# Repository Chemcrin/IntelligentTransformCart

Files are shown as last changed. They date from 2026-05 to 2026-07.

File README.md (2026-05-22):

# 智能物流小车

基于 STM32 + 树莓派的智能物流小车项目，集成多种传感器与机械结构，实现自主导航与物料搬运功能。

## 目录结构

```
├── 代码/                 # STM32固件代码、传感器驱动、技术手册
│   ├── 陀螺仪uart/       # JY61P陀螺仪UART驱动代码
│   ├── vibe_coding/      # 姿态模块、树莓派视觉、麦轮框架设计资料
│   └── *.md              # 技术手册与设计文档
├── pi/                   # 树莓派3D模型 (SLDPRT/SLDASM/STEP)
├── PCB/                  # PCB设计文件
├── 三合一/               # 三合一模块相关文件
├── 历史建模存档/         # 旧版3D模型备份
├── 项目资料包/           # 项目参考资料
├── *.SLDPRT / *.SLDASM   # SolidWorks 机械结构模型
├── LICENSE               # MIT 许可证
└── README.md             # 本文件
```

## 硬件平台

- **主控**：STM32 系列微控制器
- **协处理器**：树莓派 4B
- **传感器**：JY61P 陀螺仪、ATK-MS53L1M 激光测距
- **执行机构**：ZDT X57 V2 步进闭环电机（Modbus-RTU）
- **机械结构**：底盘、料盘、机械臂、方形料框

## 软件架构

- **STM32 固件**：传感器数据采集、电机控制、I2C/UART 通信
- **树莓派端**：视觉识别、上位机调度
- **通信协议**：I2C (TCA9548A)、UART、Modbus-RTU

## 许可证

本项目采用 MIT 许可证。详见 [LICENSE](./LICENSE) 文件。

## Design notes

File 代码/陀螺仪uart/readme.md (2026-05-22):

# JY61P 六轴姿态传感器 UART 驱动

STM32F103C8T6 + HAL 库, 通过串口读取 JY61P 陀螺仪数据。

## 硬件连接

| JY61P 引脚 | STM32 引脚  | 功能 |
|---|---|---|
| VCC | 3.3V | 供电 |
| GND | GND | 地 |
| RX | PB10 | USART3_TX |
| TX | PB11 | USART3_RX |
| SCL | PB6 | 本驱动未使用 |
| SDA | PB7 | 本驱动未使用 |

## 快速开始

### 1. CubeMX 配置

- **USART3**: PB10=TX, PB11=RX, **115200-8-N-1**, NVIC 开启 USART3 全局中断
- 可选 USART1 (PA9=TX, 115200) 用于 printf 调试
- SysTick 必须开启

### 2. 添加文件

- `jy61p.h` → `Inc/`
- `jy61p.c` → `Src/`

### 3. 修改 main.c

```c
#include "jy61p.h"

extern UART_HandleTypeDef huart3;

/* 必须加入此回调 */
void HAL_UART_RxCpltCallback(UART_HandleTypeDef *huart)
{
    if (huart->Instance == USART3) {
        static uint8_t ch;
        HAL_UART_Receive_IT(huart, &ch, 1);
        JY61P_FeedByte(ch);
    }
}

int main(void)
{
    HAL_Init();
    SystemClock_Config();
    MX_GPIO_Init();
    MX_USART3_UART_Init();

    JY61P_StartRecv(&huart3);   /* 启动接收 */

    while (1) {
        float roll, pitch, yaw;
        if (JY61P_GetAngle(&roll, &pitch, &yaw)) {
            /* roll, pitch, yaw 为角度值(°) */
        }
        HAL_Delay(10);
    }
}
```

## UART 协议说明

模块上电后以 **100Hz** 速率主动输出数据包, 每包 **11 字节**:

| 偏移 | 内容 |
|---|---|
| 0 | 0x55 帧头 |
| 1 | 类型: 0x51=加速度, 0x52=角速度, 0x53=姿态角 |
| 2~9  | 4 个 int16 (小端): 3 轴数据 + 温度 |
| 10 | 校验和 (前 10 字节之和的低 8 位) |

转换公式: `实际值 = 原始值 / 32768 × 量程`

| 类型 | 量程 | 单位 |
|---|---|---|
| 加速度 | ±16 | g |
| 角速度 | ±2000 | °/s |
| 姿态角 | ±180 | ° |

## API 参考

### 初始化

| 函数 | 说明 |
|---|---|
| `JY61P_UART_Init(&huart)` | 手动初始化 USART3 (CubeMX 已生成则跳过) |
| `JY61P_StartRecv(&huart)` | 启动中断接收, 调用一次 |

### 数据读取

| 函数 | 说明 |
|---|---|
| `JY61P_Ready()` | 返回就绪标志位 |
| `JY61P_GetData(&data)` | 取出全部数据 |
| `JY61P_GetAngle(&r, &p, &y)` | 仅取姿态角, 返回 1=有新数据 |

### 配置

| 函数 | 说明 |
|---|---|
| `JY61P_ZeroYaw(&huart)` | Z 轴归零 |
| `JY61P_Calibrate(&huart)` | 加速度计校准 |

### 数据结构

```c
typedef struct {
    float ax, ay, az;       /* 加速度 (g)   */
    float gx, gy, gz;       /* 角速度 (°/s) */
    float roll, pitch, yaw; /* 姿态角 (°)   */
    float temp;             /* 温度 (°C)    */
} JY61P_Data;
```

## 注意事项

- **USART3 中断必须开启**, 否则 `HAL_UART_RxCpltCallback` 不会触发
- **Z 轴漂移**: 6 轴传感器无磁力计, Yaw 由角速度积分得出, 长时间运动后漂移; Roll/Pitch 有重力约束不会漂移
- **配置寄存器**如需精确控制回传速率等参数, 建议用 PC 端 WitMotion 上位机软件配置后保存到模块 Flash
- 若模块无输出, 检查波特率是否为 115200 (部分旧版固件默认 9600)

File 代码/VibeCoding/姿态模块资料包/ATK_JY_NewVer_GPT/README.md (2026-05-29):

# ATK_JY_NewVer_GPT

STM32F103C8T6 / STM32C8T6 传感器姿态与距离感知代码包。

- JY61P：I2C1 读取姿态、角速度、加速度，含上电静止校准、yaw 互补滤波、车体系映射。
- ATK-MS53L1M / VL53L1X：I2C1 读取距离，含中值滤波、滑动平均、跳变剔除、近距离优先。
- Board App：提供 `Board_App_Init()`、`Board_App_Loop()`、`SENSOR_Snapshot_t` 快照。

导入和 IOC 配置见：`Docs/项目说明_导入与IOC配置.md`。

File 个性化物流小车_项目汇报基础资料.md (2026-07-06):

# 个性化物流小车——项目汇报基础资料

> 本文档基于项目推进过程资料、技术文档、工程审查报告及多个版本的代码迭代整理而成，用于指导后续 PPT 制作。
> 整理时间：2026-07-05 | 整理人：星尘光 StaRacy

---

## 一、项目概述

### 1.1 项目名称
智能物流搬运小车（个性化物流小车 / Intelligent Transform Cart）

### 1.2 项目定位
基于 STM32 + 树莓派的智能物流小车，实现自主导航与物料搬运功能，面向物流仓储场景的智能化解决方案。

### 1.3 硬件平台总览

| 模块 | 型号/规格 | 接口方式 | 功能定位 |
|---|---|---|---|
| **主控 MCU** | STM32F103C8T6 | — | 底层运动控制、传感器数据采集、电机驱动 |
| **协处理器** | Raspberry Pi 4B | USART2（通过 CH340N） | 视觉识别、上位机调度、路径规划 |
| **底盘电机 ×4** | ZDT-X42-V2 闭环步进电机 | RS485 / Modbus-RTU（USART1） | 四轮独立驱动 |
| **轮组** | 75mm 麦克纳姆轮（X 形布局） | — | 全向移动 |
| **姿态传感器** | JY61P 陀螺仪 / IMU | I2C1 | 航向角测量、直线纠偏 |
| **激光测距** | ATK-MS53L1M / VL53L1X | I2C1 | 避障与距离检测（项目后期移除） |
| **通信** | RS485 半双工总线 + USART1 | — | 电机 Modbus 通信 |
| **调试/控制** | USART2（CH340N → TypeC） | — | 树莓派上下位机通信 |

### 1.4 软件架构概览

```
┌─────────────────────────────────────────────────┐
│                  主循环 (10ms)                    │
├─────────────────────────────────────────────────┤
│  传感器读取 → IMU 更新 → 路线执行 → 电机下发      │
│  (sensors.c)  (imu_app.c)  (competition_route.c) │
│                        → (chassis_control.c)     │
│                        → (mecanum_kinematics.c)   │
│                        → (motor_manager.c)       │
│                        → (zdt_x42_modbus.c)      │
│                        → (modbus_rtu.c)          │
└─────────────────────────────────────────────────┘
```

项目采用**模块化分层设计**，从高层次到底层依次为：

1. **路线执行层**（`competition_route`）：按预设步骤执行路径
2. **底盘控制层**（`chassis_control`）：航向修正、速度规划
3. **运动学层**（`mecanum_kinematics`）：麦轮正/逆运动学解算
4. **电机管理层**（`motor_manager`）：四电机命令缓存与调度
5. **协议层**（`zdt_x42_modbus` + `modbus_rtu`）：Modbus 帧封装与 RS485 收发

---

## 二、项目推进过程

### 第一阶段：项目启动与硬件选型（2026-05-22 前）

- 确定项目方向：物流搬运场景的智能小车
- 硬件选型：STM32F103C8T6 主控、树莓派 4B、ZDT-X42-V2 步进电机、麦克纳姆轮
- 建立项目目录结构，初始化 Git 仓库
- 完成核心传感器（JY61P 陀螺仪、ATK-MS53L1M 激光）的技术调研

### 第二阶段：基础驱动开发与传感器驱动（2026-05-22 ~ 2026-05-29）

- 完成 JY61P 陀螺仪 UART 驱动开发与验证
- 完成 ATK-MS53L1M / VL53L1X 激光测距驱动移植
- 建立传感器数值读取框架
- 完成硬件平台技术手册 V1~V3 迭代

**关键节点：**
- v0.1.0（2026-05-22）：项目初始化，陀螺仪 UART 驱动、PCB 目录搭建
- v0.1.1（2026-05-29）：代码重构，新增 STM32 传感器驱动库，麦轮运动学框架

### 第三阶段：麦轮底盘控制开发（2026-05-29 ~ 2026-06-09）

- 完成麦轮逆运动学解算模块（`mecanum_kinematics.c`）
- 完成 ZDT 电机 Modbus-RTU 协议封装（`zdt_x42_modbus.c`）
- 完成四电机管理与同步控制（`motor_manager.c`）
- 完成底盘控制调度层（`chassis_control.c`）
- 完成直线闭环 PID 控制器

**此阶段遇到的主要困难：**

| 问题 | 表现 | 解决方案 |
|---|---|---|
| USART 分配错误 | 电机驱动被误分配到 USART3，与 PCB 硬件设计（USART1）不符 | 审查后全部迁移到 USART1 |
| 系统时钟配置错误 | 未启用 PLL，系统时钟仅运行在 8MHz（理论最高 72MHz） | 后续需改为 HSE+PLL=72MHz |
| RS485 方向控制 | 开发板未引出方向控制 GPIO 引脚 | 保持硬件自动收发模式，不添加 GPIO 控制 |
| 电机反馈读取为空 | `MotorManager_UpdateFeedback()` 函数为空实现 | 后续依据"只发不收"策略移除空函数 |

### 第四阶段：工程审查与修复（2026-06-09 ~ 2026-06-17）

- 第一轮项目审查（2026-06-09）：发现 USART 分配错误、时钟配置问题、栈空间不足等
- 第二轮项目审查（2026-06-09）：修复 USART1 迁移，调整参数
- 第三轮工程纠错（2026-06-16~17）：工程变量规范化，移除测试残留

**主要变更：**
- 电机串口从 USART3 迁移至 USART1（与 PCB 硬件一致）
- 移除临时测试模块（`uart3_sensor_stream_temp`、`bringup_mode`）
- 新增 CSV 数据调试输出功能
- 新增树莓派远程命令协议框架
- 文档统一与工程简化

### 第五阶段：固定路线与功能集成（2026-06-17 ~ 当前）

- 完成固定路线执行模块（`competition_route`）
- 实现 12 步比赛路线（前进、横移、旋转、停止）
- 新增 IMU 辅助直线纠偏功能
- 移除激光模块（由于编译依赖问题及硬件限制）
- 实现串口信号共享调试

**当前最新工程状态：**
- 最新工程版本：`smart_logistics_car_integrated_route_2026-06-17`
- 运行模式：`FIXED_ROUTE_STANDALONE_ENABLE = 1U`（独立固定路线模式）
- 路线控制：开环时间控制（后续可升级为 IMU 闭环旋转）

---

## 三、现有可实现功能

### 3.1 基础运动功能 ✅

| 功能 | 状态 | 说明 |
|---|---|---|
| 上电自动运行固定路线 | **可用** | 200ms 启动等待后自动开始 |
| 前进 | **可用** | 默认 0.18 m/s |
| 后退 | **可用** | 默认 0.18 m/s |
| 左/右横移 | **可用** | 默认 0.14 m/s |
| 原地旋转 | **可用** | 开环时间控制，默认 0.45 rad/s |
| 停止 | **可用** | 路线结束或手动停止 |
| 四轮速度解算 | **可用** | 麦轮逆运动学，等比限幅 |
| 四电机同步使能与速度下发 | **可用** | Modbus 单播 + 广播同步触发 |

### 3.2 传感器与闭环功能 ⚡

| 功能 | 状态 | 说明 |
|---|---|---|
| JY61P 陀螺仪读取 | **代码就绪，当前独立模式下未启用** | 支持 yaw/pitch/roll、三轴加速度、三轴角速度 |
| IMU 软件零偏校准 | **代码就绪** | 静止 200 样本自动校准 |
| IMU 航向融合 | **代码就绪** | 陀螺积分 + 模块 yaw 互补修正 |
| 直线航向纠偏 | **部分启用** | 新增直线段 yaw 闭环纠偏 |
| 激光测距 | **已移除** | 因编译依赖和硬件限制移除 |
| 电机速度反馈 | **已放弃** | 硬件 RS485 不支持接收，改为"只发不收"策略 |

### 3.3 通信与控制功能 📡

| 功能 | 状态 | 说明 |
|---|---|---|
| Modbus-RTU 电机控制 | **可用** | 发送使能、速度、停止指令 |
| CSV 串口调试输出 | **可用** | 10Hz 全量传感器数据流 |
| 树莓派遥控协议 | **代码就绪** | USART2 命令协议：VEL、STOP、STAT?、IMU? 等 |
| 传感器快照系统 | **可用** | 统一传感器数据接口 `Sensor_GetSnapshot()` |

---

## 四、独具特色功能

### 4.1 麦克纳姆轮全向移动

采用 X 形布局麦克纳姆轮，配合精确的逆运动学解算（`Mecanum_InverseKinematics`），实现：

- **前进/后退**：四轮同向同速
- **左右横移**：前后轮差速
- **原地旋转**：对角同向、同侧反向
- **任意矢量运动**：任意方向平移 + 旋转的复合运动

**关键技术参数：**
- 轮径：75mm
- 轮距：320mm
- 轴距：220mm
- 最大平移速度：0.60 m/s
- 最大旋转角速度：1.50 rad/s
- 加速度限制：2000 RPM/s

### 4.2 Y 轴速度规划与路线

代码中包含完整的固定路线规划，支持：
- **直线前进/后退距离控制**：速度 × 时间换算
- **横移/斜向运动**：vx/vy 任意比例组合
- **原地旋转角度控制**：开环时间控制
- **复合运动**：平移 + 旋转可同时叠加

### 4.3 模块化传感器架构

项目的传感器驱动采用分层设计，具有良好可扩展性：

```
传感器硬件驱动层（jy61p.c / atk_ms53l1m.c）
        ↓
传感器应用层（imu_app.c / laser_app.c）
        ↓
传感器集成层（sensors.c） → Sensor_GetSnapshot()
        ↓
传感器桥接层（sensor_bridge.c）→ 统一数据类型
```

这种架构使更换传感器或增减模块非常方便，仅需修改对应驱动文件即可。

### 4.4 实时 CSV 调试数据流

项目提供了独立的 CSV 调试数据输出功能，可通过 USART1 实时回传以下数据：

```
时间戳(ms), 加速度X(g), 加速度Y(g), 加速度Z(g),
角速度X(dps), 角速度Y(dps), 角速度Z(dps),
Roll(°), Pitch(°), Yaw(°)
```

- 输出频率：10Hz（不干扰主控制周期）
- 条件编译控制：`CSV_DEBUG_ENABLE` 一键开关
- 可用于示波器、Excel 导入或上位机实时可视化

### 4.5 软件定义的控制模式切换

通过宏定义实现灵活的控制模式切换：

| 宏开关 | 作用 |
|---|---|
| `FIXED_ROUTE_STANDALONE_ENABLE` | 独立固定路线模式 / 完整传感器+树莓派模式 |
| `COMPETITION_ROUTE_AUTO_START` | 上电自动启动 / 等待外部信号启动 |
| `COMPETITION_ROUTE_USE_IMU_ROTATION` | 旋转开环时间控制 / IMU 闭环角度控制 |
| `CSV_DEBUG_ENABLE` | 调试数据流开启/关闭 |

---

## 五、项目推进过程中遇到的困难与解决方案

### 5.1 硬件层面

| 困难 | 表现 | 解决方案 |
|---|---|---|
| **RS485 半双工只有发送能力** | 硬件未引出 RS485 方向控制 GPIO，无法接收电机状态回传 | 采用"只发不收"开环控制策略，放弃电机反馈读取 |
| **激光模块编译依赖缺失** | VL53L1X API 库未纳入工程，导致编译错误 | 移除激光模块，取消激光避障/急停保护 |
| **开发板 C 口连接 UART2** | TypeC 接口通过 CH340N 连接到 USART2，非直连 | 配置 USART2 与树莓派通信，波特率 115200 |

### 5.2 软件层面

| 困难 | 表现 | 解决方案 |
|---|---|---|
| **USART 分配错误** | 电机驱动代码被错误分配至 USART3，与 PCB（USART1）不符 | 审查后迁移至 USART1，确保与硬件一致 |
| **系统时钟 8MHz** | 未配置 PLL，CPU 仅运行在 1/9 理论性能 | 后续需改为 HSE+PLL=72MHz |
| **上电自动行驶安全隐患** | Standalone 模式下 200ms 后自动启动路线 | 开发调试时关闭 AUTO_START，比赛时开启 |
| **栈空间不足** | 链接脚本仅分配 1024 字节栈空间 | 增大至 2048 字节 |
| **多套传感器快照结构冗余** | `SENSOR_Snapshot_t` 与 `SensorSnapshot_t` 重复 | 可统一为一套结构体 |
| **Vibe Coding 代码质量问题** | 部分提示词生成的代码存在逻辑瑕疵 | 通过多轮工程审查+修复的方式持续改进 |

### 5.3 工程管理层面

| 困难 | 表现 | 解决方案 |
|---|---|---|
| **文档版本不统一** | 多个版本的硬件手册、设计文档并行 | 统一使用 V3 版硬件手册作为最高标准 |
| **临时测试模块残留** | `uart3_sensor_stream_temp`、`bringup_mode` 等模块未清理 | 审查后逐一清理，干净工程归档 |
| **变量命名不规范** | 不同模块中变量命名风格不一 | 生成工程变量总览文档，后续统一规范 |

---

## 六、项目成果总结

### 6.1 完成度评估

| 维度 | 完成度 | 说明 |
|---|---|---|
| 底盘运动控制 | **90%** | 麦轮运动学、四电机同步、速度规划已完成 |
| 传感器系统 | **70%** | IMU 驱动就绪、闭环纠偏部分启用；激光已移除 |
| 通信链路 | **60%** | Modbus 电机控制已完成；树莓派协议代码就绪但未完全联调 |
| 路线执行 | **85%** | 固定路线按时间控制可用，暂未启用 IMU 闭环旋转 |
| 功能调试 | **75%** | CSV 调试、工程审查、参数调优基本完成 |

### 6.2 可展示亮点

1. **四轮独立控制**：四个 ZDT-X42-V2 步进电机通过 RS485 总线独立寻址、同步控制
2. **全向移动能力**：麦克纳姆轮配合精确运动学解算，实现任意方向平移和原地旋转
3. **模块化软件架构**：传感器→控制→通信严格分层，代码可维护性强
4. **丰富的调试手段**：CSV 数据流、状态回传、串口命令调试
5. **完整的版本控制**：Git 全程追踪，CHANGELOG 定期维护

### 6.3 待完善方向

1. **系统时钟修复**：启用 HSE + PLL 至 72MHz
2. **IMU 闭环旋转**：启用 `COMPETITION_ROUTE_USE_IMU_ROTATION`，提高旋转精度
3. **树莓派联调**：完成 USART2 命令协议的全链路验证
4. **场地实测**：在实际比赛场地上标定路线参数
5. **视觉识别集成**：通过树莓派摄像头实现物料识别与定位

---

## 七、附录：目录结构与关键文件索引

### 项目源码目录（主要部分）

```
smart_logistics_car_integrated/
├── Core/
│   ├── Inc/                    # 头文件
│   │   ├── config.h            # 全局配置宏
│   │   ├── mecanum.h           # 麦轮 API
│   │   ├── mecanum_kinematics.h # 运动学解算
│   │   ├── mecanum_config.h    # 运动参数配置
│   │   ├── mecanum_types.h     # 数据类型定义
│   │   ├── chassis_control.h   # 底盘控制
│   │   ├── motor_manager.h     # 电机管理
│   │   ├── modbus_rtu.h        # Modbus 协议
│   │   ├── zdt_x42_modbus.h    # ZDT 电机协议
│   │   ├── jy61p.h             # JY61P 驱动
│   │   ├── imu_app.h           # IMU 应用层
│   │   ├── sensors.h           # 传感器集成
│   │   ├── sensor_bridge.h     # 传感器桥接
│   │   └── straight_control.h  # 直线闭环控制
│   └── Src/                    # 源文件
│       ├── main.c              # 主程序入口
│       ├── mecanum_kinematics.c
│       ├── mecanum.c
│       ├── chassis_control.c
│       ├── motor_manager.c
│       ├── modbus_rtu.c
│       ├── zdt_x42_modbus.c
│       ├── jy61p.c
│       ├── imu_app.c
│       ├── sensors.c
│       ├── sensor_bridge.c
│       └── straight_control.c
├── UserModules/
│   ├── competition_route/      # 固定路线执行器
│   └── remote_cmd/             # 树莓派远程命令协议
├── Drivers/
│   └── VL53L1X/                # VL53L1X API（已被移除）
├── Docs/                       # 项目文档
├── Templates/                  # 代码模板
└── Debug/                      # 编译输出
```

### 关键文档索引

| 文档 | 位置 | 用途 |
|---|---|---|
| README.md | 项目根目录 | 项目简介与目录结构 |
| CHANGELOG.md | 项目根目录 | 版本更新记录 |
| 硬件平台技术手册 V3 | `代码/` | 硬件设计最高标准 |
| 麦轮运动控制系统设计文档 5Pro | `代码/` | 运动控制系统详细设计 |
| 工程审查报告 2026-06-09 | `VibeCoding/工程纠错/` | 第一轮代码审查 |
| 智能物流小车工程审查报告 | `VibeCoding/Docs/` | 第二轮详细审查 |
| 628 问题审查 | `VibeCoding/工程纠错/` | 工程现状与问题梳理 |
| 629 工程整改指南 | `VibeCoding/工程纠错/` | 问题修复指导 |
| 工程变量总览 2026-06-16 | `VibeCoding/工程纠错/` | 变量命名规范 |

---

*本文档由星尘光 StaRacy 于 2026-07-05 整理，基于项目推进过程资料、多个版本的技术文档与工程审查报告综合编写。*

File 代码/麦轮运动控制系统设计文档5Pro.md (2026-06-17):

# 麦轮运动控制系统技术设计文档

项目：智能物流搬运小车移动系统  
平台：STM32C8T6，STM32CubeIDE，HAL 库  
执行器：4 × ZDT-X42-V2 闭环步进电机，RS485 总线，Modbus-RTU 速度控制  
传感器：JY61P 陀螺仪，ATK-MS53L1M 激光测距传感器  
版本：V1.0

---

## 0. 文档目标与设计边界

本文档回答移动系统开发中最关键的工程问题：

1. **4 个电机共用一条 RS485 总线时如何区分和同步控制？**
2. **不使用 PWM、只用 Modbus 速度寄存器时，主控侧闭环应如何设计？**
3. **X 形麦克纳姆轮如何从小车期望速度分解到 4 个电机 RPM？**
4. **如何利用 JY61P 和 ATK-MS53L1M 提升直线、转向和到达目标的稳定性？**
5. **STM32 HAL 工程如何划分外设、任务周期、通信优先级和安全停机逻辑？**

本文档不输出完整可编译 C 源码，但给出后续实现需要的寄存器、帧结构、函数原型、伪代码、状态机和关键参数。

### 0.1 资料依据与一致性说明

压缩包中电机资料包括：

- `电机相关资料/说明书/ZDT_X57_V2 Modbus-RTU指令说明.pdf`
- `电机相关资料/说明书/ZDT_X57_V2步进闭环驱动说明书Rev1.0.pdf`
- `电机相关资料/STM32F1例程/串口_RS232_RS485通讯控制`

虽然 PDF 文件名为 `ZDT_X57_V2`，说明书封面明确标注 **X28 / X35 / X42 / X57 通用**，因此可作为 ZDT-X42-V2 通信与控制设计依据。

资料中与本项目直接相关的配置点：

| 项目 | 结论 |
| --- | --- |
| 通信方式 | RS485，总线式半双工 |
| 协议 | Modbus-RTU，需在驱动器 `Checksum` 菜单选择 `Modbus` |
| 波特率 | 默认 115200，8N1；可在 `UartBaud` 菜单修改 |
| 通信端口复用 | `P_Serial` 菜单需设为 `UART_FUN` |
| 地址 | 默认地址 1，可设 1-255，0 为广播地址 |
| 接线 | PA9(TX)、PA10(RX) 通过 RS485 模块连接；驱动器端 `R/A/H` 接 RS485 A，`T/B/L` 接 RS485 B；按驱动器实物丝印/手册最终核对 |
| 控制方式 | 不使用 PWM；速度、使能、停止、同步触发均通过 Modbus 寄存器完成 |

> 注意：官方例程中有提醒“两条命令之间发送需要延迟 1-10 ms”。对 Modbus-RTU 来说标准帧间隔只要求大于 3.5 个字符时间，但工程实现建议保守加入 1-2 ms 总线保护间隔，调试稳定后再缩短。

### 0.2 机械参数

| 参数 | 符号 | 数值 |
|---|---:|---:|
| 麦克纳姆轮直径 | `D` | 75 mm = 0.075 m |
| 麦克纳姆轮半径 | `r = D / 2` | 37.5 mm = 0.0375 m |
| 单轮厚度 | - | 33 mm |
| 左右轮中心间距 / 轮距 | `W` | 320 mm = 0.320 m |
| 前后轮中心间距 / 轴距 | `L` | 220 mm = 0.220 m |
| 麦轮旋转耦合臂长 | `K = (L + W) / 2` | 0.270 m |
| 轮周长 | `C = πD` | 0.23562 m |

这里将用户给出的轮距、轴距视为左右轮接触中心、前后轮接触中心之间的距离。若后续机械测量发现轮距定义不是轮接触中心距，应重新修正 `W`，否则旋转角速度分解会有比例误差。

---

## 1. 问题一：4 个电机共用一条 RS485 总线，如何寻址和同步？

### 1.1 总线上的 4 个电机如何区分？

RS485 只是物理层，不能自动区分设备。4 个电机在同一条 RS485 总线上共存时，必须依靠 **Modbus-RTU 从机地址**区分目标电机。该机制与 I²C 设备地址类似：主控发送的每一帧都带有 `Slave Address`，只有地址匹配的驱动器响应和执行。

驱动器地址规则：

- 默认地址：`1`
- 可设置范围：`1-255`
- `0`：广播地址，不可设置为电机自身地址
- 广播地址用于让所有驱动器同时接收命令；Modbus 广播不应等待从机回复

建议本项目地址分配如下：

| 轮号 | 位置 | 建议从机地址 | 变量名 |
|---:|---|---:|---|
| 1 | 前左轮 FL | `0x01` | `MOTOR_ADDR_FL` |
| 2 | 前右轮 FR | `0x02` | `MOTOR_ADDR_FR` |
| 3 | 后左轮 RL | `0x03` | `MOTOR_ADDR_RL` |
| 4 | 后右轮 RR | `0x04` | `MOTOR_ADDR_RR` |

#### 地址设置方法

优先使用驱动器 OLED 菜单逐台设置：

1. 只给第 1 个电机上电，进入 `ID_Addr`，设为 `1`。
2. 只给第 2 个电机上电，设为 `2`。
3. 只给第 3 个电机上电，设为 `3`。
4. 只给第 4 个电机上电，设为 `4`。
5. 全部接入总线后，主控分别读取 1-4 地址验证通信。

如果使用 Modbus 修改地址，必须保证总线上同一时刻只有一个默认地址相同的电机在线，否则多个默认地址 `1` 的电机会同时响应，导致总线冲突。修改地址寄存器如下：

| 功能 | 功能码 | 起始寄存器 | 寄存器数量 | 数据格式 |
|---|---:|---:|---:|---|
| 修改 ID 地址 | `0x10` | `0x00A2` | `0x0002` | Reg1=`0x4B + 是否存储`，Reg2=`地址 + 0x00` |

示例：将地址 `1` 修改为 `2` 并存储，帧体为：

```text
01 10 00 A2 00 02 04 4B 01 02 00 CRC_L CRC_H
```

其中 `01` 为“是否存储”。CRC 不建议手工硬编码，应由统一的 Modbus CRC16 函数计算。

---

### 1.2 Modbus-RTU 帧基本结构是什么？

所有 Modbus-RTU 帧采用以下结构：

```text
+-------------+---------------+-------------------+--------------+
| 从机地址     | 功能码          | 数据区              | CRC16        |
| 1 byte      | 1 byte        | N bytes           | CRC_L CRC_H  |
+-------------+---------------+-------------------+--------------+
```

关键规则：

1. CRC 为 Modbus CRC16，多项式 `0xA001`，初值 `0xFFFF`。
2. 帧尾发送顺序是 `CRC_L` 再 `CRC_H`。例如读取 1 号电机实时转速：

```text
01 04 00 44 00 02 31 DE
```

上述帧的 CRC 数值为 `0xDE31`，发送顺序为 `31 DE`。

3. 16 bit 寄存器内部按 Modbus 常规高字节在前，即 `Hi` 后 `Lo`。
4. 资料说明所有 32 bit 数据先传低字、再传高字，主要影响位置角度等 32 bit 字段；速度模式本身只使用 16 bit 速度字段。
5. 本项目主要用到的功能码：

| 功能码 | 含义 | 用途 |
|---:|---|---|
| `0x04` | 读输入寄存器 | 读取实时转速、实时位置、系统状态 |
| `0x06` | 写单个寄存器 | 清零、校准等简单命令，可选 |
| `0x10` | 写多个寄存器 | 速度模式、使能、同步触发、修改参数 |

---

### 1.3 单个电机速度指令如何组织？

速度模式控制使用 `0x10` 写多个寄存器：

| 字段 | 值 |
|---|---:|
| 功能码 | `0x10` |
| 起始寄存器 | `0x00E6` |
| 寄存器数量 | `0x0004` |
| 字节数 | `0x08` |

4 个寄存器含义如下：

| 寄存器 | 含义 | 数据建议 |
|---|---|---|
| Reg1 | 方向 | `0x0000` = CW，`0x0001` = CCW |
| Reg2 | 加速度 | 单位 `RPM/s`，`uint16_t` |
| Reg3 | 速度 | 单位按 Modbus 速度模式表为 `RPM`，`uint16_t` |
| Reg4 | 多机同步标志 + 保留字节 | `0x0000` = 立即执行；`0x0100` = 缓存等待同步触发 |

> 实施校验点：同一份 Modbus 文档在位置模式中明确写明“速度和位置角度要放大 10 倍输入”，而速度模式表只标注 `速度(RPM)`，没有写放大 10 倍。因此本设计对 `0x00E6` 速度模式先按整数 RPM 实现。驱动联调时应做 60 RPM、120 RPM、300 RPM 三点实测；若发现该驱动固件在速度模式也按 0.1 RPM 解析，只需将 `ZDT_SPEED_MODE_SCALE` 从 `1` 改为 `10`，通信与控制架构不变。

单电机速度帧模板：

```text
[Addr] 10 00 E6 00 04 08 [Dir_H] [Dir_L] [Acc_H] [Acc_L] [Spd_H] [Spd_L] [Sync_H] 00 [CRC_L] [CRC_H]
```

示例：1 号电机，CW，目标 `150 RPM`，加速度 `1000 RPM/s`，设置同步缓存标志：

```text
01 10 00 E6 00 04 08 00 00 03 E8 00 96 01 00 BD 14
```

如果不使用同步缓存，最后一个寄存器改为 `00 00`，即收到后立即执行。

---

### 1.4 如何实现四电机同步速度更新？

有两种策略。

#### 策略 A：连续单播，立即生效

主控依次向 1、2、3、4 号电机发送速度命令，Reg4=`0x0000`。每个电机收到后立即更新速度。

优点：实现简单；不需要额外同步触发帧。  
缺点：4 个电机更新存在数毫秒级时间差；在低速直线行驶时通常可接受，在起步、急停、旋转切换时可能造成姿态抖动。

适用场景：

- 低速巡航
- 对严格同步要求不高的速度微调
- 总线负载较高、周期较紧时

#### 策略 B：单播缓存 + 广播同步触发

主控先分别向 1、2、3、4 号电机发送速度命令，Reg4=`0x0100`，让驱动器缓存命令但暂不动作；随后使用广播地址 `0x00` 发送“触发多机同步运动”。

同步触发寄存器：

| 功能 | 功能码 | 起始寄存器 | 数量 | 数据 |
|---|---:|---:|---:|---|
| 触发多机同步运动 | `0x10` | `0x00FF` | `0x0001` | `0x6600` |

广播触发帧：

```text
00 10 00 FF 00 01 02 66 00 94 6F
```

同步控制流程：

```text
1. 写 1 号速度命令，Sync_H = 0x01，等待 1 号响应
2. 写 2 号速度命令，Sync_H = 0x01，等待 2 号响应
3. 写 3 号速度命令，Sync_H = 0x01，等待 3 号响应
4. 写 4 号速度命令，Sync_H = 0x01，等待 4 号响应
5. 用广播地址 0x00 发送 0x00FF 同步触发帧，不等待响应
6. 4 个电机同时执行缓存的速度命令
```

建议：项目默认采用 **策略 B**，在起步、停止、直线-横移-旋转模式切换时保持四轮同步；若实测总线周期不足，再对巡航阶段降级为策略 A。

---

### 1.5 RS485 半双工发送流程如何设计？

RS485 总线半双工意味着同一时刻只能发送或接收。STM32 侧必须用一个 GPIO 控制 RS485 收发器方向，通常为：

- `RS485_DIR = 1`：发送使能，DE=1，/RE=1 或接收关闭
- `RS485_DIR = 0`：接收使能，DE=0，/RE=0

具体电平以实际 RS485 模块为准。文档中不指定该 GPIO 的物理引脚，工程中统一命名为 `RS485_DIR_GPIO`。

发送单帧的软件流程：

```text
Modbus_BuildFrame()
    ↓
等待总线空闲 / 获得 Modbus 总线互斥锁
    ↓
清空 UART1 RX 缓冲区，避免旧数据污染
    ↓
RS485_DIR = TX
    ↓
短延时 t_DE_ON，等待收发器进入发送态
    ↓
HAL_UART_Transmit 或 DMA/IT 发送
    ↓
等待 UART 发送完成，必须等 TC，而不是只等 TXE
    ↓
短延时 1 个字符时间，确保最后一位完全离开总线
    ↓
RS485_DIR = RX
    ↓
若为单播帧：等待响应、校验 CRC、解析返回
若为广播帧：不等待响应
    ↓
帧间保护间隔 t_gap，建议初始 1-2 ms
    ↓
释放总线互斥锁
```

必须避免的错误：

1. **未等待 TC 就切换到接收**：最后 1-2 个字节可能被截断。
2. **发送后仍保持 TX 方向**：从机响应无法进入主控 UART，表现为超时。
3. **多个上层任务同时调用 UART1 发送**：必须通过统一的 Modbus 事务状态机串行化。
4. **广播命令后等待响应**：Modbus 广播没有从机响应，等待会浪费周期甚至误判超时。

---

## 2. 问题二：如何读取电机实时转速，并设计主控侧闭环？

### 2.1 如何读取单个电机实时转速？

读取实时转速使用 `0x04` 功能码：

| 字段 | 值 |
|---|---:|
| 功能码 | `0x04` |
| 起始寄存器 | `0x0044` |
| 寄存器数量 | `0x0002` |
| 返回字节数 | `0x04` |

请求帧模板：

```text
[Addr] 04 00 44 00 02 [CRC_L] [CRC_H]
```

1 号电机示例：

```text
01 04 00 44 00 02 31 DE
```

响应帧结构：

```text
[Addr] 04 04 [Sign_H] [Sign_L] [RPM_H] [RPM_L] [CRC_L] [CRC_H]
```

解析规则：

```text
sign = Reg1        // 0 = 正，1 = 负
rpm_raw = Reg2     // 电机实时转速，单位按资料标注为 RPM
rpm = (sign == 0) ? rpm_raw : -rpm_raw
```

如果联调后确认驱动返回值存在 0.1 RPM 缩放，则统一使用：

```text
rpm = sign * rpm_raw / ZDT_SPEED_FEEDBACK_SCALE
```

其中 `ZDT_SPEED_FEEDBACK_SCALE` 初始为 `1`。

---

### 2.2 如何同时获得 4 个电机当前转速？

单条 RS485 半双工总线上不能真正并行读取 4 个电机；正确方式是 **主控单主机轮询**。只要每次只向一个地址发起读取请求，就不会产生从机响应冲突。

推荐两种读取策略。

#### 策略 A：整组轮询

每个反馈周期按地址 1、2、3、4 依次读取：

```text
ReadSpeed(1) → ReadSpeed(2) → ReadSpeed(3) → ReadSpeed(4)
```

读取完成后得到近似同一时刻的 4 个转速快照。该策略适合启用四轮速度 PI 的场景。

建议周期：

- 四轮速度反馈周期：`40-50 ms`
- 主控制周期：`20 ms`
- 即每 2 个主控制周期完成一次四轮反馈快照

#### 策略 B：分散轮询

每个 `20 ms` 主控制周期只读 1-2 个电机，按轮号循环：

```text
周期 1：读 1、2
周期 2：读 3、4
周期 3：读 1、2
...
```

优点是通信负载更均匀，适合主控侧不强依赖高速轮速 PID、主要依靠驱动器内部闭环和 IMU 航向闭环的场景。

#### 可选：读取系统状态参数

若需要同时获得电压、电流、转速、位置、温度、状态位，可读系统状态参数：

| 功能 | 功能码 | 起始寄存器 | 数量 |
|---|---:|---:|---:|
| 读取系统状态参数 | `0x04` | `0x0078` | `0x0011` |

该帧返回内容更多，适合低频诊断，例如 `5-10 Hz`。控制环中只需要速度时，优先使用 `0x0044`，降低总线占用。

---

### 2.3 主控侧是否需要再做速度 PID？

结论：**默认不做完整的高速电机速度内环 PID；保留低频轮速修正 PI 作为可选功能。**

原因如下：

1. ZDT-X42-V2 是闭环步进驱动器，本身具有电流、速度、位置等闭环能力。主控通过 Modbus 给的是速度目标，不是 PWM 占空比。
2. 如果主控再以很高频率对电机 RPM 做 PID，本质是“外部速度环套内部速度环”，周期又受 RS485 总线限制，容易产生滞后、积分饱和和振荡。
3. 仅使用电机编码器速度反馈，并不能直接检测轮地打滑。车轮打滑时，电机 RPM 可能完全正常，但车体实际位移不正确。打滑更应该由 IMU 航向、激光距离、里程计残差来修正。
4. 主控侧可以做 **低频监督型 PI**：用于校正四轮跟随误差、负载差异、方向标定误差、小幅补偿驱动器响应差异，而不是替代驱动器内部速度环。

推荐闭环层级：

```text
高层任务：前进距离 / 横移距离 / 旋转角度 / 到目标点
        ↓
路径与速度规划：vx_ref, vy_ref, omega_ref
        ↓
航向/位置外环：JY61P + 激光 + 里程计修正 vx, vy, omega
        ↓
麦轮逆运动学：计算四轮 rpm_ref
        ↓
可选低频轮速 PI：rpm_cmd = rpm_ref + delta_rpm
        ↓
Modbus 速度命令写入 ZDT 驱动器
        ↓
驱动器内部闭环：电流/速度/位置控制
        ↓
读取电机 rpm_fb，供监督 PI、里程计和故障诊断使用
```

### 2.4 可选轮速 PI 控制框图

```mermaid
flowchart LR
    A[期望车体速度 vx, vy, omega] --> B[麦轮逆运动学]
    B --> C[四轮期望 rpm_ref]
    C --> D[低频轮速 PI，可选]
    E[读取四轮 rpm_fb] --> D
    D --> F[限幅与斜率限制]
    F --> G[Modbus 写速度寄存器 0x00E6]
    G --> H[ZDT-X42-V2 内部速度闭环]
    H --> I[电机与麦轮]
    I --> E
```

可选 PI 公式：

```text
e_i(k) = rpm_ref_i(k) - rpm_fb_i(k)   // RPM
I_i(k) = clamp(I_i(k-1) + e_i(k) * T_pid, I_min, I_max)
delta_i = Kp * e_i(k) + Ki * I_i(k)
rpm_cmd_i = clamp(rpm_ref_i + delta_i, -RPM_LIMIT, RPM_LIMIT)
```

工程建议：

- 初期只使用 `Kp`，`Ki = 0`。
- `delta_i` 限制在 `±10%` 到 `±20%` 的 `rpm_ref_i` 范围内，避免主控 PI 与驱动器内部速度环对抗。
- 当 `|rpm_ref_i|` 很小，例如接近 0 时，禁用积分，直接下发 0 RPM，避免低速抖动。
- 若通信周期大于 50 ms，不建议使用激进 PI 参数。

### 2.5 PID 控制周期如何选择？

推荐初始周期如下：

| 控制/采样项 | 建议周期 | 说明 |
|---|---:|---|
| 主运动控制周期 | `20 ms` | 50 Hz；计算速度规划、航向修正、麦轮分解 |
| 四轮速度反馈快照 | `40-50 ms` | 每 2 个主周期读完 4 个电机；用于监督 PI 和里程计 |
| 轮速 PI 周期 | `40-50 ms` | 与四轮反馈快照对齐 |
| JY61P 航向控制 | `10-20 ms` | 优先使用最新 yaw / gyro_z |
| 激光距离修正 | `50-100 ms` | 取决于传感器更新率和安装方式 |
| 电机状态诊断 | `100-200 ms` | 电流、电压、温度、状态位低频读取 |

如果后续总线优化到 DMA + 中断 + 较短帧间隔，并且实测电机响应稳定，可将四轮速度反馈周期缩短到 20-30 ms；否则不建议为了轮速 PID 占满总线。

### 2.6 转速反馈滤波与异常值处理

实时转速反馈进入控制或里程计前必须做校验和滤波。

#### 数据有效性检查

单个电机反馈满足以下条件才更新：

1. 地址匹配。
2. 功能码匹配；若收到 `function | 0x80`，按 Modbus 异常处理。
3. 字节数正确。
4. CRC 正确。
5. 符号寄存器只允许 `0` 或 `1`。
6. 转速未超过配置的 `RPM_LIMIT` 或驱动器最大速度限制。
7. 与上一有效值的差值不超过物理加速度约束：

```text
abs(rpm_now - rpm_last) <= ACC_LIMIT_RPM_S * dt * margin
```

其中 `margin` 可取 `1.5-2.0`，用于容忍瞬时响应。

#### 滤波策略

建议使用一阶 IIR 低通：

```text
rpm_filt(k) = alpha * rpm_raw(k) + (1 - alpha) * rpm_filt(k-1)
```

`alpha` 初始取 `0.3-0.5`。如果反馈抖动较大，可加入 3 点中值滤波，但不要引入过大延迟。

#### 超时处理

| 情况 | 处理 |
|---|---|
| 单次读取超时 | 保持上一有效值，不立即停机 |
| 连续 3 次超时 | 标记该电机通信故障，整车进入减速停机 |
| CRC 错误频繁 | 降低总线频率、增大帧间隔、检查 A/B 接线和终端匹配 |
| 地址冲突 | 多个驱动器可能默认地址相同，必须逐台隔离重新设置地址 |

---

## 3. 问题三：X 形麦克纳姆轮如何进行速度分解？

### 3.1 坐标系、轮序号与正方向定义

本文采用车体坐标系：

- `+x`：车体前方
- `+y`：车体左方
- `+z`：竖直向上
- `+ω`：绕 `+z` 逆时针旋转，即从上往下看逆时针

轮序号：

```text
             +x 前方

        1:FL          2:FR
        前左          前右

              车体中心 O ---- +y 左方

        3:RL          4:RR
        后左          后右
```

麦克纳姆轮采用 X 形布局。本文定义 **正轮速** 为“该轮单独正转时，其对车体的贡献方向与整车前进方向一致”。由于电机实际安装方向、减速结构、接线方向可能不同，最终下发到驱动器的 CW/CCW 必须通过每轮方向系数标定：

```text
motor_dir_sign[i] = +1 或 -1
```

调试时逐个给每个电机低速正转，观察车轮切向是否符合本文正轮速定义；不符合则反转该轮的软件方向系数，而不要修改运动学公式。

### 3.2 逆运动学方程

设小车中心期望速度为：

```text
v_x      车体坐标系前向速度，m/s
v_y      车体坐标系左向速度，m/s
omega    车体绕 z 轴角速度，rad/s
```

定义：

```text
K = (L + W) / 2
```

四个轮子的目标线速度为：

```text
v_1 = v_x - v_y - K * omega      // 前左 FL
v_2 = v_x + v_y + K * omega      // 前右 FR
v_3 = v_x + v_y - K * omega      // 后左 RL
v_4 = v_x - v_y + K * omega      // 后右 RR
```

矩阵形式：

```text
[ v_1 ]   [ 1  -1  -K ] [ v_x   ]
[ v_2 ] = [ 1   1   K ] [ v_y   ]
[ v_3 ]   [ 1   1  -K ] [ omega ]
[ v_4 ]   [ 1  -1   K ]
```

将轮线速度转换为电机目标转速：

```text
rpm_i = v_i / (π * D) * 60      // 单位: RPM
```

其中 `D = 0.075 m`。

### 3.3 正运动学与里程计

读取到四轮实际 RPM 后，先转换为轮线速度：

```text
v_i = rpm_i * (π * D) / 60      // 结果: m/s
```

在同一套符号定义下，车体速度可估计为：

```text
v_x_est   = ( v_1 + v_2 + v_3 + v_4 ) / 4
v_y_est   = (-v_1 + v_2 + v_3 - v_4 ) / 4
omega_est = (-v_1 + v_2 - v_3 + v_4 ) / (4 * K)
```

里程计积分时，建议使用 JY61P 的航向角替代纯轮速积分出来的 `theta`，因为麦轮横移和打滑会让轮速里程计的航向误差积累很快。

全局坐标积分：

```text
v_x_global = cos(theta) * v_x_est - sin(theta) * v_y_est
v_y_global = sin(theta) * v_x_est + cos(theta) * v_y_est

x = x + v_x_global * dt
y = y + v_y_global * dt
theta = yaw_from_JY61P
```

### 3.4 从全局速度到车体速度

如果上层规划器输出的是全局坐标速度 `(v_x_g, v_y_g)`，需要用当前航向 `theta` 转换到车体坐标系：

```text
v_x_b =  cos(theta) * v_x_g + sin(theta) * v_y_g
v_y_b = -sin(theta) * v_x_g + cos(theta) * v_y_g
omega_b = omega_g
```

然后将 `(v_x_b, v_y_b, omega_b)` 送入逆运动学。

### 3.5 函数原型设计

建议使用如下抽象，后续可直接落到 C 文件中：

```c
// 伪代码：类型名仅用于说明，不代表最终完整 C 实现

typedef struct {
    float vx;       // m/s，若 field_oriented=true 表示全局 x 速度，否则表示车体 x 速度
    float vy;       // m/s
    float omega;    // rad/s
} ChassisVel_t;

typedef struct {
    float wheel_rpm[4];     // FL, FR, RL, RR，单位: RPM
} WheelRpm_t;

void Mecanum_InverseKinematics(
    const ChassisVel_t *cmd,
    float yaw_rad,
    bool field_oriented,
    float rpm_limit,
    WheelRpm_t *out
);
```

### 3.6 逆运动学伪代码

```c
function Mecanum_InverseKinematics(cmd, yaw_rad, field_oriented, rpm_limit):
    D = 0.075
    L = 0.220
    W = 0.320
    K = (L + W) / 2.0

    if field_oriented:
        vx =  cos(yaw_rad) * cmd.vx + sin(yaw_rad) * cmd.vy
        vy = -sin(yaw_rad) * cmd.vx + cos(yaw_rad) * cmd.vy
    else:
        vx = cmd.vx
        vy = cmd.vy

    omega = cmd.omega

    wheel_v[FL] = vx - vy - K * omega   // m/s
    wheel_v[FR] = vx + vy + K * omega   // m/s
    wheel_v[RL] = vx + vy - K * omega   // m/s
    wheel_v[RR] = vx - vy + K * omega   // m/s

    for i in 0..3:
        rpm[i] = wheel_v[i] / (PI * D) * 60.0   // RPM

    // 等比缩放，保持运动方向不变
    max_abs = max(abs(rpm[0]), abs(rpm[1]), abs(rpm[2]), abs(rpm[3]))
    if max_abs > rpm_limit:
        scale = rpm_limit / max_abs
        for i in 0..3:
            rpm[i] = rpm[i] * scale

    return rpm
```

### 3.7 轮速到 Modbus 方向与速度值的转换

逆运动学输出的 `rpm[i]` 是“车辆运动学正方向”的有符号值，而 ZDT 驱动器速度模式需要：

- 方向：CW 或 CCW
- 速度：非负数 RPM

转换伪代码：

```c
function ConvertRpmToZdtCommand(i, rpm_signed):
    // motor_dir_sign[i] 通过实车标定得到，+1 表示运动学正方向对应 CW
    rpm_motor = rpm_signed * motor_dir_sign[i]

    if rpm_motor >= 0:
        dir = CW
    else:
        dir = CCW

    speed_abs = abs(rpm_motor)   // RPM
    speed_reg = round(speed_abs * ZDT_SPEED_MODE_SCALE)
    speed_reg = clamp(speed_reg, 0, 0xFFFF)

    return dir, speed_reg
```

### 3.8 典型运动的符号检查

| 期望动作 | 轮速关系 |
|---|---|
| 前进 `v_x > 0` | 四轮同号同速 |
| 左移 `v_y > 0` | FL、RR 为负；FR、RL 为正 |
| 原地逆时针旋转 `omega > 0` | FL、RL 为负；FR、RR 为正 |
| 右前斜向 | 由前进与右移叠加得到，部分轮速可能接近 0 |

调车时若某个动作方向相反，优先检查：

1. `motor_dir_sign[i]` 是否标定正确。
2. 轮号 FL/FR/RL/RR 是否与地址 1/2/3/4 对应。
3. 麦轮是否实际为 X 形而不是 O 形安装。
4. RS485 指令中的 CW/CCW 是否与驱动器菜单 `Dir` 设置有关。

---

## 4. 问题四：如何用 JY61P 与激光测距实现稳健移动？

### 4.1 JY61P 在控制系统中的角色

JY61P 提供姿态和航向角，是麦轮小车稳定控制中最重要的反馈量。麦轮底盘容易受轮径差、地面摩擦差、负载偏心和横移打滑影响；仅靠四轮速度积分，航向误差会快速累积。

JY61P 应用于三类控制：

1. **直线行驶保持航向**：前进或横移时锁定初始航向，自动修正偏航。
2. **旋转到指定角度**：角度闭环输出 `omega_ref`。
3. **全局速度转换**：将全局坐标速度转换为车体坐标速度，实现 field-oriented 控制。

### 4.2 航向角闭环控制

在执行“前进指定距离”“横移指定距离”“沿墙走”等任务时，进入运动状态时记录：

```text
theta_ref = yaw_current
```

每个控制周期计算角度误差：

```text
e_theta = wrap_to_pi(theta_ref - yaw_current)
```

航向修正角速度：

```text
omega_corr = Kp_yaw * e_theta - Kd_yaw * gyro_z
```

最终角速度命令：

```text
omega_cmd = omega_user + omega_corr
omega_cmd = clamp(omega_cmd, -omega_max, +omega_max)
```

其中：

- `omega_user` 是上层主动要求的旋转速度；直线行驶时通常为 0。
- `gyro_z` 是 JY61P 输出的 z 轴角速度，作为阻尼项。
- `wrap_to_pi()` 必须处理 `-π` 到 `+π` 的跨越，避免 359° 到 1° 被误判为 358° 误差。

角度闭环伪代码：

```c
function HeadingHold(cmd_vx, cmd_vy, omega_user, yaw, gyro_z):
    e = WrapToPi(theta_ref - yaw)
    omega_corr = Kp_yaw * e - Kd_yaw * gyro_z
    omega = omega_user + omega_corr
    omega = clamp(omega, -OMEGA_LIMIT, OMEGA_LIMIT)
    return ChassisVel(cmd_vx, cmd_vy, omega)
```

### 4.3 转向到指定角度

旋转动作可单独建模为角度位置环：

```text
theta_target = theta_start + delta_theta

e_theta = wrap_to_pi(theta_target - yaw_current)
omega_ref = Kp_turn * e_theta - Kd_turn * gyro_z
```

到达判定：

```text
abs(e_theta) < theta_tol
and abs(gyro_z) < gyro_tol
持续 N 个控制周期
```

到达后发送 4 轮 0 RPM 速度命令，必要时再发送立即停止命令。

### 4.4 级联控制架构

```mermaid
flowchart LR
    A[高层运动指令\n距离/角度/目标点] --> B[速度规划\nvx_user, vy_user, omega_user]
    B --> C[航向控制\nJY61P yaw + gyro_z]
    C --> D[位置/距离修正\n激光 + 里程计]
    D --> E[最终车体速度\nvx, vy, omega]
    E --> F[麦轮逆运动学]
    F --> G[四轮 RPM]
    G --> H[Modbus 同步速度写入]
    H --> I[ZDT 驱动器内部闭环]
    I --> J[车体运动]
    J --> C
    J --> D
```

核心思想：

- JY61P 不直接控制电机，而是修正 `omega`。
- 激光不直接控制电机，而是修正 `vx/vy` 或位置估计。
- 麦轮运动学始终是最后一级速度分解模块。

---

### 4.5 ATK-MS53L1M 如何辅助定位和减速？

ATK-MS53L1M 用于距离测量和环境感知。本文不设计完整 SLAM，只设计可实现的距离/位置修正逻辑。

由于传感器具体安装方向未在项目背景中固定，软件中必须配置传感器外参：

```text
laser_mount_x       传感器相对车体中心 x 偏移
laser_mount_y       传感器相对车体中心 y 偏移
laser_mount_yaw     传感器测距方向相对车体 x 轴夹角
```

如果初期只做前向测距，可将 `laser_mount_yaw = 0`；如果做沿墙控制，侧向安装时可设置为 `±90°`。

#### 逻辑 A：到目标距离缩短时减速

适用于“前进到距目标/墙面指定距离”。

```text
d = laser_distance
remain = d - d_stop

if remain <= 0:
    vx_limit = 0
else:
    vx_limit = sqrt(2 * a_brake * remain)

vx_cmd = clamp(vx_cmd, -vx_limit, +vx_limit)
```

这相当于按制动距离限制最大速度，避免快到目标时冲过头。

#### 逻辑 B：沿墙走横向距离闭环

侧向测距时，设期望墙距为 `d_ref`：

```text
e_d = d_ref - d_meas
vy_corr = Kp_wall * e_d - Kd_wall * d_dot
```

将 `vy_corr` 叠加到车体横向速度命令，JY61P 同时保持航向不变。

```text
vx_final = vx_user
vy_final = vy_user + vy_corr
omega_final = omega_user + yaw_correction
```

#### 逻辑 C：利用距离突变作为位置重置线索

在物流场景中，墙面、货架边缘、定位板可能形成明显距离变化。可以用距离残差判断是否遇到已知特征：

```text
r = d_meas - d_expected_from_map

if abs(r) < gate:
    pose = pose + K_laser * r * sensor_axis
else if abs(d_meas - d_last) > jump_threshold:
    mark_feature_event()
else:
    treat_as_outlier()
```

该逻辑不是 SLAM，只是对里程计进行弱修正。`K_laser` 可取 `0.1-0.5`，调试时从小值开始。

### 4.6 里程计、陀螺仪、激光的融合方式

推荐使用轻量级互补融合：

1. 轮速里程计负责估计短时平移量。
2. JY61P yaw 直接作为航向角，替代轮速积分航向。
3. 激光距离在低频下修正某一方向上的位置误差。

伪代码：

```c
function PoseEstimator_Update(dt):
    rpm_fb = Motor_GetFilteredRpm()
    wheel_v = RpmToWheelVelocity(rpm_fb)
    vx_body, vy_body, omega_wheel = Mecanum_ForwardKinematics(wheel_v)

    yaw = JY61P_GetYawRad()

    vx_global = cos(yaw) * vx_body - sin(yaw) * vy_body
    vy_global = sin(yaw) * vx_body + cos(yaw) * vy_body

    pose.x += vx_global * dt
    pose.y += vy_global * dt
    pose.theta = yaw

    if Laser_HasNewValidData():
        residual = Laser_CalcResidual(pose)
        if abs(residual) < LASER_GATE:
            pose = Pose_CorrectAlongLaserAxis(pose, residual)
```

### 4.7 “保持面向目标方向”的状态机

目标需求：小车移动过程中尽量保持朝向目标方向，或保持指定朝向。

状态机如下：

```mermaid
stateDiagram-v2
    [*] --> INIT
    INIT --> SELF_CHECK: 初始化通信/传感器
    SELF_CHECK --> ALIGN: 电机地址、JY61P、激光正常
    SELF_CHECK --> FAULT: 任一关键模块异常

    ALIGN --> MOVE: 航向误差小于阈值
    MOVE --> SLOWDOWN: 距离目标接近
    SLOWDOWN --> ARRIVED: 位置/距离/速度均满足阈值
    ARRIVED --> STOP
    STOP --> [*]

    MOVE --> FAULT: 电机通信超时/障碍物过近/姿态异常
    SLOWDOWN --> FAULT: 电机通信超时/障碍物过近/姿态异常
    FAULT --> EMERGENCY_STOP
    EMERGENCY_STOP --> [*]
```

每个状态职责：

| 状态 | 职责 |
|---|---|
| `INIT` | 初始化 UART1、TIM、GPIO、传感器驱动、Modbus 状态机 |
| `SELF_CHECK` | 扫描电机 1-4，读取一次转速/状态，检查 JY61P 和激光数据有效性 |
| `ALIGN` | 根据目标方向或任务方向旋转对准，或记录当前航向为 `theta_ref` |
| `MOVE` | 按目标速度移动，JY61P 实时修正航向，激光修正位置/速度 |
| `SLOWDOWN` | 接近目标时按距离限速，降低 `vx/vy/omega` |
| `ARRIVED` | 持续满足到达阈值，发送 0 速度同步命令 |
| `STOP` | 维持 0 速度，等待下一条任务 |
| `FAULT` | 记录故障源，停止规划输出 |
| `EMERGENCY_STOP` | 广播立即停止或同步 0 速度，关闭运动输出 |

---

## 5. 问题五：STM32 HAL 工程如何落地？

### 5.1 推荐软件模块划分

```text
/Core
  main.c
  stm32xx_hal_msp.c

/App
  chassis_control.c/.h       // 高层移动控制、状态机、航向闭环
  mecanum_kinematics.c/.h    // 麦轮正/逆运动学
  pose_estimator.c/.h        // 轮速里程计 + JY61P + 激光修正
  motor_manager.c/.h         // 4 电机命令缓存、速度限幅、故障状态

/Drivers/User
  modbus_rtu.c/.h            // CRC、帧组装、解析、事务状态机
  zdt_x42_modbus.c/.h        // ZDT-X42-V2 寄存器级命令封装
  jy61p.c/.h                 // 已有
  atk_ms53l1m.c/.h           // 已有
```

设计原则：

- `modbus_rtu` 只关心通用 Modbus 帧。
- `zdt_x42_modbus` 只关心电机寄存器和命令语义。
- `mecanum_kinematics` 不关心电机地址、UART、RS485。
- `chassis_control` 不直接操作 UART，只输出四轮目标 RPM 给 `motor_manager`。

### 5.2 需要调用的 HAL 外设

#### UART1

用途：通过 RS485 模块与 4 个 ZDT-X42-V2 驱动器通信。

配置要点：

| 配置项 | 值 |
|---|---|
| TX 引脚 | PA9 |
| RX 引脚 | PA10 |
| 波特率 | 115200 |
| 数据位 | 8 bit |
| 校验 | None |
| 停止位 | 1 bit |
| 流控 | None |
| 模式 | TX/RX |
| 接收 | 中断或 DMA，配合帧超时/空闲检测 |

建议：

- UART1 由 Modbus 事务状态机独占，不允许传感器调试打印复用 UART1。
- 使用发送完成回调或轮询 `TC` 位控制 RS485 方向切换。
- 接收采用中断或 DMA 环形缓冲；解析放在主循环或低优先级任务，不在 ISR 中做复杂计算。

#### GPIO

用途：控制 RS485 模块方向。

配置要点：

| GPIO | 用途 | 初始电平 |
|---|---|---|
| `RS485_DIR_GPIO` | RS485 DE / RE 方向控制 | RX 状态 |

说明：

- 文档不指定具体 GPIO 引脚，避免与现有板级资源冲突。
- 若 RS485 模块的 DE 与 /RE 分开，应在硬件上或软件上保证发送时使能 DE、接收时使能 RE。

#### TIM

用途：产生控制周期和软件超时节拍。

配置建议：

| 定时功能 | 建议周期 | 说明 |
|---|---:|---|
| 1 ms 系统节拍 | `1 ms` | 用于 Modbus 超时、状态机计时、软定时器 |
| 主运动控制触发 | `20 ms` | 可由 1 ms 计数分频得到 |
| 反馈轮询触发 | `40-50 ms` | 可由主控制周期分频得到 |

可使用任意未占用的通用定时器，本文不强制指定 TIM 编号。定时器 ISR 中只置位标志，不直接执行 Modbus 收发。

#### 传感器外设

JY61P 与 ATK-MS53L1M 的 `.c/.h` 文件已就绪，其外设和引脚沿用现有驱动配置。本文移动控制层通过统一接口读取：

```c
float JY61P_GetYawRad(void);
float JY61P_GetGyroZRadS(void);
bool  Laser_GetDistance(float *distance_m);
```

具体传感器底层使用 UART、I2C 或其他接口，以已有驱动为准，不在本文重新分配引脚。

---

### 5.3 中断与优先级建议

建议的优先级从高到低：

1. **UART1 RX/TX 中断或 DMA 中断**：保证 Modbus 收发时序准确。
2. **1 ms 定时器中断**：维护系统 tick、控制周期标志、Modbus 超时计数。
3. **传感器接收中断**：JY61P 或激光数据接收，若其接口依赖中断。
4. **主循环任务**：状态机、运动学、Modbus 事务调度、日志。

实现原则：

- 不在定时器 ISR 中直接发送 Modbus 帧。
- 不在 UART ISR 中解析完整控制逻辑，只搬运数据和置位事件。
- 所有 Modbus 请求通过一个事务队列发送，避免并发访问 UART1。

### 5.4 Modbus 事务状态机

```mermaid
flowchart TD
    IDLE[IDLE 空闲] --> BUILD[BUILD 组帧]
    BUILD --> TX_EN[RS485 切到 TX]
    TX_EN --> TX_SEND[UART1 发送]
    TX_SEND --> WAIT_TC[等待 TC]
    WAIT_TC --> RX_EN[RS485 切到 RX]
    RX_EN --> WAIT_RESP{是否广播?}
    WAIT_RESP -->|是| DONE[DONE]
    WAIT_RESP -->|否| RX_WAIT[等待响应/超时]
    RX_WAIT --> PARSE[CRC 与字段校验]
    PARSE --> DONE
    PARSE --> ERROR[ERROR]
    RX_WAIT --> ERROR
    DONE --> GAP[帧间隔]
    ERROR --> GAP
    GAP --> IDLE
```

该状态机由主循环驱动，定时器只提供 `tick` 和超时判断。

### 5.5 启动、停止和急停机制

#### 上电初始化

```text
1. GPIO 初始化，RS485_DIR 默认 RX
2. UART1 初始化为 115200 8N1
3. TIM 初始化，启动 1 ms tick
4. 初始化 JY61P、ATK-MS53L1M 驱动
5. 扫描 1-4 号电机，读取实时转速或状态参数
6. 对每个电机发送使能命令
7. 发送四轮 0 RPM 同步速度命令，广播同步触发
8. 进入待命状态
```

使能命令寄存器：

| 功能 | 功能码 | 起始寄存器 | 数量 | 数据 |
|---|---:|---:|---:|---|
| 使能信号控制 | `0x10` | `0x00E0` | `0x0002` | Reg1=`0xAB + 使能状态`，Reg2=`同步标志 + 0x00` |

使能 1 号电机示例：

```text
01 10 00 E0 00 02 04 AB 01 00 00 CRC_L CRC_H
```

#### 正常停止

正常停止优先使用速度模式减速到 0：

```text
1. 四轮目标 rpm = 0
2. 根据当前速度设置合适加速度
3. 四轮速度命令设置同步缓存
4. 广播同步触发
5. 等待 rpm_fb 接近 0 或延时到达
```

#### 急停

急停使用“立即停止”命令。寄存器：

| 功能 | 功能码 | 起始寄存器 | 数量 | 数据 |
|---|---:|---:|---:|---|
| 立即停止 | `0x10` | `0x00FE` | `0x0001` | `0x9800`，低字节可作为同步标志 |

广播急停帧：

```text
00 10 00 FE 00 01 02 98 00 D5 DE
```

急停触发条件：

- 任一电机连续通信超时达到阈值。
- JY61P 航向异常跳变或数据长时间无更新。
- 激光检测到近距离障碍物且速度仍朝向障碍物。
- 上层任务发出急停命令。
- 电机状态位显示堵转、故障、过温等异常。

---

## 6. 总结性控制流程总图

```mermaid
flowchart TD
    A[高层任务输入\n前进距离/横移距离/旋转角度/目标点] --> B[任务状态机]
    B --> C[速度规划\n生成 vx_user, vy_user, omega_user]

    C --> D[JY61P 航向控制]
    D --> E[激光距离/位置修正]
    E --> F[最终车体速度\nvx, vy, omega]

    F --> G{是否全局速度?}
    G -->|是| H[用 yaw 转换到车体坐标]
    G -->|否| I[保持车体坐标]
    H --> J[麦轮逆运动学]
    I --> J

    J --> K[四轮目标 RPM]
    K --> L[限幅/等比缩放/斜率限制]
    L --> M[可选轮速 PI 修正]
    M --> N[转换为 ZDT 方向 + 速度寄存器]

    N --> O[构造 4 个 Modbus 速度帧\n0x10, 0x00E6]
    O --> P[RS485 半双工事务状态机]
    P --> Q[单播缓存到 1/2/3/4 号电机]
    Q --> R[广播同步触发\n0x00FF, 0x6600]
    R --> S[ZDT 驱动器内部闭环]
    S --> T[麦轮底盘运动]

    T --> U[读取电机实时转速\n0x04, 0x0044]
    U --> V[轮速滤波与异常检测]
    V --> W[里程计积分]
    W --> E
    V --> M

    T --> X[JY61P yaw/gyro]
    X --> D

    T --> Y[ATK-MS53L1M 距离]
    Y --> E

    V --> Z{故障?}
    X --> Z
    Y --> Z
    Z -->|是| AA[急停/减速停机]
    Z -->|否| B
```

---

## 7. 实施优先级与调试路线

### 7.1 第一阶段：总线与单电机闭环跑通

目标：确认 STM32C8T6 通过 UART1 + RS485 能稳定控制单个 ZDT-X42-V2。

步骤：

1. 驱动器菜单设置：`P_Serial = UART_FUN`，`Checksum = Modbus`，`UartBaud = 115200`。
2. 单独连接 1 号电机，读取实时转速寄存器 `0x0044`。
3. 发送使能命令。
4. 发送低速速度命令，例如 60 RPM，确认方向和速度。
5. 校验速度模式的 `ZDT_SPEED_MODE_SCALE`：比较命令值与实际读回值。
6. 完成 Modbus CRC、超时、方向切换的稳定性测试。

### 7.2 第二阶段：四电机寻址和同步

目标：4 个电机挂同一条 RS485 总线，地址 1-4，能同步启动和停止。

步骤：

1. 逐台设置地址 1-4。
2. 全部接入总线，逐地址读取实时转速。
3. 对四个电机发送 0 RPM，确认均响应。
4. 使用同步缓存 + 广播触发，测试四轮同时起步。
5. 标定 `motor_dir_sign[4]`，保证运动学正方向一致。

### 7.3 第三阶段：麦轮基础动作

目标：不接入传感器闭环时，完成前进、后退、左移、右移、原地旋转。

测试顺序：

1. `v_x > 0, v_y = 0, omega = 0`：前进。
2. `v_x = 0, v_y > 0, omega = 0`：左移。
3. `v_x = 0, v_y = 0, omega > 0`：逆时针旋转。
4. 组合速度：斜向移动。
5. 逐步提高速度，验证等比缩放和斜率限制。

### 7.4 第四阶段：JY61P 航向闭环

目标：直线和横移时自动抑制偏航。

步骤：

1. 读取 yaw，验证角度方向和单位。
2. 前进任务开始时锁定 `theta_ref`。
3. 启用 `omega_corr = Kp_yaw * e - Kd_yaw * gyro_z`。
4. 从小 `Kp_yaw` 开始调参，先不用积分。
5. 加入旋转到指定角度动作。

### 7.5 第五阶段：激光距离修正和到达判定

目标：实现靠近目标减速、沿墙距离保持、简单位置重置。

步骤：

1. 确认 ATK-MS53L1M 距离单位、有效范围和异常值。
2. 根据安装方向配置 `laser_mount_yaw`。
3. 实现距离限速：越接近目标越慢。
4. 实现沿墙距离 P 控制。
5. 将激光残差引入里程计位置修正。

---

## 8. 关键配置项清单

建议在工程中集中定义以下配置：

```c
// 机械参数
#define MECANUM_WHEEL_DIAMETER_M     0.075f
#define MECANUM_TRACK_WIDTH_M        0.320f
#define MECANUM_WHEEL_BASE_M         0.220f
#define MECANUM_K_M                  ((MECANUM_TRACK_WIDTH_M + MECANUM_WHEEL_BASE_M) * 0.5f)

// 电机地址
#define MOTOR_ADDR_FL                0x01
#define MOTOR_ADDR_FR                0x02
#define MOTOR_ADDR_RL                0x03
#define MOTOR_ADDR_RR                0x04

// 通信参数
#define MODBUS_BAUDRATE              115200
#define MODBUS_INTER_FRAME_GAP_MS    1u
#define MODBUS_RESPONSE_TIMEOUT_MS   5u

// 周期
#define CHASSIS_CTRL_PERIOD_MS       20u
#define MOTOR_FEEDBACK_PERIOD_MS     40u
#define LASER_UPDATE_PERIOD_MS       50u

// 缩放系数，联调后确认
#define ZDT_SPEED_MODE_SCALE         1.0f   // RPM 缩放系数
#define ZDT_SPEED_FEEDBACK_SCALE     1.0f
```

上述宏只是建议的集中配置形式，不要求照搬名称。关键是避免把机械参数、地址、缩放系数散落在多个源文件中。

---

## 9. 风险点与规避措施

| 风险 | 表现 | 规避措施 |
|---|---|---|
| 四个电机地址重复 | 总线响应冲突、CRC 错误、随机超时 | 逐台设置地址；上线前扫描 1-4 地址 |
| RS485 A/B 接反 | 全部无响应或 CRC 错 | 交换 A/B；确认 `R/A/H` 与 `T/B/L` 接线 |
| 半双工方向切换过早 | 响应超时、最后字节丢失 | 等待 UART TC 后再切 RX |
| 广播后等待响应 | 控制周期被无效等待占用 | 广播帧不等待响应 |
| 轮号与地址不一致 | 前进变横移或旋转 | 建立轮号-地址表，逐轮点动验证 |
| 电机方向未标定 | 单轮方向反、运动畸变 | 使用 `motor_dir_sign[4]` 软件标定 |
| 麦轮安装不是 X 形 | 横移方向反或效率差 | 检查滚子方向，必要时切换运动学符号 |
| 主控速度 PID 过强 | 速度振荡、响应迟滞 | 默认关闭；只保留低频小幅 PI 修正 |
| 轮速里程计累积误差 | 长距离偏移 | 使用 JY61P 修正航向，激光修正距离/位置 |
| 激光异常值 | 突然减速或位置跳变 | 加有效范围、突变门限和残差门限 |

---

## 10. 最终推荐方案摘要

1. **总线寻址**：4 个电机通过 Modbus 从机地址区分，地址设为 `1-4`，`0` 作为广播地址。
2. **通信控制**：UART1 使用 PA9/PA10，115200 8N1，RS485 半双工方向由独立 GPIO 控制。
3. **速度命令**：使用 `0x10` 写 `0x00E6`，每个电机写方向、加速度、速度和同步标志。
4. **同步更新**：默认采用“4 个单播缓存 + 1 个广播同步触发”的方式，保证四轮同时更新速度。
5. **速度反馈**：使用 `0x04` 读 `0x0044`，单主机顺序轮询，避免总线冲突。
6. **闭环策略**：ZDT 驱动器承担电机内部速度闭环；主控负责航向、位置、距离外环；轮速 PI 仅作为低频监督修正。
7. **运动学**：使用 X 形麦轮逆运动学，`K=(L+W)/2=0.270m`，将 `(v_x,v_y,omega)` 转换为四轮 RPM，并做等比限幅。
8. **传感器融合**：JY61P 负责航向稳定和旋转角度控制；ATK-MS53L1M 负责距离限速、沿墙修正和简单位置重置。
9. **工程调度**：TIM 提供 20 ms 主控制周期；Modbus 事务在主循环或任务中串行执行；UART 中断只做收发事件处理。
10. **安全机制**：通信超时、CRC 异常、传感器异常、障碍物过近或电机状态异常时进入减速停机或广播急停。

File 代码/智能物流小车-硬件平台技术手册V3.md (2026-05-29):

# 智能物流小车硬件平台技术手册 V3

> 项目阶段：底盘控制、传感器数据读取、树莓派联动准备  
> 文档版本：V3.0  
> 最后更新：2026-05-26  
> 维护方式：后续修改请优先更新"待确认事项"和"变更记录"  
> 主要依据：现有硬件平台手册、`ATK_JY_NewVer_GPT` 工程代码、控制板硬件审查报告、当前 STM32CubeIDE 引脚截图。

---

## 目录

1. [系统架构总览](#1-系统架构总览)
2. [STM32F103C8T6 引脚与外设分配](#2-stm32f103c8t6-引脚与外设分配)
3. [传感器连接与数据采集](#3-传感器连接与数据采集)
4. [电机与树莓派通信](#4-电机与树莓派通信)
5. [供电系统与功率预算](#5-供电系统与功率预算)
6. [数据接收与分发](#6-数据接收与分发)
7. [赛场运行状态与模块调用](#7-赛场运行状态与模块调用)
8. [FreeRTOS 必要性评估](#8-freertos-必要性评估)
9. [优化建议与后续待确认项](#9-优化建议与后续待确认项)
10. [变更记录](#10-变更记录)

---

## 1. 系统架构总览

### 1.1 分层职责

系统按"决策层、控制层、执行层"划分。树莓派负责高层任务，STM32 负责实时采集、通信转发和安全保护，电机驱动与传感器负责底层执行和反馈。

| 层级 | 硬件 | 主要职责 | 关键输出 |
|---|---|---|---|
| 决策层 | 树莓派 4B | 视觉识别、路径规划、任务调度、比赛策略 | 速度指令、目标点、任务状态 |
| 控制层 | STM32F103C8T6 底盘控制板 | 传感器采样、命令校验、限幅、安全停车、电机通信分发 | 电机命令、状态上报、安全状态 |
| 感知层 | JY61P、ATK-MS53L1M | 姿态、角速度、加速度、前向或指定方向距离 | IMU 数据、距离数据 |
| 执行层 | ZDT_X42 电机驱动与麦克纳姆轮 | 底盘移动、闭环速度/位置执行 | 编码器/驱动状态、实际运动 |

### 1.2 当前物理链路

```text
树莓派 4B
  USB
   |
   v
CH340N USB 转串口
   |
   | 3.3V/TTL 串口逻辑，板级电平需实测确认
   v
STM32F103C8T6 USART2
  PA2 = USART2_TX
  PA3 = USART2_RX

STM32F103C8T6 I2C1 
  PB6 = I2C1_SCL
  PB7 = I2C1_SDA
   |---------------- JY61P IMU
   |---------------- ATK-MS53L1M / VL53L1X 激光测距

STM32F103C8T6 USART1
  PA9 = USART1_TX
  PA10 = USART1_RX
   |
   v
RS485模块 → ZDT_X42 电机通信链路
```

### 1.3 数据流向

| 方向 | 路径 | 数据内容 | 处理要求 |
|---|---|---|---|
| 上行反馈 | JY61P -> I2C1 -> STM32 -> USART2/CH340N -> 树莓派 | Roll、Pitch、Yaw、三轴加速度、三轴角速度、温度 | 带时间戳，保留最近一次有效值 |
| 上行反馈 | ATK-MS53L1M -> I2C1 -> STM32 -> USART2/CH340N -> 树莓派 | 距离 mm、测量状态、样本计数 | 距离异常时标记无效，不直接覆盖安全状态 |
| 上行反馈 | 电机驱动 -> USART3 -> STM32 -> USART2/CH340N -> 树莓派 | 在线状态、速度/位置反馈、错误码 | 按实际电机协议补全 |
| 下行控制 | 树莓派 -> USART2/CH340N -> STM32 -> USART3 -> 电机驱动 | 速度向量、目标位置、停止、急停解除、校准命令 | CRC 校验、序号检查、限幅、安全状态优先 |

---

## 2. STM32F103C8T6 引脚与外设分配

### 2.1 已确定引脚表

| STM32 引脚 | 外设/功能 | 连接对象 | 方向 | 状态 | 备注 |
|---|---|---|---|---|---|---|
| PB6 | I2C1_SCL | JY61P、ATK-MS53L1M | 双向 | 已确定 | 需在 CubeMX/HAL 中启用 I2C1 |
| PB7 | I2C1_SDA | JY61P、ATK-MS53L1M | 双向 | 已确定 | |
| PA9 | USART1_TX | RS485 模块 DI → ZDT_X42 电机 | STM32 输出 | 已确定 | 需另配 GPIO 控制 RS485 收发方向 |
| PA10 | USART1_RX | RS485 模块 RO ← ZDT_X42 电机 | STM32 输入 | 已确定 | 与电机通信模块共地 |
| PA2 | USART2_TX | CH340N RXD，树莓派通信 | STM32 输出 | 已确定 | 树莓派通过 USB 访问 CH340N 虚拟串口 |
| PA3 | USART2_RX | CH340N TXD，树莓派通信 | STM32 输入 | 已确定 | 需确认 CH340N TXD 电平安全 |
| PA13 | SWDIO | ST-LINK / 调试器 | 双向 | 保留 | 不作为业务 IO 使用 |
| PA14 | SWCLK | ST-LINK / 调试器 | 输入 | 保留 | 不作为业务 IO 使用 |
| NRST | 复位 | 调试器/复位电路 | 输入 | 保留 | 建议在调试接口引出 |
| PC13 | 状态 LED，可选 | 板载 LED | 输出 | 可选 | 低电平点亮的核心板常见连接，需按实际板验证 |

### 2.2 CubeMX / CubeIDE 配置要点

| 项目 | 建议配置 | 原因 |
|---|---|---|
| I2C1 | PB6(SCL)/PB7(SDA)，100 kHz 起步 | 默认引脚，不需remap；两个传感器共总线，先保证稳定 |
| USART2 | 异步串口，115200 bps 起步 | 树莓派和 STM32 主通信链路 |
| USART3 | 异步串口，按电机驱动协议设置 | 电机链路独立于树莓派链路 |
| SWD | 保持开启 | 便于 ST-LINK 在线调试 |
| GPIO 未用脚 | 统一配置为模拟输入或明确上下拉 | 降低悬空噪声和功耗 |

### 2.3 引脚占用原则

- PB6/PB7 归 I2C1 独占，由 JY61P 和 ATK-MS53L1M 共用。
- PA2/PA3 归树莓派通信链路独占。
- PA9/PA10 归电机 USART1 通信链路独占。
- PA13/PA14/NRST 保留给调试和下载。
- 后续新增外设时优先选择未占用的 GPIO，并同步更新本表。

---

## 3. 传感器连接与数据采集

### 3.1 I2C1 共总线设计

JY61P 和 ATK-MS53L1M 均接入 STM32 的 I2C1，总线引脚为 PB6/PB7。

| 设备 | 7-bit 地址 | HAL/8-bit 地址 | 主要数据 | 当前代码状态 |
|---|---|---|---|---|
| JY61P | 0x50 | 0xA0 | 加速度、角速度、Roll/Pitch/Yaw、温度 | .c/.h 已完成 |
| ATK-MS53L1M / VL53L1X | 0x29 | 0x52 | 距离 mm、测量状态 | .c/.h 已完成 |

I2C 电气要求：
- SCL/SDA 上拉必须接 5V（硬件板级确认）。
- 两个传感器和 STM32 必须共地。
- 调试阶段 I2C 速率先使用 100 kHz。
- 总线偶发卡死时固件需支持 I2C bus recovery。

### 3.2 JY61P 陀螺仪/IMU

#### 连接方式

| JY61P 引脚 | STM32 连接 | 说明 |
|---|---|---|
| VCC | 5V | 统一5V供电 |
| GND | GND | 共地 |
| SCL | PB6 / I2C1_SCL | I2C 时钟 |
| SDA | PB7 / I2C1_SDA | I2C 数据 |
| RX | 不连接 | 本版不使用串口模式 |
| TX | 不连接 | 本版不使用串口模式 |

#### 代码接口与变量名（同步 GPT 工程代码）

当前代码连续读取 `0x34` 起始的 26 字节数据寄存器，转换为以下物理量：

| 数据 | 寄存器 | 转换关系 |
|---|---|---|
| 加速度 | AX=0x34 起 | raw / 32768 * 16g |
| 角速度 | GX=0x37 起 | raw / 32768 * 2000 dps |
| 欧拉角 | ROLL=0x3D 起 | raw / 32768 * 180 deg |
| 温度 | TEMP=0x40 | raw / 100 |

**推荐全局变量名（g_ 前缀）：**

| 变量名 | 类型 | 单位 | 说明 |
|---|---|---|---|
| g_imu_car_yaw_est_deg | volatile float | deg | 融合估计偏航角 |
| g_imu_car_pitch_deg | volatile float | deg | 车体系俯仰角 |
| g_imu_car_roll_deg | volatile float | deg | 车体系横滚角 |
| g_imu_gyro_yaw_dps | volatile float | deg/s | 偏航角速度 |
| g_imu_acc_forward_g | volatile float | g | 前向加速度 |
| g_imu_acc_right_g | volatile float | g | 右向加速度 |
| g_imu_acc_down_g | volatile float | g | 向下加速度 |
| g_imu_temperature_c | volatile float | C | 温度 |
| g_imu_valid | volatile uint8_t | -- | 数据是否有效 |
| g_imu_calibrated | volatile uint8_t | -- | 是否完成校准 |

**兼容变量名（无 g_ 前缀，供旧代码过渡）：**

| 兼容变量名 | 映射到 |
|---|---|
| car_yaw_est_deg | g_imu_car_yaw_est_deg |
| car_pitch_deg | g_imu_car_pitch_deg |
| car_roll_deg | g_imu_car_roll_deg |
| gyro_yaw_dps | g_imu_gyro_yaw_dps |
| acc_forward_g | g_imu_acc_forward_g |
| acc_right_g | g_imu_acc_right_g |
| acc_down_g | g_imu_acc_down_g |
| temperature_c | g_imu_temperature_c |
| imu_valid | g_imu_valid |
| imu_calibrated | g_imu_calibrated |

### 3.3 ATK-MS53L1M 激光测距模块

#### 连接方式

| ATK-MS53L1M 引脚 | STM32 连接 | 说明 |
|---|---|---|
| VCC | 5V | 统一5V供电 |
| GND | GND | 共地 |
| SCL | PB6 / I2C1_SCL | 与 JY61P 共用 |
| SDA | PB7 / I2C1_SDA | 与 JY61P 共用 |
| TXD | 不连接 | I2C 模式不使用 |
| RXD | 不连接 | I2C 模式不使用 |

#### 代码接口与变量名（同步 GPT 工程代码）

当前代码使用 VL53L1X API 适配，配置如下：Long 模式、Timing Budget 140000 us、Inter-measurement 150 ms。

**推荐全局变量名（g_ 前缀）：**

| 变量名 | 类型 | 单位 | 说明 |
|---|---|---|---|
| g_laser_raw_distance_mm | volatile uint16_t | mm | 最新原始距离 |
| g_laser_filtered_distance_mm | volatile uint16_t | mm | 滤波后稳定距离 |
| g_laser_distance_mm | volatile uint16_t | mm | 对外输出距离 |
| g_laser_valid | volatile uint8_t | -- | 距离数据是否有效 |
| g_laser_ok | volatile uint8_t | -- | 模块是否在线 |
| g_laser_is_warning | volatile uint8_t | -- | 预警标志（小于 600 mm） |
| g_laser_is_slow | volatile uint8_t | -- | 减速标志（小于 300 mm） |
| g_laser_is_too_close | volatile uint8_t | -- | 停车标志（小于 150 mm） |
| g_laser_last_valid_ms | volatile uint32_t | ms | 最近有效距离更新时间 |

### 3.4 传感器使用建议

- IMU 适合用于航向角辅助、姿态异常检测和短时间运动稳定判断。
- 激光测距适合用于前向障碍、靠近货架/目标点时的距离判断。
- 两个传感器都在 I2C1 上，应避免阻塞式 I2C 操作影响另一个传感器。

---

## 4. 电机与树莓派通信

### 4.1 树莓派与 STM32 链路

树莓派通过 USB → CH340N → STM32 USART2(PA2/PA3)，波特率 115200 bps 起步。

建议下行命令帧格式：帧头 + 序号 + 消息类型 + 负载长度 + 负载 + CRC16。
建议上行状态帧格式：帧头 + 系统状态 + 故障位 + IMU摘要 + 激光摘要 + 电机摘要 + 心跳。

### 4.2 STM32 与电机驱动链路

| 项目 | 配置 |
|---|---|
| STM32 外设 | USART1 |
| 引脚 | PA9 = TX，PA10 = RX |
| 连接对象 | ZDT_X42 电机通信链路（经 RS485 转换） |
| 起步波特率 | 115200 bps |

---

## 5. 供电系统与功率预算

### 5.1 当前供电树

12V 输入 → 12V 母线（电机驱动）+ TPS5450 → +5V（树莓派、CH340N、STM32）+ TPS5450 → +7.5V（后续外设）。

### 5.2 功率预算（摘要）

| 负载 | 电压 | 功率估算 |
|---|---|---|
| 树莓派 4B | 5V | 峰值 15W |
| STM32F103 核心板 | 5V/3.3V | 小于 0.5W |
| JY61P | 3.3V/5V | 约 0.042W |
| ATK-MS53L1M | 3.3V/5V | 小于 0.15W |
| ZDT_X42 x4 | 12V | 待测 |

---

## 6. 数据接收与分发

### 6.1 STM32 内部数据模型

| 数据块 | 来源 | 更新周期 | 关键字段 |
|---|---|---|---|
| imu_state | JY61P/I2C1 | 10-20 ms | 姿态、角速度、加速度、时间戳、有效标志 |
| laser_state | ATK-MS53L1M/I2C1 | 100-200 ms | 距离、状态、时间戳、过近标志 |
| motor_state | ZDT_X42/USART3 | 20-100 ms | 在线状态、速度、位置、错误码 |
| cmd_state | 树莓派/USART2 | 每帧更新 | 速度目标、位置目标、模式、序号 |
| safety_state | STM32 本地状态机 | 1-5 ms | 急停、超时、限速、故障位 |
| link_state | USART2/USART3 | 每次收发更新 | 心跳时间、错误计数、丢包计数 |

### 6.2 推荐裸机调度节拍

| 模块 | 触发方式 | 建议周期 |
|---|---|---|
| USART2/USART3 接收 | 中断或 DMA | 实时 |
| 协议解析 | 主循环 | 1-5 ms |
| 安全状态机 | 主循环或定时器 | 1-5 ms |
| IMU 读取 | 主循环 | 10-20 ms |
| 激光读取 | 主循环 | 100-200 ms |
| 电机命令刷新 | 主循环 | 10-20 ms |
| 状态上报 | 主循环 | 20-100 ms |

---

## 7. 赛场运行状态与模块调用

### 7.1 状态机总览

POWER_ON → SELF_TEST → IDLE → READY → RUNNING（CRUISE / APPROACH_TARGET / AVOID_OBSTACLE / LOAD_OR_UNLOAD）→ FAULT（LINK_LOST / POSE_ABNORMAL / MOTOR_FAULT / E_STOP）→ RECOVERY

### 7.2 建议阈值管理

| 阈值 | 默认建议 |
|---|---|
| 树莓派心跳超时 | 500 ms |
| 激光避障预警距离 | 300-500 mm |
| 激光硬停车距离 | 100-200 mm |
| 姿态异常 Roll/Pitch | 8-12 deg |
| 电机命令刷新 | 20 ms |

---

## 8. FreeRTOS 必要性评估

### 8.1 当前结论

当前阶段不强制使用 FreeRTOS。裸机超级循环 + 中断/DMA + 非阻塞状态机已可满足需求。

### 8.2 需要引入 FreeRTOS 的条件

- 树莓派下发高频速度命令且串口解析影响传感器采样。
- 需要持续读取四个电机实时状态。
- 激光、IMU、电机、树莓派、日志同时运行时主循环延迟不可控。

---

## 9. 优化建议与后续待确认项

### 9.1 近期优先优化

- P0: 确认电机物理层、树莓派通信协议、I2C 电平、电机地址和参数
- P1: 电源纹波测试、CH340N 电平确认、急停输入确认、传感器安装标定
- P2: 电池监测、FreeRTOS 迁移评估

### 9.2 待确认事项

| 编号 | 问题 | 优先级 |
|---|---|---|
| A1 | USART3 到 ZDT_X42 的实际物理层 | P0 |
| A2 | RS485 方向控制引脚 | P0 |
| A3 | 电机地址、细分、限流参数 | P0 |
| A4 | 树莓派和 STM32 的最终串口波特率 | P0 |
| A5 | 急停按钮是否已安装 | P1 |
| A6 | 电池容量和预期续航 | P1 |
| A7 | 机械臂是否进入本阶段联调 | P2 |
| A8 | 激光避障阈值和安装方向 | P1 |
| A9 | IMU 坐标系与车体坐标系关系 | P1 |

---

## 10. 变更记录

| 版本 | 日期 | 变更 |
|---|---|---|
| V2 | 2026-05-15 | 重写硬件平台手册 |
| V2.1 | 2026-05-17 | 修正 I2C1 引脚为 PB6/PB7 |
| V2.2 | 2026-05-20 | 修正第3.1节 PB8/PB9 为 PB6/PB7 |
| V2.3 | 2026-05-21 | 修正第3.2节 JY61P 连接表 SCL/SDA 引脚 |
| V3.0 | 2026-05-26 | 同步 ATK_JY_NewVer_GPT 工程代码实际变量名：IMU 改用 g_imu_car_* / g_imu_acc_* / g_imu_gyro_* 命名体系；激光改用 g_laser_* 命名体系；新增兼容变量名对照表；新增 imu_calibrated、laser_is_warning、laser_is_slow 等字段 |

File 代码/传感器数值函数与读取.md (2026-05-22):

# 传感器数据变量与 CubeIDE 调试说明

本文档对应代码目录：

```text
D:\AI_agent\Code\stm32cubeide_atk_ms53l1m_i2c_framework
```

当前工程集成两个传感器：

- ATK-MS53L1M 激光测距模块：使用 `I2C1`，引脚 `PB8/PB9`
- JY61P 陀螺仪/姿态传感器：使用 `USART3`，引脚 `PB10/PB11`

最终给 `main.c` 调用的是统一入口：

```c
#include "board_app.h"
```

## 1. 文件分层

| 层级 | 文件 | 作用 |
| --- | --- | --- |
| 板级统一入口 | `Core/Inc/board_app.h`, `Core/Src/board_app.c` | 统一初始化、统一循环调用、转发 JY61P UART 接收回调 |
| 激光应用层 | `Core/Inc/laser_app.h`, `Core/Src/laser_app.c` | 保存激光距离、状态、采样次数 |
| 激光底层驱动 | `Core/Inc/atk_ms53l1m.h`, `Core/Src/atk_ms53l1m.c` | 调用 ST VL53L1X API，从 ATK-MS53L1M 读取距离 |
| 陀螺仪应用层 | `Core/Inc/imu_app.h`, `Core/Src/imu_app.c` | 保存姿态角、加速度、角速度、数据包计数 |
| 陀螺仪底层驱动 | `Core/Inc/jy61p.h`, `Core/Src/jy61p.c` | 解析 JY61P UART 数据帧，校验并换算单位 |

## 2. 板级统一变量

这些变量用于判断整个应用框架是否在运行。

| 变量名 | 类型 | 定义位置 | 声明位置 | 含义 |
| --- | --- | --- | --- | --- |
| `g_board_app_flags` | `volatile uint8_t` | `Core/Src/board_app.c` | `Core/Inc/board_app.h` | 板级应用标志位。当前使用 `BOARD_APP_FLAG_INIT_DONE = 0x01` 表示已执行 `Board_App_Init()` |
| `g_board_app_loop_count` | `volatile uint32_t` | `Core/Src/board_app.c` | `Core/Inc/board_app.h` | `Board_App_Loop()` 被调用的次数。持续增加说明主循环在运行 |
| `g_board_app_last_tick_ms` | `volatile uint32_t` | `Core/Src/board_app.c` | `Core/Inc/board_app.h` | 最近一次执行 `Board_App_Loop()` 的 `HAL_GetTick()` 时间戳，单位 ms |

调试时优先观察：

```text
g_board_app_loop_count
```

如果这个变量不增加，说明 `while (1)` 中没有持续调用 `Board_App_Loop()`，后续传感器变量也不会更新。

## 3. 激光传感器公开变量

这些变量是后续小车控制逻辑应直接读取的激光数据。

| 变量名 | 类型 | 定义位置 | 声明位置 | 含义 |
| --- | --- | --- | --- | --- |
| `g_laser_status` | `volatile ATK_MS53L1M_StatusTypeDef` | `Core/Src/laser_app.c` | `Core/Inc/laser_app.h` | 激光最近一次初始化或读取状态 |
| `g_laser_distance_mm` | `volatile uint16_t` | `Core/Src/laser_app.c` | `Core/Inc/laser_app.h` | 最新激光测距值，单位 mm |
| `g_laser_module_id` | `volatile uint16_t` | `Core/Src/laser_app.c` | `Core/Inc/laser_app.h` | 模块 ID，正常应为 `0xEACC` |
| `g_laser_sample_count` | `volatile uint32_t` | `Core/Src/laser_app.c` | `Core/Inc/laser_app.h` | 激光成功读取次数。持续增加说明激光读取正常 |
| `g_laser_last_tick_ms` | `volatile uint32_t` | `Core/Src/laser_app.c` | `Core/Inc/laser_app.h` | 最近一次成功读取激光距离的时间戳，单位 ms |

`g_laser_status` 的枚举定义在：

```text
Core/Inc/atk_ms53l1m.h
```

常用状态：

| 状态 | 数值 | 含义 |
| --- | --- | --- |
| `ATK_MS53L1M_OK` | `0` | 正常 |
| `ATK_MS53L1M_ERROR_HAL` | `1` | HAL 参数或调用错误 |
| `ATK_MS53L1M_ERROR_NOT_FOUND` | `2` | 未检测到模块或模块 ID 不匹配 |
| `ATK_MS53L1M_ERROR_VL53L1` | `3` | VL53L1X API 返回错误 |
| `ATK_MS53L1M_ERROR_NOT_READY` | `4` | 本次测距数据尚未准备好 |

使用示例：

```c
if (g_laser_sample_count > 0U)
{
    uint16_t distance_mm = g_laser_distance_mm;
}
```

## 4. JY61P 陀螺仪公开变量

这些变量是后续小车姿态控制逻辑应直接读取的陀螺仪数据。

| 变量名 | 类型 | 定义位置 | 声明位置 | 含义 |
| --- | --- | --- | --- | --- |
| `g_imu_ready_flags` | `volatile uint8_t` | `Core/Src/imu_app.c` | `Core/Inc/imu_app.h` | 最近一次从底层取出的数据类型标志 |
| `g_imu_update_count` | `volatile uint32_t` | `Core/Src/imu_app.c` | `Core/Inc/imu_app.h` | IMU 应用层成功更新公开变量的次数 |
| `g_imu_packet_count` | `volatile uint32_t` | `Core/Src/imu_app.c` | `Core/Inc/imu_app.h` | JY61P 底层成功解析的数据包数量。持续增加说明 UART 数据流正常 |
| `g_imu_checksum_error_count` | `volatile uint32_t` | `Core/Src/imu_app.c` | `Core/Inc/imu_app.h` | JY61P UART 帧校验失败次数。偶发可接受，持续增加说明串口参数、接线或干扰有问题 |
| `g_imu_last_tick_ms` | `volatile uint32_t` | `Core/Src/imu_app.c` | `Core/Inc/imu_app.h` | 最近一次 IMU 公开变量更新的时间戳，单位 ms |
| `g_imu_roll_deg` | `volatile float` | `Core/Src/imu_app.c` | `Core/Inc/imu_app.h` | 横滚角 Roll，单位 deg |
| `g_imu_pitch_deg` | `volatile float` | `Core/Src/imu_app.c` | `Core/Inc/imu_app.h` | 俯仰角 Pitch，单位 deg |
| `g_imu_yaw_deg` | `volatile float` | `Core/Src/imu_app.c` | `Core/Inc/imu_app.h` | 偏航角 Yaw，单位 deg |
| `g_imu_ax_g` | `volatile float` | `Core/Src/imu_app.c` | `Core/Inc/imu_app.h` | X 轴加速度，单位 g |
| `g_imu_ay_g` | `volatile float` | `Core/Src/imu_app.c` | `Core/Inc/imu_app.h` | Y 轴加速度，单位 g |
| `g_imu_az_g` | `volatile float` | `Core/Src/imu_app.c` | `Core/Inc/imu_app.h` | Z 轴加速度，单位 g |
| `g_imu_gx_dps` | `volatile float` | `Core/Src/imu_app.c` | `Core/Inc/imu_app.h` | X 轴角速度，单位 deg/s |
| `g_imu_gy_dps` | `volatile float` | `Core/Src/imu_app.c` | `Core/Inc/imu_app.h` | Y 轴角速度，单位 deg/s |
| `g_imu_gz_dps` | `volatile float` | `Core/Src/imu_app.c` | `Core/Inc/imu_app.h` | Z 轴角速度，单位 deg/s |
| `g_imu_temp_c` | `volatile float` | `Core/Src/imu_app.c` | `Core/Inc/imu_app.h` | JY61P 温度，单位 Celsius |

`g_imu_ready_flags` 标志位定义在：

```text
Core/Inc/jy61p.h
```

| 标志 | 数值 | 含义 |
| --- | --- | --- |
| `JY61P_FLAG_ACCEL` | `0x01` | 收到加速度数据包 |
| `JY61P_FLAG_GYRO` | `0x02` | 收到角速度数据包 |
| `JY61P_FLAG_ANGLE` | `0x04` | 收到姿态角数据包 |

使用示例：

```c
if (g_imu_packet_count > 0U)
{
    float yaw = g_imu_yaw_deg;
    float gz = g_imu_gz_dps;
}
```

## 5. JY61P 底层静态缓存变量

这些变量定义在：

```text
Core/Src/jy61p.c
```

它们带有 `static`，只能在 `jy61p.c` 内部访问，不能直接在其他 `.c` 文件中使用。

| 变量名 | 类型 | 含义 |
| --- | --- | --- |
| `g_jy61p_huart` | `static UART_HandleTypeDef *` | 当前绑定的 UART 句柄，来自 `JY61P_Init(&huart3)` |
| `g_uart_rx_byte` | `static uint8_t` | HAL 单字节中断接收缓冲 |
| `g_rx_buf[10]` | `static uint8_t[]` | JY61P 数据帧缓冲，不包含帧头 `0x55` |
| `g_rx_idx` | `static uint8_t` | 当前接收索引 |
| `g_rx_locked` | `static uint8_t` | 是否已经检测到帧头 |
| `g_data` | `static JY61P_DataTypeDef` | 底层解析后的最新一组 IMU 数据 |
| `g_ready_flags` | `static volatile uint8_t` | 底层新数据标志 |
| `g_packet_count` | `static volatile uint32_t` | 底层成功解析包数 |
| `g_checksum_error_count` | `static volatile uint32_t` | 底层校验错误数 |

对外读取这些底层数据时不要直接访问 `static` 变量，而是通过：

```c
JY61P_GetData(&imu);
JY61P_GetPacketCount();
JY61P_GetChecksumErrorCount();
```

`imu_app.c` 已经调用这些接口，并把结果复制到 `g_imu_*` 公开变量。

## 6. main.c 如何调用

### 6.1 头文件

在 `Core/Src/main.c` 的 USER CODE include 区加入：

```c
#include "board_app.h"
```

### 6.2 初始化顺序

在 CubeMX 生成的外设初始化之后调用 `Board_App_Init()`：

```c
MX_GPIO_Init();
MX_I2C1_Init();
MX_USART3_UART_Init();

Board_App_Init();
```

要求：

- `MX_I2C1_Init()` 必须在 `Board_App_Init()` 之前调用，因为激光驱动需要 `hi2c1`
- `MX_USART3_UART_Init()` 必须在 `Board_App_Init()` 之前调用，因为 JY61P 驱动需要 `huart3`
- `USART3 global interrupt` 必须在 CubeMX 的 NVIC 中启用，否则 JY61P 不会接收到数据

### 6.3 UART 接收回调

在 `main.c` 中添加或合并此回调：

```c
void HAL_UART_RxCpltCallback(UART_HandleTypeDef *huart)
{
    Board_App_UartRxCpltCallback(huart);
}
```

如果工程里已经有 `HAL_UART_RxCpltCallback()`，不要重复定义第二个同名函数。应该把下面这一行合并到已有函数内部：

```c
Board_App_UartRxCpltCallback(huart);
```

### 6.4 主循环

在 `while (1)` 中持续调用：

```c
while (1)
{
    Board_App_Loop();

    // 在这里写小车控制逻辑
}
```

`Board_App_Loop()` 内部会调用：

```c
IMU_App_Loop();
Laser_App_Loop();
```

其中：

- `IMU_App_Loop()` 将 JY61P 底层解析结果复制到 `g_imu_*`
- `Laser_App_Loop()` 周期性读取激光距离，并更新 `g_laser_*`

### 6.5 控制代码读取示例

```c
Board_App_Loop();

if ((g_laser_sample_count > 0U) && (g_imu_packet_count > 0U))
{
    uint16_t distance_mm = g_laser_distance_mm;
    float yaw_deg = g_imu_yaw_deg;
    float gz_dps = g_imu_gz_dps;

    // 根据 distance_mm, yaw_deg, gz_dps 控制电机
}
```

## 7. CubeIDE 调试读取数据步骤

### 7.1 生成和烧录前检查

在 CubeMX / CubeIDE 中确认：

1. `I2C1` 已启用，并 remap 到 `PB8/PB9`
2. `USART3` 已启用，`PB10 = USART3_TX`, `PB11 = USART3_RX`
3. `USART3` 参数为 `115200-8-N-1`
4. `USART3 global interrupt` 已启用
5. `PB6/PB7` 不要配置为 `I2C1`
6. 工程 include path 包含：

```text
Core/Inc
Drivers/VL53L1X/core/inc
Drivers/VL53L1X/platform/inc
```

### 7.2 进入 Debug

1. 用 ST-LINK 连接 STM32
2. 在 CubeIDE 点击 `Debug`
3. 进入 Debug 透视图后，程序通常会停在 `main()`
4. 点击 `Resume`，让程序开始运行

### 7.3 打开 Live Expressions

如果界面没有显示 Live Expressions：

```text
Window -> Show View -> Expressions
```

或：

```text
Window -> Show View -> Live Expressions
```

不同版本 CubeIDE 菜单名称略有差异。推荐使用 `Live Expressions`，它会在程序运行时周期刷新变量。

### 7.4 添加变量

在 Expressions 或 Live Expressions 中逐个添加：

```text
g_board_app_loop_count
g_laser_status
g_laser_module_id
g_laser_distance_mm
g_laser_sample_count
g_imu_roll_deg
g_imu_pitch_deg
g_imu_yaw_deg
g_imu_ax_g
g_imu_ay_g
g_imu_az_g
g_imu_gx_dps
g_imu_gy_dps
g_imu_gz_dps
g_imu_packet_count
g_imu_checksum_error_count
```

### 7.5 判断是否正常

先看：

```text
g_board_app_loop_count
```

应持续增加。若不增加，检查 `while (1)` 是否调用了 `Board_App_Loop()`。

再看激光：

```text
g_laser_status
g_laser_module_id
g_laser_sample_count
g_laser_distance_mm
```

正常现象：

- `g_laser_module_id` 应接近或等于 `0xEACC`
- `g_laser_status` 为 `0` 时表示 `ATK_MS53L1M_OK`
- `g_laser_sample_count` 持续增加
- `g_laser_distance_mm` 随障碍物距离变化

再看 JY61P：

```text
g_imu_packet_count
g_imu_checksum_error_count
g_imu_roll_deg
g_imu_pitch_deg
g_imu_yaw_deg
```

正常现象：

- `g_imu_packet_count` 持续增加
- `g_imu_checksum_error_count` 不应快速连续增加
- 转动模块时，`g_imu_roll_deg`, `g_imu_pitch_deg`, `g_imu_yaw_deg` 应变化

### 7.6 常见异常判断

| 现象 | 优先检查 |
| --- | --- |
| `g_board_app_loop_count` 不增加 | `main.c` 是否调用 `Board_App_Loop()` |
| `g_laser_status = 2` | 激光 I2C 接线、供电、`PB8/PB9` remap、模块 ID |
| `g_laser_sample_count` 不增加 | 激光初始化是否成功，`g_laser_status` 是否长期非 0 |
| `g_imu_packet_count` 不增加 | `USART3` 是否启用、`PB10/PB11` 是否接反、JY61P 波特率是否为 115200、NVIC 是否开启 |
| `g_imu_checksum_error_count` 快速增加 | 串口波特率错误、线过长、接地不可靠、电源噪声 |
| 姿态角不变化但 packet 增加 | JY61P 输出内容配置异常，使用上位机恢复默认输出 |

## 8. 推荐的调试顺序

1. 先只确认 `g_board_app_loop_count` 增加
2. 再确认 `g_laser_module_id == 0xEACC`
3. 再确认 `g_laser_sample_count` 增加
4. 再确认 `g_imu_packet_count` 增加
5. 最后观察 `g_laser_distance_mm` 和 `g_imu_yaw_deg`

不要一开始就看控制效果。先确认两个传感器数据都稳定，再写小车控制逻辑。

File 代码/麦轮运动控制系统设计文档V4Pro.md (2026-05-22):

# 麦轮运动控制系统技术设计文档

> **项目**：智能物流搬运小车 — 底盘运动控制
> **MCU**：STM32F103C8T6 / STM32CubeIDE / HAL 库
> **版本**：V1.0
> **日期**：2026-05-12

---

## 目录

1. [系统概述与引脚分配](#1-系统概述与引脚分配)
2. [多电机 RS485 总线通信与寻址](#2-多电机-rs485-总线通信与寻址)
3. [电机实时转速反馈与闭环控制](#3-电机实时转速反馈与闭环控制)
4. [麦克纳姆轮运动学模型与速度分解](#4-麦克纳姆轮运动学模型与速度分解)
5. [传感器融合与航向稳定控制](#5-传感器融合与航向稳定控制)
6. [控制流程总图与 HAL 外设清单](#6-控制流程总图与-hal-外设清单)

---

## 1. 系统概述与引脚分配

### 1.1 系统架构

```
┌─────────────────────────────────────────────────────────┐
│                    树莓派 4B (上位机)                      │
│  视觉识别 · 路径规划 · 任务调度                             │
│  UART (经 CH340-1) ↔ STM32 UART1                        │
└──────────────────────┬──────────────────────────────────┘
                       │ 自定义二进制帧协议 (115200-8N1)
┌──────────────────────▼──────────────────────────────────┐
│              STM32F103C8T6 (运动控制核心)                  │
│                                                         │
│  ┌──────────┐  ┌──────────┐  ┌──────────────────────┐  │
│  │ UART3    │  │ I2C1     │  │ UART2 → RS485 总线    │  │
│  │ JY61P    │  │ MS53L1M  │  │ 4× ZDT_X42 步进电机   │  │
│  │ 姿态/航向 │  │ 距离感知  │  │ Modbus-RTU (半双工)   │  │
│  └──────────┘  └──────────┘  └──────────────────────┘  │
│                                                         │
│  核心任务：                                               │
│  · 麦轮逆运动学解算 (vx,vy,ω → RPM1~4)                    │
│  · 航向闭环纠偏 (JY61P Yaw → PI 修正角速度)               │
│  · Modbus 多机轮询与同步控制                               │
│  · 通讯超时安全停车                                       │
└─────────────────────────────────────────────────────────┘
```

### 1.2 完整引脚分配

| 外设 | STM32 引脚 | 功能 | 备注 |
|---|---|---|---|
| 树莓派通讯 | PA9 (TX), PA10 (RX) | USART1 | 经板载 CH340-1 |
| JY61P IMU | PB10 (TX), PB11 (RX) | USART3 | 115200-8N1, 3.3V TTL |
| MS53L1M 激光 | PB6 (SCL), PB7 (SDA) | I2C1 | 100kHz, 地址 0x52 |
| RS485 总线 | PA2 (TX), PA3 (RX) | USART2 | 经 SP3485 转 RS485 |
| RS485 方向控制 | **PA1** | GPIO 推挽输出 | DE/RE 联合控制（高=发送，低=接收） |
| 急停按钮 | PB12 | GPIO 外部中断 | 双沿触发 |
| 状态 LED | PC13 | GPIO 推挽输出 | 低电平点亮，板载 LED |

> **RS485 方向引脚说明**：SP3485 的 DE（发送使能）和 RE（接收使能）可并联由同一 GPIO 控制。PA1 输出高 → 发送模式，PA1 输出低 → 接收模式。SP3485 内部 RE 为低有效，DE 为高有效，并联后逻辑自洽。

### 1.3 现有代码资产

以下驱动文件已在 `D:\STM32CubeIDE\workspace_1.19.0\ATK-YJ` 中就绪：

| 文件 | 功能 | 注意事项 |
|---|---|---|
| `jy61p.c/h` | JY61P 驱动 | **当前为 I2C 实现**，本阶段需改为 UART 接收（JY61P 模块默认串口输出 0x55 帧头数据包） |
| `atk_ms53l1m.c/h` | VL53L1X I2C 驱动 | 已集成 ST 官方 API，距离读取 OK |
| `imu_app.c/h` | IMU 应用层 | 封装数据获取接口 |
| `laser_app.c/h` | 激光应用层 | 封装周期读取 |
| `board_app.c/h` | 板级应用入口 | 统一初始化 + 主循环调度 |

---

## 2. 多电机 RS485 总线通信与寻址

### 2.1 从机地址分配与修改

四台 ZDT_X42 驱动板出厂默认地址通常均为 `0x01`，必须逐一修改为不同地址才能在同一 RS485 总线上工作。

**修改方法**：

1. **逐台上电修改**：每次仅给一台驱动板供电，通过 Modbus 写寄存器命令修改其从机地址，保存后断电
2. **目标地址分配**：

| 物理位置 | 新 Modbus 地址 | 说明 |
|---|---|---|
| 左前轮 (FL) | 0x01 | Front-Left |
| 右前轮 (FR) | 0x02 | Front-Right |
| 左后轮 (RL) | 0x03 | Rear-Left |
| 右后轮 (RR) | 0x04 | Rear-Right |

3. **地址修改寄存器**（ZDT_X42 通用寄存器）：

| 操作 | 寄存器地址 | 写入值 | 说明 |
|---|---|---|---|
| 设置从机地址 | `0x0020` | `0x0001` ~ `0x0004` | 写新地址 |
| 保存参数到 EEPROM | `0x0007` | `0x0001` | 掉电保存，否则重新上电恢复默认 |

4. **操作流程**：

```
单台驱动板加电 → 等待自检完成 (OLED 正常显示)
  → Modbus 写 0x0020 = 目标地址
  → Modbus 写 0x0007 = 0x0001 (保存)
  → 断电
  → 换下一台，重复
```

> 修改后需用新地址重新建立通信，确认读取寄存器 `0x0010`（固件版本）返回值正确。

---

### 2.2 Modbus-RTU 帧结构

#### 2.2.1 标准帧格式（以写速度指令为例）

Modbus-RTU 通用帧结构：

| 字段 | 字节数 | 内容 |
|---|---|---|
| 从机地址 | 1 | `0x01` ~ `0x04` |
| 功能码 | 1 | `0x10`（写多个寄存器）或 `0x06`（写单个寄存器） |
| 寄存器起始地址 | 2 | 高字节在前 |
| 寄存器数量 | 2 | 高字节在前 |
| 数据字节数 | 1 | N（寄存器数 × 2） |
| 数据 | N | 高字节在前 |
| CRC16 | 2 | 低字节在前 |

#### 2.2.2 直通限速位置模式指令帧

设置电机以指定速度和方向连续运转（无限位），使用 ZDT 自定义功能码 `0xFB`：

| 字段 | 值 | 说明 |
|---|---|---|
| 从机地址 | `0x01` ~ `0x04` | 单播控制 |
| 功能码 | `0xFB` | ZDT 自定义：直通速度控制 |
| 寄存器地址 | `0x00F0` | 控制命令寄存器 |
| 方向 | 2 bytes | `0x0000` = 正向（CW），`0x0001` = 反向（CCW） |
| 速度 | 2 bytes | 目标转速 RPM，无符号整数 |
| 位置/角度 | 4 bytes | 直通模式填 `0x00000000` |
| CRC16 | 2 bytes | 标准 Modbus CRC（多项式 `0xA001`） |

**完整帧示例**——左前轮（0x01）正向 60 RPM：

```
01 FB 00F0 0000 003C 00000000 [CRC_LO] [CRC_HI]
```

> **注意**：`0xFB` 为 ZDT 自定义功能码，其帧结构与标准 Modbus 写操作类似但在数据段格式上有所差异。ZDT 官方例程代码中的帧封装函数应直接复用，避免自行拼接导致格式错误。

#### 2.2.3 读取实时转速帧

| 字段 | 值 | 说明 |
|---|---|---|
| 从机地址 | `0x01` ~ `0x04` | 单播 |
| 功能码 | `0x03` | 标准 Modbus 读保持寄存器 |
| 寄存器起始地址 | `0x0022` | 实时转速寄存器 |
| 寄存器数量 | `0x0001` | 读 1 个寄存器（2 字节） |
| CRC16 | 2 bytes | |

**响应帧**：

| 字段 | 说明 |
|---|---|
| 从机地址 | 原地址 |
| 功能码 | `0x03` |
| 数据字节数 | `0x02` |
| 转速值 | 2 bytes，有符号 16 位，单位 RPM |
| CRC16 | 2 bytes |

#### 2.2.4 读取实时位置（编码器累计角度）

| 寄存器地址 | 长度 | 数据类型 | 说明 |
|---|---|---|---|
| `0x0024` | 2 registers (4 bytes) | int32 | 当前编码器累计角度（需按细分数换算） |

#### 2.2.5 多机同步广播帧

使所有已接收运动指令的电机同时启动：

| 字段 | 值 | 说明 |
|---|---|---|
| 从机地址 | `0x00` | 广播地址 |
| 功能码 | `0xFF` | 自定义 |
| 子命令 | `0x66` | 触发多机同步运动 |
| CRC16 | 2 bytes | |

---

### 2.3 单播轮询 vs 广播控制策略

**速度指令下发采用「单播参数 + 广播同步」方案**：

```
┌──────────────────────────────────────────────────────┐
│ 控制周期 10ms (100Hz)                                 │
│                                                      │
│  1. 逆运动学解算 → 得到四轮目标 RPM (r1,r2,r3,r4)       │
│                                                      │
│  2. 单播写入四台电机 (顺序发送，利用 RS485 半双工):        │
│     for addr in [0x01, 0x02, 0x03, 0x04]:            │
│         RS485_TX_Enable()                            │
│         HAL_UART_Transmit(addr, 0xFB, rpm, ...)       │
│         RS485_Wait_TX_Complete()    ← 等待 UART TC     │
│         RS485_RX_Enable()                            │
│                                                      │
│  3. 广播同步触发 (可选，仅在需四轮严格同时启动时):         │
│     RS485_TX_Enable()                                │
│     HAL_UART_Transmit(0x00, 0xFF 0x66, ...)           │
│     RS485_RX_Enable()                                │
│                                                      │
│  ⚠ 广播同步会中断所有电机当前动作并执行新指令            │
│     对于连续速度控制场景，可省略同步帧，直接单播覆盖       │
└──────────────────────────────────────────────────────┘
```

**策略选择**：

| 场景 | 推荐方式 | 理由 |
|---|---|---|
| 连续速度更新（100Hz） | 单播轮询，不广播 | 逐次更新已在 10ms 内完成，无需额外的同步开销 |
| 启停 / 离散位置指令 | 单播参数 + 广播同步 | 确保四轮严格同时启动 / 停止 |
| 紧急停车 | 广播帧最高优先 | 地址 0x00 的停止指令所有电机同时响应 |

---

### 2.4 RS485 半双工收发切换时序

```
        发送阶段                           接收阶段
  ┌──────────────────┐              ┌──────────────────┐
  │ PA1 = HIGH (DE=1) │              │ PA1 = LOW (RE=0)  │
  │ 发送使能           │              │ 接收使能           │
  └──────────────────┘              └──────────────────┘
         ↑                                  ↑
         │                                  │
  ┌──────┴──────────────────────────────────┴──────┐
  │             RS485 收发控制软件流程               │
  │                                                │
  │  1. PA1 = HIGH          (DE/RE → 发送)          │
  │  2. Delay 50μs          (等待发送器稳定)          │
  │  3. HAL_UART_Transmit() (启动 DMA / IT 发送)     │
  │  4. 等待 UART_TC 标志   (发送完成，非 TXE)        │
  │  5. Delay 50μs          (等待最后一个停止位发出)    │
  │  6. PA1 = LOW           (DE/RE → 接收)           │
  └────────────────────────────────────────────────┘
```

**时序注意事项**：

| 要点 | 说明 |
|---|---|
| **发送完成判断** | 必须用 `UART_FLAG_TC`（发送完成标志），不能用 `UART_FLAG_TXE`（发送缓冲区空）。TXE 在最后一个字节移入移位寄存器时立即置位，此时数据还在总线上 |
| **TC 后延时** | SP3485 在 115200bps 下每 bit 约 8.68μs，一个停止位后需等待至少 8.68μs。50μs 延时含足量裕度 |
| **使能后延时** | SP3485 驱动器使能到输出稳定典型值 < 2μs，50μs 为保守值，确保总线电平建立 |
| **默认状态** | 系统初始化后 PA1 = 0（接收模式），总线处于监听状态 |
| **DMA 发送** | 若使用 DMA，在 `HAL_UART_TxCpltCallback` 中启动一个硬件定时器单次延时（约 100μs），超时后再切换为接收模式 |

**推荐实现**：使用定时器（TIM4）通道产生精确延时，硬件自动在延时结束后置 PA1 为低。避免在中断服务函数中用软件延时死等。

---

### 2.5 Modbus CRC16 校验

- 多项式：`0xA001`（Modbus 标准，初始值 `0xFFFF`）
- 算法：查表法或逐位计算，参考 ZDT 官方例程中的 `CRC16_Modbus()` 函数
- 校验范围：从地址字节到数据段最后一字节（不含 CRC 自身）

---

## 3. 电机实时转速反馈与闭环控制

### 3.1 转速反馈读取

#### 寄存器定义

| 参数 | 值 |
|---|---|
| 寄存器地址 | `0x0022` |
| 功能码 | `0x03`（读保持寄存器） |
| 数据长度 | 1 个寄存器（2 字节） |
| 数据类型 | `int16`，单位 RPM |
| 符号 | 正值 = CW（正向），负值 = CCW（反向） |

> **换算**：直接使用 int16 值即为 RPM，无需额外运算。若需转换为轮缘线速度（mm/s）：`v = RPM × π × 75 / 60`。

#### 四电机转速同时读取策略

由于 RS485 为半双工，无法并行读取，采用 **顺序轮询**：

```
每个速度反馈周期 (20ms, 50Hz):
  for addr in [0x01, 0x02, 0x03, 0x04]:
      RS485_TX_Enable()
      HAL_UART_Transmit(read_speed_frame[addr])
      等待接收响应 (UART RX 中断 / DMA 接收)
      RS485_RX_Enable()
      parsed_speed[addr] = response.rpm_value
```

**单帧读取耗时估算**（115200bps）：
- 请求帧 8 字节：~0.7ms
- 响应帧 7 字节：~0.6ms
- 收发切换 + 等待：~0.2ms
- **单电机合计**：~1.5ms
- **四电机轮询**：~6ms

**控制周期 = 10ms，反馈周期 = 20ms 的柱状调度**：

```
时间轴 (ms)：  0    2    4    6    8   10   12   14   16   18   20
              ├────┼────┼────┼────┼────┼────┼────┼────┼────┼────┤
控制帧 (10ms): [写4电机速度]       [写4电机速度]       [写4电机速度]
反馈帧 (20ms): [读M1][读M2][读M3][读M4]              [读M1]...
```

> 反馈周期慢于控制周期的设计是合理的——电机速度环的响应远大于机械时间常数，50Hz 反馈速率足够。

---

### 3.2 主控侧速度 PID 设计

#### 3.2.1 是否需要额外 PID？

ZDT_X42 驱动板内部已完成「电流-速度-位置」三环 FOC 闭环控制。但以下因素决定了 **主控侧仍需加一层速度 PID**：

| 因素 | 说明 |
|---|---|
| **打滑补偿** | 电机编码器测的是电机轴转速，不是车轮对地面的真实速度。地面打滑时编码器读数正常但实际位移为零。PID 积分项可补偿打滑引起的速度偏差 |
| **响应速度** | ZDT 内部速度环参数出厂默认，未针对负载惯量调优。主控侧 PID 可加快整体速度响应 |
| **多轮协调** | 四个电机独立运行内部闭环，无法感知整体运动状态（航向偏转、轨迹偏移）。主控 PID 可引入全局误差修正 |
| **抗扰动** | 地面不平、负载变化等外部扰动，主控侧可通过前馈 + 反馈改善抗扰性能 |

**结论**：主控侧增加一层「外环速度 PID」，架构为 **级联控制**：

```
                        外环 (STM32)                     内环 (ZDT_X42)
                     ┌─────────────────┐            ┌──────────────────┐
期望速度 (RPM) ──→[Σ]→ PID → 修正后 RPM ──→ Modbus ──→ ZDT 内部三环闭环
                   ↑                             │
                   │                    ┌────────┘
                   │                    │ Modbus 回读
                   └──── 实际 RPM ←────┘
```

#### 3.2.2 PID 控制框图（完整级联架构）

```
                            ┌── 航向修正 ω_corr ──┐
                            │   (来自 5.2 节)       │
                            │                       │
  (vx,vy,ω)_cmd ──→ 逆运动学 ──→ r1~r4_cmd ──→ [Σ] ──→ PID_i ──→ Modbus 写 RPM ──→ ZDT_X42 电机
                            │                   ↑                        │
                            │                   │                        │
                            │         ┌─ 实际 RPM 回读 ←── Modbus 读 ────┘
                            │         │
                            └─ 前馈 ──┘  (feedforward: r_cmd 直接写入)
```

**工作模式**：前馈 + 反馈 PID

- **前馈通道**：逆运动学解算后的目标 RPM 直接写入电机（快速响应）
- **反馈通道**：`误差 = 目标 RPM − 实际 RPM`，经 PI 控制器产生修正增量
- **前馈 + 反馈叠加**：`最终指令 = 前馈 RPM + PI 修正值`

#### 3.2.3 PID 参数与控制周期

| 参数 | 建议值 | 依据 |
|---|---|---|
| 控制周期 T | **10ms (100Hz)** | 电机机械时间常数 ~50-100ms；100Hz 控制频率高于机械带宽 10× 以上，满足采样定理 |
| Kp | 0.3 ~ 0.8 | 先调，使电机快速跟踪目标，不振荡 |
| Ki | 0.05 ~ 0.2 | 消除稳态误差（打滑、负载不均引起） |
| Kd | **0（不使用）** | 反馈信号经 Modbus 通信已有 10-20ms 延迟，微分项会放大噪声 |
| 积分分离阈值 | `abs(error) < 30 RPM` | 大误差时不积分，防积分饱和 |
| 输出限幅 | ± 额定转速的 30% | PID 输出叠加到前馈上，防止指令越界 |

**离散化公式（位置式 PI）**：

```
u(k) = Kp × e(k) + Ki × T × Σ e(i)
最终 RPM = 前馈_目标RPM + u(k)
限幅: 最终 RPM ∈ [−MaxRPM, +MaxRPM]
```

#### 3.2.4 回读速度滤波与异常值处理

| 策略 | 参数 | 说明 |
|---|---|---|
| **低通滤波** | α = 0.3（一阶 IIR） | `filtered_rpm = α × raw_rpm + (1−α) × prev_filtered_rpm` |
| **跳变检测** | Δ > 200 RPM / 20ms | 若相邻两次回读差值超过阈值，判定为通信干扰/误码，丢弃本次值，沿用上次值 |
| **超时保护** | 1s 无响应 | 单电机连续 1 秒无 Modbus 应答 → 触发告警，强制停车 |
| **CRC 校验失败** | 重试 1 次 | Modbus 响应 CRC 错误时，重发一次读取帧；两次均失败则标记为通信异常 |

---

### 3.3 电机初始化流程

```
上电 → 等待 2s (自检)
  → for each addr in [0x01, 0x02, 0x03, 0x04]:
       ├─ 读 0x3B (回零状态标志位)，确认编码器就绪
       ├─ 读 0x0010 (固件版本)，记录
       ├─ 写 0x000A = 0x0001 (位置清零)
       └─ 读当前状态，确认无故障码
  → 初始化完成标志位置 1
  → 等待上位机运动指令
```

**故障码检查**：驱动板出现异常时，特定寄存器会置位。建议在初始化阶段读取一次故障状态寄存器，确认四台电机均处于正常状态后再进入运动控制。

---

## 4. 麦克纳姆轮运动学模型与速度分解

### 4.1 坐标系与轮序定义

```
                  +Y (前方)
                    ↑
                    │
          ┌─────────┼─────────┐
          │         │         │
          │  轮1(FL)│  轮2(FR) │
          │  ／     │     ＼   │
          │ 辊方向  │  辊方向   │
          │         │         │
   ←──────┼─────────┼─────────┼──────→ +X (右方)
          │         │         │
          │  轮4(RL)│  轮3(RR) │
          │  ＼     │     ／   │
          │ 辊方向  │  辊方向   │
          │         │         │
          └─────────┴─────────┘
```

**X 形布局**：四轮辊子方向形成 "X" 图案（从上方俯视）。左前(1)和右后(4)辊子方向一致，右前(2)和左后(3)辊子方向一致。

| 轮序号 | 物理位置 | Modbus 地址 | 电机安装方向 |
|---|---|---|---|
| 1 | 左前 (Front-Left) | 0x01 | 正装，辊子 \ 方向 |
| 2 | 右前 (Front-Right) | 0x02 | 正装，辊子 / 方向 |
| 3 | 右后 (Rear-Right) | 0x03 | 正装，辊子 / 方向 |
| 4 | 左后 (Rear-Left) | 0x04 | 正装，辊子 \ 方向 |

### 4.2 机械参数

| 参数 | 符号 | 值 | 单位 |
|---|---|---|---|
| 麦轮直径 | D | 75 | mm |
| 轮半径 | R | 37.5 | mm |
| 轮距（左右中心距） | W | 320 | mm |
| 轴距（前后中心距） | L | 220 | mm |
| 半轮距 | W/2 = b | 160 | mm |
| 半轴距 | L/2 = a | 110 | mm |
| 旋转力臂 | a + b | 270 | mm |

### 4.3 逆运动学方程（全局速度 → 四轮转速）

已知小车的目标全局运动 `(v_x, v_y, ω)`：
- `v_x`：沿 X 轴（横向）的线速度，m/s
- `v_y`：沿 Y 轴（纵向）的线速度，m/s
- `ω`：绕 Z 轴（垂直轴）的旋转角速度，rad/s，逆时针为正

**X 形布局逆运动学矩阵**：

```
┌      ┐    1   ┌                          ┐ ┌     ┐
│ v_1  │   ───  │  1    −1    −(a + b)     │ │ v_x │
│ v_2  │ =  R  │  1    +1    +(a + b)     │ │ v_y │
│ v_3  │       │  1    +1    −(a + b)     │ │  ω  │
│ v_4  │       │  1    −1    +(a + b)     │ └     ┘
└      ┘       └                          ┘
```

展开为标量形式：

```
v_1 = v_x − v_y − (a+b) × ω      (左前轮)
v_2 = v_x + v_y + (a+b) × ω      (右前轮)
v_3 = v_x + v_y − (a+b) × ω      (右后轮)
v_4 = v_x − v_y + (a+b) × ω      (左后轮)
```

其中 `a+b = 0.110 + 0.160 = 0.270 m`。

**线速度 v_i 转 RPM**：

```
RPM_i = v_i × 60 / (π × D)
      = v_i × 60 / (π × 0.075)
      = v_i × 254.65
```

**完整逆运动学伪代码**：

```c
#define WHEEL_DIAMETER_m      0.075f    // 轮径 75mm
#define HALF_WHEELBASE_m      0.110f    // 半轴距 a = 220/2 mm
#define HALF_TRACK_m          0.160f    // 半轮距 b = 320/2 mm
#define ROTATION_ARM_m        (HALF_WHEELBASE_m + HALF_TRACK_m)  // 0.270m
#define RPM_PER_MPS           (60.0f / (PI * WHEEL_DIAMETER_m))  // 254.65

// 输入: vx, vy (m/s), omega (rad/s)
// 输出: rpm[4] (RPM, 正值=正转, 负值=反转)
void Mecanum_InverseKinematics(float vx, float vy, float omega,
                               float rpm[4])
{
    // 四轮线速度 (m/s)
    float v[4];
    v[0] = vx - vy - ROTATION_ARM_m * omega;   // FL
    v[1] = vx + vy + ROTATION_ARM_m * omega;   // FR
    v[2] = vx + vy - ROTATION_ARM_m * omega;   // RR
    v[3] = vx - vy + ROTATION_ARM_m * omega;   // RL

    // 线速度转 RPM
    for (int i = 0; i < 4; i++) {
        rpm[i] = v[i] * RPM_PER_MPS;
    }
}
```

### 4.4 超限等比缩放

当任一目标轮转速超过电机额定转速时，需等比缩小所有四轮转速以保持速度方向不变：

```c
float Mecanum_ScaleToLimit(float rpm[4], float max_rpm)
{
    float max_abs = 0.0f;
    for (int i = 0; i < 4; i++) {
        float abs_rpm = fabsf(rpm[i]);
        if (abs_rpm > max_abs) max_abs = abs_rpm;
    }

    if (max_abs > max_rpm) {
        float scale = max_rpm / max_abs;
        for (int i = 0; i < 4; i++) {
            rpm[i] *= scale;
        }
    }
    return max_abs;  // 返回缩放前的最大绝对值，供调用方判断是否触发了缩放
}
```

> **缩放的意义**：当用户指令 `(vx, vy, ω)` 导致某轮转速超限时，等比缩放保留速度方向（运动意图），只降低幅值。这在转向 + 平移叠加指令中尤为关键——如果直接硬限幅，轨迹方向会改变。

### 4.5 正运动学（里程计推算）

四轮实际 RPM 反推小车的全局速度，用于里程计积分：

```
v_x = (RPM_1 + RPM_2 + RPM_3 + RPM_4) × (πD / 4) / 60
v_y = (−RPM_1 + RPM_2 + RPM_3 − RPM_4) × (πD / 4) / 60
ω   = (−RPM_1 + RPM_2 − RPM_3 + RPM_4) × (πD / 4) / (60 × (a+b))
```

> 正运动学用于里程计推算位置，与激光/IMU 数据融合（见第 5 节）。

---

## 5. 传感器融合与航向稳定控制

### 5.1 JY61P 陀螺仪数据接口

#### 通信方式说明

当前 `jy61p.c` 为 I2C 实现，但根据硬件手册，JY61P 模块在 UART 模式下直接输出固定格式数据包（无需请求帧），本阶段需将驱动改造为 **USART3 中断接收 + DMA 环形缓冲**。

#### UART 数据包格式

- 角度包（核心使用）：帧头 `0x55 0x53`，8 字节角度数据（Roll/Pitch/Yaw 各 2 字节 int16，0.01°），1 字节校验和
- 角速度包（航向阻尼用）：帧头 `0x55 0x52`，含三轴角速度

**数据包解析状态机**：

```
IDLE → 收到 0x55 → WAIT_TYPE → 收到 0x53(角度)/0x52(角速度)/0x51(加速度)
      → WAIT_DATA → 累积 8 字节 → WAIT_CHECKSUM
      → 校验通过 → 解析并更新全局变量 → IDLE
      → 校验失败 → g_imu_checksum_error_count++ → IDLE
```

#### JY61P 初始化配置流程

1. 上电后等待 300ms，模块进入默认串口数据输出模式（默认 10Hz，按已保存配置输出）
2. 如需修改输出速率或内容：解锁（写 `0x69 = 0xB588`）→ 写 RSW（`0x02`）设置输出内容 → 写 RRATE（`0x03`）设置速率至 **100Hz** → 保存（写 `0x00 = 0x0000`）
3. 航向角置零（校准）：解锁 → 写 `0x01 = 0x0004` → 保存

> **建议**：首次使用时通过上位机软件配置好 100Hz 输出速率并保存，之后每次上电自动恢复配置。100Hz 输出速率匹配 10ms 控制周期的需求。

---

### 5.2 航向角闭环纠偏控制

#### 控制目标

直线行驶时（目标角速度 ω_target = 0），利用 JY61P 航向角反馈自动修正因地面不平、轮径差异等引起的航向漂移，保持小车沿直线运动。

#### 控制架构：级联修正

```
                           ┌─────────────┐
   目标航向 Yaw_target ──→ [Σ] → P 控制器 → ω_corr
                           ↑               (角速度修正量)
                           │                   │
                    实际 Yaw ←── JY61P         │
                                           ┌──▼──────────────┐
   原始运动指令 (vx, vy, ω_cmd) ──────────→ 逆运动学解算       │
                                           │ ω_actual =       │
                                           │ ω_cmd + ω_corr   │
                                           └──────────────────┘
```

**核心公式**：

```
Yaw_error = Yaw_target − Yaw_current      // 航向角误差, 需归一化到 [−180°, +180°]
ω_corr = Kp_yaw × Yaw_error               // P 控制器输出角速度修正量
ω_actual = ω_cmd + ω_corr                 // 修正后的角速度输入逆运动学
```

#### 参数说明

| 参数 | 建议值 | 说明 |
|---|---|---|
| Kp_yaw | 0.5 ~ 2.0 | 航向 P 增益。单位：rad/s / rad。Kp=1 表示 1rad 误差产生 1rad/s 修正角速度（约 57°/s 修正速率） |
| 角度归一化函数 | — | 将 Yaw_error 归一化到 [−180°, +180°]，避免跨 ±180° 跳变 |
| 死区 | ±1° | Yaw_error 在 ±1° 以内不触发修正，避免微幅振荡 |
| 输出限幅 | ω_corr ∈ [−ω_max, +ω_max] | 防止航向修正过度干扰正常转向指令 |

> **为何用 P 而非 PI？** 航向角系统本身含有积分特性（角速度积分 = 角度），P 控制已能消除稳态角误差。引入 I 项容易在小车机动时产生积分饱和，需要复杂的积分分离和抗饱和逻辑，得不偿失。

---

### 5.3 ATK-MS53L1M 激光测距辅助定位

#### 当前可用能力

- 测距范围：40mm ~ 4000mm（长距离模式）
- 当前驱动状态：已集成 ST 官方 VL53L1X API，通过 `ATK_MS53L1M_ReadDistance()` 获取距离值（`g_laser_distance_mm`）
- 测量周期：~150ms（`SetInterMeasurementPeriodMilliSeconds(150)` 设定）

#### 辅助功能

**A. 沿墙走（Wall Following）**

保持小车与墙面恒定距离，适用于走廊 / 货架间导航：

```
IF 侧面激光测距值 < 目标距离 − 阈值:
    vx_adjust = −K_wall × (目标距离 − 当前距离)  // 远离墙
ELIF 侧面激光测距值 > 目标距离 + 阈值:
    vx_adjust = +K_wall × (当前距离 − 目标距离)  // 靠近墙
```

**B. 点到点减速控制**

接近目标位置时，根据激光测距值自动减速，防止惯性过冲：

```
IF 前方距离 < 减速阈值 (如 500mm):
    vy_cmd = vy_cmd × (当前距离 / 减速阈值)  // 线性减速
    IF 前方距离 < 停止阈值 (如 100mm):
        vy_cmd = 0;  紧急停车
```

**C. 特征匹配与位置重置**

利用激光检测已知结构（墙壁转角、货架立柱等），将这些特征点作为里程计误差的消除机会：

```
IF 检测到特征点（距离突变 > 阈值）:
    推算当前位置 = 特征点已知坐标 + 当前测距偏移
    重置里程计累计位置
```

#### 里程计 + 激光融合策略

```
                里程计 (正运动学，高频 100Hz)
                ├── 短期精度高，长期有积分漂移
                │
位置估计 ────── 激光测距 (低频 ~7Hz)
                ├── 提供绝对距离参考
                ├── 沿墙方向：修正横向漂移
                └── 前进方向：修正纵向里程计漂移
```

> **具体融合算法**：在沿墙走场景，激光提供垂直于墙面的绝对距离，作为该方向的「地面真相」。每次激光数据更新时，以 α=0.1 的指数平滑修正里程计在该方向上的累计位移。前进方向由于激光只能探测前方障碍物（无法感知已走过的路径），仅依赖里程计。

---

### 5.4 综合运动状态机

```
┌─────────┐
│   INIT  │ 上电，JY61P 航向置零，读取初始航向角
└────┬────┘
     │ 初始化完成
     ▼
┌─────────┐
│ STANDBY │ 等待上位机运动指令
└────┬────┘
     │ 收到目标速度向量 (vx, vy, ω) 或 目标点坐标
     ▼
┌──────────────┐
│ TARGET_ALIGN │ 计算目标航向角 Yaw_target = atan2(dy, dx)
└──────┬───────┘
     │
     ▼
┌──────────┐
│ MOVING   │ 循环执行 (100Hz):
│          │   1. 读取 JY61P Yaw
│          │   2. 计算 Yaw_error, 得出 ω_corr
│          │   3. 读取 MS53L1M 距离 → 减速判断 / 沿墙修正
│          │   4. 更新目标速度 (vy 根据距离衰减)
│          │   5. 逆运动学解算 (vx, vy, ω_corr) → RPM[4]
│          │   6. 速度 PI + 前馈 → Modbus 写入四个电机
│          │   7. (每 2 周期) 读取四电机实际转速反馈
│          │   8. 正运动学累积里程计
└────┬─────┘
     │
     ├── 激光距离 < 停止阈值? ──→ STOPPED (到达)
     ├── 急停信号? ──→ EMERGENCY_STOP
     └── 上位机停止指令? ──→ STOPPED
          │
          ▼
     ┌──────────┐
     │ ARRIVED  │ → 上报到达事件 → STANDBY
     └──────────┘

┌───────────────┐
│ EMERGENCY_STOP│ 立即发送广播停止帧 (addr=0x00, 功能码 停止)
└───────────────┘
   急停解除 + 上位机复位指令 → STANDBY
```

---

## 6. 控制流程总图与 HAL 外设清单

### 6.1 控制流程总图（Mermaid）

```mermaid
flowchart TB
    subgraph 上位机["树莓派 4B (上位机)"]
        CMD["运动指令 (vx, vy, ω) / 目标点"]
    end

    CMD -->|"UART1 (CH340)"| PARSE["指令解析"]

    subgraph STM32["STM32F103C8T6 主循环 (10ms 周期)"]
        PARSE --> SENSOR["传感器数据采集"]
        
        subgraph SensorBlock["传感器采集"]
            SENSOR --> IMU["JY61P UART3 解析\nYaw / GyroZ"]
            SENSOR --> LASER["MS53L1M I2C1\n读距离值"]
        end
        
        IMU --> YAWCTL["航向闭环 P 控制\nYaw_error → ω_corr"]
        
        subgraph MotionCalc["运动解算"]
            YAWCTL --> KIN["麦轮逆运动学\n(vx,vy,ω_corr)→RPM[4]"]
            LASER --> DISTCTL["距离减速 / 沿墙修正\n调整 vy 或 vx"]
            DISTCTL --> KIN
        end
        
        KIN --> PID["速度前馈 + PI 反馈\n目标 RPM → 修正后 RPM"]
        
        subgraph MotorIO["电机通信 (RS485)"]
            PID --> TX["单播写入 4 电机\n0x01→0x02→0x03→0x04"]
            TX --> RX["反馈周期 (20ms)\n轮询读取实际 RPM"]
            RX -->|"实际 RPM"| PID
        end
        
        IMU --> ODOM["正运动学里程计\n累计位置估计"]
    end

    TX -->|"RS485 Modbus"| M1["ZDT_X42 #1\n左前 0x01"]
    TX -->|"RS485 Modbus"| M2["ZDT_X42 #2\n右前 0x02"]
    TX -->|"RS485 Modbus"| M3["ZDT_X42 #3\n右后 0x03"]
    TX -->|"RS485 Modbus"| M4["ZDT_X42 #4\n左后 0x04"]
```

### 6.2 数据流汇总表

| 数据 | 方向 | 频率 | 途径 |
|---|---|---|---|
| 运动指令 (vx, vy, ω) | 树莓派 → STM32 | 50-100Hz | UART1 (CH340) |
| 底盘状态回传 | STM32 → 树莓派 | 10-20Hz | UART1 (CH340) |
| JY61P 角度/角速度 | JY61P → STM32 | 100Hz (自动输出) | USART3 |
| MS53L1M 距离 | MS53L1M → STM32 | ~7Hz | I2C1 |
| 速度 RPM 指令 | STM32 → ZDT_X42 ×4 | 100Hz | RS485 (USART2) |
| 速度 RPM 回读 | ZDT_X42 ×4 → STM32 | 50Hz | RS485 (USART2) |
| 紧急停止 | STM32 → ZDT_X42 ×4 | 事件触发 | RS485 (广播) |

### 6.3 HAL 外设清单与配置

| 外设 | 实例 | 引脚 | 配置 | 用途 |
|---|---|---|---|---|
| USART1 | huart1 | PA9 TX, PA10 RX | 115200-8N1, RX IT/DMA | 上位机通信 |
| USART2 | huart2 | PA2 TX, PA3 RX | 115200-8N1, RX IT + TX DMA | RS485 Modbus |
| USART3 | huart3 | PB10 TX, PB11 RX | 115200-8N1, RX DMA 环形缓冲 | JY61P IMU 数据接收 |
| I2C1 | hi2c1 | PB6 SCL, PB7 SDA | 100kHz, 7-bit | VL53L1X 激光测距 |
| TIM2 | htim2 | — | 72MHz, PSC=71, ARR=9999 → 100Hz | 主控制周期定时器 |
| TIM4 | htim4 | — | 72MHz, 单脉冲模式 | RS485 方向切换精确延时 |
| GPIO | PA1 | 推挽输出 | 默认 LOW | RS485 DE/RE 方向控制 |
| GPIO | PB12 | 外部中断 | 双沿触发 | 急停按钮 |
| GPIO | PC13 | 推挽输出 | 默认 HIGH (LED 灭) | 状态指示 |

#### 定时器详细配置

**TIM2 — 主控制周期 (100Hz)**：

| 参数 | 值 |
|---|---|
| 时钟源 | APB1 Timer Clock = 72MHz |
| 预分频器 (PSC) | 71（计数频率 1MHz） |
| 自动重装载 (ARR) | 9999（周期 = 10000 × 1μs = 10ms） |
| 中断 | TIM2 更新中断，在 ISR 中设置控制循环标志位 |
| 优先级 | 抢占优先级 2，子优先级 0 |

**TIM4 — RS485 方向切换延时**：

| 参数 | 值 |
|---|---|
| 模式 | 单脉冲模式 (One Pulse Mode) |
| 预分频器 | 71（计数频率 1MHz） |
| ARR | 99（100μs 延时） |
| 输出 | 可选：TIM4_CH1 输出比较，硬件控制 PA1；或 ISR 中软件翻转 |

> 若 PA1 未被 TIM4 通道复用，则在 TIM4 更新中断 ISR 中软件清除 PA1（切换为接收模式）。

### 6.4 中断优先级划分

STM32F103 使用 4 位抢占优先级（0-15），数字越小优先级越高。

| 中断源 | 抢占优先级 | 子优先级 | 说明 |
|---|---|---|---|
| 急停按钮 (EXTI) | 0 | 0 | **最高优先级**，立即安全停车 |
| TIM2 (控制周期) | 1 | 0 | 确保控制周期稳定，抖动 < 50μs |
| TIM4 (RS485 延时) | 2 | 0 | 精确控制收发切换 |
| USART2 RX (Modbus 响应) | 3 | 0 | 电机反馈数据及时接收 |
| USART3 DMA (JY61P 数据) | 3 | 1 | IMU 数据 DMA 完成 |
| USART1 RX (上位机) | 4 | 0 | 上位机指令接收 |
| I2C1 (激光) | 5 | 0 | 激光数据读取完成 |
| Systick (HAL 时钟) | 15 | 0 | 系统时基，最低优先 |

**优先级划分原则**：
- **安全优先**：急停信号最高优先，在任何情况下都能在 1 个指令周期内触发
- **实时性**：控制周期是运动系统的心脏，TIM2 优先级高于所有通信中断，保证 100Hz 稳定运行
- **通信不丢数**：Modbus 响应帧和 JY61P 数据帧在 115200bps 下字节间隔仅 87μs，USART2/3 中断优先于非实时通信
- **非抢占控制周期**：所有通信中断优先级低于 TIM2，避免通信处理打断控制计算

### 6.5 多电机同步启停机制

**启动流程**：

```
1. 向四台电机逐一发送速度指令 (0xFB)，各电机预存指令但不执行
2. 发送广播同步帧 (0x00 0xFF 0x66)
3. 四台电机严格同时开始运动
```

**停止流程**：

```
普通停止：
  广播同步帧带零速指令 = 四轮同时停止

紧急停止：
  GPIO PB12 外部中断 → ISR 中:
    1. PA1 = HIGH (RS485 发送模式)
    2. HAL_UART_Transmit(紧急停止广播帧)  // 死等发送完成
    3. PA1 = LOW
    4. g_emergency_stop_flag = 1
  → 主循环检测标志位 → 告知上位机 → 等待复位指令
```

> 急停 ISR 中使用 HAL_UART_Transmit 阻塞发送，因为急停场景下控制周期的正常执行已无意义（所有电机已刹车），不会影响系统安全。阻塞发送确保急停帧在所有情况下都能发出。

### 6.6 通讯超时安全停车

```c
// 在主控制循环中检查
if (HAL_GetTick() - last_cmd_tick > CMD_TIMEOUT_MS) {
    // 上位机通讯超时（如树莓派死机、串口线松脱）
    // 执行安全停车
    g_cmd_timeout_flag = 1;
    Emergency_Stop();  // 广播停止 → 所有电机刹车
}
```

建议超时阈值 `CMD_TIMEOUT_MS = 500ms`。

---

## 附录 A：关键寄存器速查

### ZDT_X42 Modbus 寄存器

| 寄存器地址 | 功能码(R/W) | 数据长度 | 说明 |
|---|---|---|---|
| `0x0007` | 0x06 (W) | 1 reg | 写 0x0001 保存参数到 EEPROM |
| `0x000A` | 0x06 (W) | 1 reg | 写 0x0001 位置清零 |
| `0x0010` | 0x03 (R) | 1 reg | 固件版本号 |
| `0x0020` | 0x06 (W) | 1 reg | 从机地址设置 (1-247) |
| `0x0022` | 0x03 (R) | 1 reg | 实时转速 (int16, RPM) |
| `0x0024` | 0x03 (R) | 2 regs | 当前位置 (int32, 需按细分换算) |
| `0x003B` | 0x03 (R) | 1 reg | 回零/编码器状态标志位 |
| `0x00F0` | 0xFB (W) | — | 直通限速位置控制命令 |

### JY61P 关键配置

| 寄存器 | 地址 | 说明 |
|---|---|---|
| KEY (解锁) | 0x69 | 写 0xB588 解锁 |
| CALSW | 0x01 | 写 0x0004 航向角置零 |
| SAVE | 0x00 | 写 0x0000 保存配置 |
| RSW (输出内容) | 0x02 | 设置输出数据内容 |
| RRATE (输出速率) | 0x03 | 设置数据输出速率 |

### JY61P 数据包帧头

| 数据包类型 | 帧头 | 数据长度 |
|---|---|---|
| 加速度 | 0x55 0x51 | 8 bytes |
| 角速度 | 0x55 0x52 | 8 bytes |
| 角度 | 0x55 0x53 | 8 bytes |

---

## 附录 B：电机额定参数假设

> **以下为设计假设值**，需根据 ZDT_X42 实际参数手册修正。

| 参数 | 假设值 | 说明 |
|---|---|---|
| 额定转速 | 300 RPM | 在负载下稳定运行的最高转速 |
| 空载最大转速 | 500 RPM | 空载 / 轻载可达转速 |
| 控制死区 | ±5 RPM | 低于此值电机可能不响应，速度指令需做死区处理 |

**速度指令死区处理**：

```c
if (fabsf(rpm_cmd) < RPM_DEADZONE) {
    rpm_cmd = 0.0f;  // 低于死区直接输出零速
}
```

---

## 附录 C：项目文件结构建议

```
ATK-YJ/
├── Core/
│   ├── Inc/
│   │   ├── main.h
│   │   ├── board_app.h          (已有)
│   │   ├── jy61p.h              (已有，需改为 UART 模式)
│   │   ├── imu_app.h            (已有)
│   │   ├── atk_ms53l1m.h        (已有)
│   │   ├── laser_app.h          (已有)
│   │   ├── modbus.h             (新增：Modbus CRC/帧封装)
│   │   ├── zdt_motor.h          (新增：ZDT_X42 电机驱动)
│   │   ├── mecanum.h            (新增：麦轮运动学)
│   │   ├── motion_control.h     (新增：运动控制融合)
│   │   └── pid.h                (新增：PID 控制器)
│   └── Src/
│       ├── main.c               (已有，需增加控制循环)
│       ├── board_app.c          (已有)
│       ├── jy61p.c              (已有，需改为 UART 模式)
│       ├── imu_app.c            (已有)
│       ├── atk_ms53l1m.c        (已有)
│       ├── laser_app.c          (已有)
│       ├── modbus.c             (新增)
│       ├── zdt_motor.c          (新增)
│       ├── mecanum.c            (新增)
│       ├── motion_control.c     (新增)
│       └── pid.c                (新增)
```

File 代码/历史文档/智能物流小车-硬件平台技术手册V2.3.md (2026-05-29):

# 智能物流小车硬件平台技术手册 V2

> 项目阶段：底盘控制、传感器数据读取、树莓派联动准备  
> 文档版本：V2.3  
> 最后更新：2026-05-21  
> 维护方式：后续修改请优先更新“待确认事项”和“变更记录
| V2.3 | 2026-05-21 | 修正第3.2节 JY61P 连接表 SCL/SDA 引脚（原PB7/PB6→PB6/PB7，与第2.1节引脚表一致） |
| V2.2 | 2026-05-20 | 修正第3.1节 PB8/PB9 为 PB6/PB7（与引脚表一致）；确认 I2C 传感器统—5V供电与5V上拉；新增硬件配置摘要文件 |
| V2.1 | 2026-05-17 | 修正 I2C1 引脚为 PB6/PB7，删除 remap；电机链路更新为 USART1(PA9/PA10)；I2C 上拉更新为 5V；补充 RS485 方向控制说明 |”，避免口头结论与文档不一致。  
> 主要依据：现有硬件平台手册、`stm32cubeide_atk_ms53l1m_i2c_framework` 代码与 README、控制板硬件审查报告、当前 STM32CubeIDE 引脚截图。

---

## 目录

1. [系统架构总览](#1-系统架构总览)
2. [STM32F103C8T6 引脚与外设分配](#2-stm32f103c8t6-引脚与外设分配)
3. [传感器连接与数据采集](#3-传感器连接与数据采集)
4. [电机与树莓派通信](#4-电机与树莓派通信)
5. [供电系统与功率预算](#5-供电系统与功率预算)
6. [数据接收与分发](#6-数据接收与分发)
7. [赛场运行状态与模块调用](#7-赛场运行状态与模块调用)
8. [FreeRTOS 必要性评估](#8-freertos-必要性评估)
9. [优化建议与后续待确认项](#9-优化建议与后续待确认项)
10. [变更记录
| V2.3 | 2026-05-21 | 修正第3.2节 JY61P 连接表 SCL/SDA 引脚（原PB7/PB6→PB6/PB7，与第2.1节引脚表一致） |
| V2.2 | 2026-05-20 | 修正第3.1节 PB8/PB9 为 PB6/PB7（与引脚表一致）；确认 I2C 传感器统—5V供电与5V上拉；新增硬件配置摘要文件 |
| V2.1 | 2026-05-17 | 修正 I2C1 引脚为 PB6/PB7，删除 remap；电机链路更新为 USART1(PA9/PA10)；I2C 上拉更新为 5V；补充 RS485 方向控制说明 |](#10-变更记录
| V2.3 | 2026-05-21 | 修正第3.2节 JY61P 连接表 SCL/SDA 引脚（原PB7/PB6→PB6/PB7，与第2.1节引脚表一致） |
| V2.2 | 2026-05-20 | 修正第3.1节 PB8/PB9 为 PB6/PB7（与引脚表一致）；确认 I2C 传感器统—5V供电与5V上拉；新增硬件配置摘要文件 |
| V2.1 | 2026-05-17 | 修正 I2C1 引脚为 PB6/PB7，删除 remap；电机链路更新为 USART1(PA9/PA10)；I2C 上拉更新为 5V；补充 RS485 方向控制说明 |)

---

## 1. 系统架构总览

### 1.1 分层职责

系统按“决策层、控制层、执行层”划分。树莓派负责高层任务，STM32 负责实时采集、通信转发和安全保护，电机驱动与传感器负责底层执行和反馈。

| 层级 | 硬件 | 主要职责 | 关键输出 |
|---|---|---|---|
| 决策层 | 树莓派 4B | 视觉识别、路径规划、任务调度、比赛策略 | 速度指令、目标点、任务状态 |
| 控制层 | STM32F103C8T6 底盘控制板 | 传感器采样、命令校验、限幅、安全停车、电机通信分发 | 电机命令、状态上报、安全状态 |
| 感知层 | JY61P、ATK-MS53L1M | 姿态、角速度、加速度、前向或指定方向距离 | IMU 数据、距离数据 |
| 执行层 | ZDT_X42 电机驱动与麦克纳姆轮 | 底盘移动、闭环速度/位置执行 | 编码器/驱动状态、实际运动 |

### 1.2 当前物理链路

```text
树莓派 4B
  USB
   |
   v
CH340N USB 转串口
   |
   | 3.3V/TTL 串口逻辑，板级电平需实测确认
   v
STM32F103C8T6 USART2
  PA2 = USART2_TX
  PA3 = USART2_RX

STM32F103C8T6 I2C1 
  PB6 = I2C1_SCL
  PB7 = I2C1_SDA
   |---------------- JY61P IMU
   |---------------- ATK-MS53L1M / VL53L1X 激光测距

STM32F103C8T6 USART1
  PA9 = USART1_TX
  PA10 = USART1_RX
   |
   v
RS485模块 → ZDT_X42 电机通信链路
```

### 1.3 数据流向

| 方向 | 路径 | 数据内容 | 处理要求 |
|---|---|---|---|
| 上行反馈 | JY61P -> I2C1 -> STM32 -> USART2/CH340N -> 树莓派 | Roll、Pitch、Yaw、三轴加速度、三轴角速度、温度 | 带时间戳，保留最近一次有效值 |
| 上行反馈 | ATK-MS53L1M -> I2C1 -> STM32 -> USART2/CH340N -> 树莓派 | 距离 mm、测量状态、样本计数 | 距离异常时标记无效，不直接覆盖安全状态 |
| 上行反馈 | 电机驱动 -> USART3 -> STM32 -> USART2/CH340N -> 树莓派 | 在线状态、速度/位置反馈、错误码 | 按实际电机协议补全 |
| 下行控制 | 树莓派 -> USART2/CH340N -> STM32 -> USART3 -> 电机驱动 | 速度向量、目标位置、停止、急停解除、校准命令 | CRC 校验、序号检查、限幅、安全状态优先 |

---

## 2. STM32F103C8T6 引脚与外设分配

### 2.1 已确定引脚表

| STM32 引脚 | 外设/功能 | 连接对象 | 方向 | 状态  | 备注 |
| --- | --- | --- | --- | --- | --- |
| **PB6**  | I2C1_SCL， | JY61P、ATK-MS53L1M | 双向 | 已确定 | 需在 CubeMX/HAL 中启用 I2C1 ，并确认生成 `__HAL_AFIO_REMAP_I2C1_ENABLE()` |
| **PB7**  | I2C1_SDA， | JY61P、ATK-MS53L1M | 双向 | 已确定 | |
| **PA9**  | USART1_TX | RS485模块 DI → ZDT_X42电机 | STM32 输出 | 已确定 | 需另配 GPIO控制 RS485收发方向 |
| **PA10** | USART1_RX | RS485模块 RO ← ZDT_X42电机 | STM32 输入 | 已确定 | 与电机通信模块共地 |
| PA2 | USART2_TX | CH340N RXD，树莓派通信  | STM32 输出 | 已确定 | 树莓派通过 USB 访问 CH340N 虚拟串口 |
| PA3 | USART2_RX | CH340N TXD，树莓派通信  | STM32 输入 | 已确定 | 需确认 CH340N TXD 电平不会超过 MCU 输入安全范围 |
| PA13 | SWDIO | ST-LINK / 调试器 | 双向 | 保留  | 不作为业务 IO 使用 |
| PA14 | SWCLK | ST-LINK / 调试器 | 输入 | 保留  | 不作为业务 IO 使用 |
| NRST | 复位 | 调试器/复位电路 | 输入 | 保留  | 建议在调试接口引出 |
| PC13 | 状态 LED，可选 | 板载 LED | 输出 | 可选  | 低电平点亮的核心板常见连接，需按实际板验证 |

### 2.2 CubeMX / CubeIDE 配置要点

| 项目 | 建议配置 | 原因 |
| --- | --- | --- |
| I2C1 | PB6(SCL)/PB7(SDA)，100 kHz 起步 | 默认引脚，不需remap；两个传感器共总线，先保证稳定，再视波形提高速率 |
| USART2 | 异步串口，建议 115200 bps 起步 | 树莓派和 STM32 主通信链路，先以可靠调试为主 |
| USART3 | 异步串口，建议按电机驱动协议设置 | 电机链路独立于树莓派链路 |
| SWD | 保持开启 | 便于 ST-LINK 在线调试、变量观察和固件下载 |
| GPIO 未用脚 | 统一配置为模拟输入或明确上下拉 | 降低悬空噪声和功耗 |

### 2.3 引脚占用原则

- `PB6/PB7` 归 I2C1 独占，由 JY61P 和 ATK-MS53L1M 共用。
- `PA2/PA3` 归树莓派通信链路独占。
- `PA9/PA10` 归电机 USART1 通信链路独占，经 RS485 模块连接 ZDT_X42。
- `PA13/PA14/NRST` 保留给调试和下载，不参与普通 IO 扩展。
- 后续新增急停、蜂鸣器、状态灯、电池 ADC 时，应优先选择未占用且方便布线的 GPIO，并同步更新本表。

---

## 3. 传感器连接与数据采集

### 3.1 I2C1 共总线设计

JY61P 和 ATK-MS53L1M 当前均接入 STM32 的 I2C1，总线引脚为 `PB6/PB7`。两个设备地址不同，不存在地址冲突。

| 设备 | 7-bit 地址 | HAL/8-bit 地址 | 主要数据 | 当前代码状态 |
|---|---:|---:|---|---|
| JY61P | `0x50` | `0xA0` | 加速度、角速度、Roll/Pitch/Yaw、温度 | `.c/.h` 已完成，使用 I2C 寄存器读取 |
| ATK-MS53L1M / VL53L1X | `0x29` | `0x52` | 距离 mm、测量状态 | `.c/.h` 已完成，使用 VL53L1X 官方 API 适配 |

I2C 电气要求：

- SCL/SDA 上拉必须接 5V（硬件板级确认）。传感器模块由 5V 供电，I2C 上拉已确认为 5V。
- 两个传感器和 STM32 必须共地。
- 调试阶段 I2C 速率先使用 100 kHz。线长较短、波形干净后可评估 400 kHz。
- 如果总线偶发卡死，固件需要支持 I2C bus recovery：将 SCL 临时配置为 GPIO 输出，产生 9 个时钟后重新初始化 I2C。

### 3.2 JY61P 陀螺仪/IMU

#### 连接方式

| JY61P 引脚 | STM32 连接 | 说明 |
| --- | --- | --- |
| VCC | 5V | 统—5V供电，与 I2C 上拉电平一致 |
| GND | GND | 与 STM32 和电机通信地共地 |
| SCL | PB6 / I2C1_SCL | I2C 时钟 |
| SDA | PB7 / I2C1_SDA | I2C 数据 |
| RX | 不连接 | 本版不使用 JY61P 串口模式 |
| TX | 不连接 | 本版不使用 JY61P 串口模式 |

#### 电气与功耗

| 参数 | 当前文档取值 | 备注 |
|---|---:|---|
| 工作电压 | 3.3V-5V | 以模块实物规格为准 |
| 工作电流 | 约 8.4 mA @ 5V | 约 0.042 W；若 3.3V 供电，功耗约 0.028 W 量级 |
| 数据读取方式 | I2C 寄存器读取 | 代码中连续读取 `0x34` 起始的数据寄存器 |

#### 代码接口

当前代码中 `JY61P_ReadSensor()` 从寄存器 `0x34` 起读取 26 字节，并转换为以下物理量：

| 数据 | 寄存器 | 转换关系 |
|---|---|---|
| 加速度 | `AX=0x34` 起 | `raw / 32768 * 16g` |
| 角速度 | `GX=0x37` 起 | `raw / 32768 * 2000 dps` |
| 欧拉角 | `ROLL=0x3D` 起 | `raw / 32768 * 180 deg` |
| 温度 | `TEMP=0x40` | `raw / 100` |

建议应用层保留以下数据：

- `imu.roll_deg`
- `imu.pitch_deg`
- `imu.yaw_deg`
- `imu.ax_g / imu.ay_g / imu.az_g`
- `imu.gx_dps / imu.gy_dps / imu.gz_dps`
- `imu.last_update_ms`
- `imu.valid`
- `imu.error_count`

### 3.3 ATK-MS53L1M 激光测距模块

#### 连接方式

| ATK-MS53L1M 引脚 | STM32 连接 | 说明 |
| --- | --- | --- |
| VCC | 5V | 统—5V供电，与 I2C 上拉电平一致 |
| GND | GND | 与 STM32 共地 |
| SCL | PB6 / I2C1_SCL | 与 JY61P 共用 |
| SDA | PB7 / I2C1_SDA | 与 JY61P 共用 |
| TXD | 不连接 | I2C 模式不使用 |
| RXD | 不连接 | I2C 模式不使用 |

#### 电气与功耗

| 参数 | 当前文档取值 | 备注 |
|---|---:|---|
| 工作电压 | 3.3V-5V | 模块供电可宽压，但 I2C 电平仍按 3.3V 管理 |
| 工作电流 | 小于 30 mA | 5V 下小于 0.15 W，3.3V 下小于 0.10 W |
| 测量距离 | 40 mm-4000 mm | 长距离模式取决于环境反射率 |
| 激光安全 | 940 nm，Class 1 | 正常使用下人眼安全 |

#### 代码接口

当前 `ATK_MS53L1M_Init()` 使用 HAL I2C 句柄初始化 VL53L1X，并设置：

| 项目 | 当前代码值 | 说明 |
|---|---:|---|
| 模块 ID 寄存器 | `0x010F` | 读取后应为 `0xEACC` |
| 测距模式 | Long | 适合较长距离检测 |
| Timing budget | 140000 us | 单次测量预算 |
| Inter-measurement | 150 ms | 当前有效采样率约 6-7 Hz |
| 应用层轮询周期 | 20 ms | 轮询是否有新数据，不代表每 20 ms 都有新距离 |

建议应用层保留以下数据：

- `laser.distance_mm`
- `laser.valid`
- `laser.last_update_ms`
- `laser.sample_count`
- `laser.status`
- `laser.too_close`

### 3.4 传感器使用建议

- IMU 适合用于航向角辅助、姿态异常检测和短时间运动稳定判断，不应单独承担长距离定位。
- 激光测距适合用于前向障碍、靠近货架/目标点时的距离判断。单点激光存在视场限制，比赛中应结合视觉或多角度传感器判断。
- 两个传感器都在 I2C1 上，任何阻塞式 I2C 操作都会影响另一个传感器。固件中应避免长时间等待，错误后快速返回并上报状态。

---

## 4. 电机与树莓派通信

### 4.1 树莓派与 STM32 链路

树莓派通过 USB 连接控制板上的 CH340N，CH340N 再连接 STM32 的 USART2。

| 项目 | 配置 |
|---|---|
| STM32 外设 | USART2 |
| STM32 引脚 | PA2 = TX，PA3 = RX |
| 物理桥接 | CH340N USB 转串口 |
| 树莓派侧设备名 | 通常为 `/dev/ttyUSB0`，具体以 `dmesg` 或 `ls /dev/ttyUSB*` 为准 |
| 起步波特率 | 115200 bps |
| 推荐协议 | 自定义二进制帧，带长度、序号、类型、CRC16 |

建议下行命令帧至少包含：

| 字段 | 说明 |
|---|---|
| frame_head | 固定帧头，用于同步 |
| seq | 序号，用于丢包和乱序检测 |
| msg_type | 速度控制、位置控制、停止、校准、心跳等 |
| payload_len | 负载长度 |
| payload | 速度向量、目标点、参数 |
| crc16 | 完整性校验 |

建议上行状态帧至少包含：

| 字段 | 说明 |
|---|---|
| system_state | 当前运行状态 |
| fault_flags | 故障位图 |
| imu | 姿态、角速度、加速度摘要 |
| laser | 距离和有效标志 |
| motor | 电机在线状态、速度/位置摘要 |
| heartbeat | STM32 心跳计数 |

### 4.2 CH340N 注意事项

硬件审查中识别到板载 USB 串口为 CH340N。CH340N 属于内置时钟版本，不需要外部 12 MHz 晶振。后续硬件文档不要再按需要外部晶振的 CH340 型号描述。

需要继续验证的风险：

- 如果 CH340N 由 5V 供电，需确认其 TXD 到 STM32 RX 的电平是否安全。
- 若 USB VBUS 未参与检测，而 CH340N 由板上 5V 自供电，可能存在 USB 自供电设备规范风险。比赛功能上可能可用，但正式板应评估 VBUS 检测或供电隔离。
- 树莓派和 STM32 之间的串口协议必须有心跳和超时停车，不能依赖 USB 连接一直可靠。

### 4.3 STM32 与电机驱动链路

| 项目 | 配置 |
|---|---|
| STM32 外设 | USART1 |
| STM32 引脚 | PA9 = TX，PA10 = RX |
| 连接对象 | ZDT_X42 电机通信链路 |
| 起步波特率 | 按电机驱动设置，建议先统一 115200 bps |
| 协议 | 以 ZDT_X42 当前配置为准，若使用 Modbus-RTU 则需 CRC16 和从机地址 |

本版文档按“USART1 是 MCU 侧电机串口”记录。电机链路使用 RS485 转换模块，USART1 负责 TTL 串口收发，外部还需要：

- RS485 收发器或 ZDT_RS485 模块。
- A/B 差分线正确连接。
- 终端电阻按总线长度决定。
- 收发方向控制引脚，如果收发器不是自动方向控制，需要在 STM32 上另分配 GPIO。

建议电机地址约定：

| 地址 | 位置 | 备注 |
|---:|---|---|
| `0x01` | 左前轮 | 待实机确认 |
| `0x02` | 右前轮 | 待实机确认 |
| `0x03` | 左后轮 | 待实机确认 |
| `0x04` | 右后轮 | 待实机确认 |

### 4.4 安全通信策略

| 风险 | STM32 处理策略 |
|---|---|
| 树莓派心跳超时 | 500 ms-1000 ms 内进入安全停车状态 |
| 下行帧 CRC 错误 | 丢弃该帧，错误计数加 1，不改变运动目标 |
| 下行速度过大 | 限幅后执行，并上报限幅标志 |
| 电机链路无响应 | 停止对应电机或全部停车，按故障等级处理 |
| 传感器异常 | 标记数据无效，禁止使用异常值触发运动增益 |

---

## 5. 供电系统与功率预算

### 5.1 当前供电树

硬件审查报告显示，当前控制板是 12V 输入母线加两路降压输出，不是由降压模块生成稳压 12V。

```text
12V 电池/适配器输入
  |
  +-- 12V 母线 -> 电机驱动、大功率负载
  |
  +-- TPS5450 -> +5V
  |      +-- 树莓派 4B
  |      +-- CH340N
  |      +-- STM32 核心板 5V 输入或其它 5V 外设
  |
  +-- TPS5450 -> +7.5V
         +-- 后续外设/机械臂相关接口，按实际连接确认
```

I2C 传感器可以使用 3.3V 或 5V 供电，但 SCL/SDA 必须维持 3.3V 逻辑。实际接线建议优先让传感器跟 STM32 使用同一 3.3V 逻辑域，降低总线电平风险。

### 5.2 功率预算

| 负载 | 电压 | 电流估算 | 功率估算 | 备注 |
|---|---:|---:|---:|---|
| 树莓派 4B | 5V | 峰值按 3A 预留 | 15W | 摄像头、USB 外设和算法负载会抬高峰值 |
| CH340N | 5V | 约 10-30 mA，待实测 | 小于 0.15W | 以实际芯片和 USB 状态为准 |
| STM32F103 核心板 | 5V 输入或 3.3V | 数十 mA 量级 | 小于 0.5W | 包含核心板 LDO 损耗 |
| JY61P | 3.3V 或 5V | 约 8.4 mA @ 5V | 约 0.042W @ 5V | 建议确认 I2C 上拉电压 |
| ATK-MS53L1M | 3.3V 或 5V | 小于 30 mA | 小于 0.15W @ 5V | VL53L1X 测距模块 |
| ZDT_X42 电机驱动 x4 | 12V | 按驱动电流设置确认 | 待测 | 启停瞬态可能远高于静态估算 |
| 摄像头 | 5V/USB | 按型号确认 | 待测 | 由树莓派 USB 口或独立电源供电 |

### 5.3 电源完整性要求

- 12V 输入端应有保险丝、开关、反接保护和足够的输入储能电容。
- 电机急启急停会导致 12V 母线跌落和噪声，需用示波器观察 5V、3.3V 轨。
- STM32、传感器、CH340N、电机通信模块必须共地，但大电流电机回流不要穿过传感器地线。
- 5V 给树莓派供电时需保证线径和接插件压降，避免树莓派低压降频或重启。
- I2C 传感器附近建议放置 `100nF + 10uF` 去耦。

### 5.4 硬件审查中建议保留的风险项

| 风险项 | 影响 | 建议 |
|---|---|---|
| +5V 实测/计算约 5.08V | 通常可用，但命名和目标值需统一 | BOM 和原理图统一标注目标输出 |
| TPS5450 BOOT 电容取值需核对 | 可能影响高边驱动稳定性 | 按数据手册复核 |
| 输入保险丝规格描述不一致 | 保护策略不清晰 | 明确保持电流、熔断电流、额定电压 |
| USB 自供电/VBUS 检测 | USB 合规和反灌风险 | 正式板增加检测或隔离 |
| CH340N 与 STM32 电平 | MCU 输入安全风险 | 优先确认 CH340N TXD 电平是否安全 |

---

## 6. 数据接收与分发

### 6.1 STM32 内部数据模型

建议 STM32 内部维护以下缓存结构。具体 C 结构体可后续在固件文档中定义。

| 数据块 | 来源 | 更新周期建议 | 关键字段 |
|---|---|---:|---|
| `imu_state` | JY61P/I2C1 | 10-20 ms | 姿态、角速度、加速度、时间戳、有效标志 |
| `laser_state` | ATK-MS53L1M/I2C1 | 100-200 ms | 距离、状态、时间戳、过近标志 |
| `motor_state` | ZDT_X42/USART3 | 20-100 ms | 在线状态、速度、位置、错误码 |
| `cmd_state` | 树莓派/USART2 | 每帧更新 | 速度目标、位置目标、模式、序号 |
| `safety_state` | STM32 本地状态机 | 1-5 ms | 急停、超时、限速、故障位 |
| `link_state` | USART2/USART3 | 每次收发更新 | 心跳时间、错误计数、丢包计数 |

### 6.2 下行命令处理

```text
USART2 RX 中断或 DMA
  -> ring buffer
  -> 帧同步
  -> 长度检查
  -> CRC 检查
  -> 序号/时间戳检查
  -> 命令解析
  -> 安全限幅
  -> 更新 cmd_state
  -> 电机命令生成
  -> USART3 发送
```

处理原则：

- 任何 CRC 错误帧都不允许改变当前运动目标。
- 停止、急停类命令优先级高于普通速度命令。
- 树莓派超时后，STM32 应覆盖运动目标为零速，并进入安全停车状态。
- 校准类命令需要在小车静止状态下执行，执行期间拒绝运动命令。

### 6.3 上行数据分发

```text
I2C1 传感器采样
USART3 电机状态采样
本地安全状态机
  -> 统一打包 telemetry
  -> USART2/CH340N
  -> 树莓派任务调度/日志/可视化
```

上行包建议分两类：

| 类型 | 周期 | 内容 |
|---|---:|---|
| 快速状态包 | 20-50 ms | 系统状态、故障位、IMU 摘要、电机在线摘要 |
| 慢速诊断包 | 200-1000 ms | 传感器计数、错误计数、电源状态、调试变量 |

### 6.4 推荐裸机调度节拍

在不使用 FreeRTOS 的阶段，建议采用“超级循环 + 中断/DMA + 非阻塞状态机”：

| 模块 | 触发方式 | 建议周期 | 说明 |
|---|---|---:|---|
| USART2 接收 | 中断或 DMA | 实时 | 只入队，不在中断中解析复杂协议 |
| USART3 接收 | 中断或 DMA | 实时 | 电机响应帧入队 |
| 协议解析 | 主循环 | 1-5 ms | 每次处理有限字节，避免长时间占用 |
| 安全状态机 | 主循环或定时器 | 1-5 ms | 检查心跳、急停、传感器异常 |
| IMU 读取 | 主循环 | 10-20 ms | I2C 读取失败时快速返回 |
| 激光读取 | 主循环 | 100-200 ms | 当前代码 150 ms 测量周期 |
| 电机命令刷新 | 主循环 | 10-20 ms | 只在目标变化或周期到达时发送 |
| 状态上报 | 主循环 | 20-100 ms | 快慢包分开 |

---

## 7. 赛场运行状态与模块调用

### 7.1 状态机总览

```text
POWER_ON
  -> SELF_TEST
  -> IDLE
  -> READY
  -> RUNNING
       |-> CRUISE
       |-> APPROACH_TARGET
       |-> AVOID_OBSTACLE
       |-> LOAD_OR_UNLOAD
  -> FAULT
       |-> LINK_LOST
       |-> POSE_ABNORMAL
       |-> MOTOR_FAULT
       |-> E_STOP
  -> RECOVERY
```

### 7.2 各场景模块调用

| 场景 | 触发条件 | 树莓派模块 | STM32 模块 | 电机状态 | 传感器状态 |
|---|---|---|---|---|---|
| 上电自检 | 电源打开或复位 | 等待串口枚举，启动底盘节点 | 初始化 GPIO、I2C1、USART2、USART3、传感器、电机链路 | 禁止运动 | 读取 ID 和首帧数据 |
| 待命 | 自检通过，无任务 | 保持心跳，等待任务 | 周期上报状态，电机目标为零 | 停止保持 | 持续采样 |
| 巡航 | 收到路径速度命令 | 视觉/路径规划输出速度 | 校验命令、限幅、生成电机命令 | 按目标运动 | IMU 和距离持续上报 |
| 靠近目标 | 视觉识别到货架/目标点 | 降低速度，输出精细调整命令 | 增加距离判断，限制最大速度 | 低速运行 | 激光距离参与判断 |
| 搬运/装卸 | 到达任务点 | 控制机械臂或等待外部动作 | 底盘锁定或低速微调 | 停止或微动 | IMU 检查姿态稳定 |
| 避障 | 距离小于阈值或视觉报警 | 重新规划或下发停止 | 立即减速/停车，上报障碍标志 | 减速或停止 | 激光过近标志置位 |
| 姿态异常 | Roll/Pitch/角速度超过阈值 | 降级策略或报警 | 限速、停车、上报故障 | 停止或低速 | IMU 异常标志置位 |
| 通信丢失 | USART2 心跳超时 | 串口重连 | 自主停车，保持故障状态 | 停止 | 继续本地采样 |
| 急停/严重故障 | 急停输入、电机严重错误 | 显示故障并等待人工处理 | 立即停车，锁定故障态 | 禁止输出运动 | 状态继续上报 |

### 7.3 建议阈值管理

以下阈值先作为调试默认值，正式比赛前必须通过实测调整：

| 阈值 | 默认建议 | 说明 |
|---|---:|---|
| 树莓派心跳超时 | 500 ms | 超过则 STM32 自主停车 |
| 普通状态上报周期 | 50 ms | 兼顾实时性和串口带宽 |
| 激光避障预警距离 | 300-500 mm | 按车速和制动距离调整 |
| 激光硬停车距离 | 100-200 mm | 按传感器安装位置调整 |
| 姿态异常 Roll/Pitch | 8-12 deg | 防止倾倒或严重碰撞后继续运行 |
| 电机命令刷新 | 20 ms | 50 Hz 控制频率起步 |

---

## 8. FreeRTOS 必要性评估

### 8.1 当前结论

当前阶段不强制必须使用 FreeRTOS。以 STM32F103C8T6 的资源和当前功能量看，裸机超级循环配合串口中断/DMA、I2C 非阻塞式轮询、定时状态机，已经可以完成：

- JY61P 和 ATK-MS53L1M 数据轮询。
- USART2 树莓派通信。
- USART3 电机通信。
- 心跳超时与安全停车。
- 基础状态上报。

需要注意：低延迟响应主要依赖中断、DMA、合理的状态机和短临界区，不是简单引入 RTOS 就能自动获得。若任务优先级、栈、锁和阻塞等待设计不当，FreeRTOS 反而会增加调试复杂度。

### 8.2 建议采用的阶段策略

| 阶段 | 建议 | 原因 |
|---|---|---|
| P0 联调 | 裸机超级循环 + 中断/DMA | 最少变量，便于确认硬件、引脚和协议 |
| P1 稳定化 | 继续裸机，补齐状态机和错误恢复 | 当前任务量仍可控 |
| P2 多模块并发 | 评估轻量 FreeRTOS | 当通信、传感器、日志、安全逻辑互相阻塞时再引入 |
| P3 比赛优化 | 视调试结果决定 | 如果裸机延迟稳定，不必为了形式使用 RTOS |

### 8.3 需要引入 FreeRTOS 的条件

满足以下任意两项时，建议迁移到轻量 FreeRTOS：

- 树莓派下发高频速度命令，且串口解析影响传感器采样。
- 需要持续读取四个电机的实时状态，USART3 收发占用明显增加。
- 激光、IMU、电机、树莓派、日志同时运行时，主循环最长执行时间不可控。
- 急停、通信超时、电机故障要求独立高优先级处理。
- 后续新增机械臂、更多传感器或显示屏，模块之间开始争用 CPU。

### 8.4 如果使用 FreeRTOS 的任务草案

STM32F103C8T6 RAM 只有 20 KB，任务数量和栈必须严格控制。建议只使用静态创建，禁用不必要的动态分配和大缓冲。

| 任务 | 优先级 | 周期 | 职责 | 栈建议 |
|---|---:|---:|---|---:|
| SafetyTask | 最高 | 1-5 ms | 急停、心跳超时、故障锁定 | 128-192 words |
| CommsTask | 高 | 5-10 ms | USART2 协议解析、状态上报触发 | 192-256 words |
| MotorTask | 中高 | 10-20 ms | 电机命令刷新、状态读取 | 192-256 words |
| SensorTask | 中 | 10-20 ms | IMU 读取、激光状态轮询 | 256 words |
| TelemetryTask | 低 | 50-200 ms | 慢速诊断、日志、调试输出 | 192-256 words |

FreeRTOS 资源约束：

- `heap` 建议从 4 KB 起步，实测后再调整。
- 每个任务必须用 `uxTaskGetStackHighWaterMark()` 验证栈余量。
- 禁止在多个任务中直接调用阻塞式 printf。
- I2C 和串口发送必须有互斥或单一所有者任务，避免并发访问外设句柄。
- 安全停车逻辑不能依赖低优先级任务。

### 8.5 低延迟实现重点

无论是否使用 FreeRTOS，都应做到：

- USART2、USART3 接收使用中断或 DMA 环形缓冲。
- 急停输入使用外部中断或高频安全状态机。
- I2C 读写设置短超时，失败后记录错误并返回。
- 主循环或任务中不做长时间 `HAL_Delay()`。
- 所有运动命令都有时间戳，旧命令自动失效。
- 看门狗在系统卡死时强制复位，复位后默认电机停止。

---

## 9. 优化建议与后续待确认项

### 9.1 近期优先优化

| 优先级 | 项目 | 建议动作 |
|---|---|---|
| P0 | 确认电机物理层 | 确认 USART1 后面 RS485 模块的接线和方向控制 GPIO；若为 RS485，补充方向控制引脚 |
| P0 | 树莓派通信协议 | 定义二进制帧格式、CRC16、心跳、超时停车逻辑 |
| P0 | I2C 电平 | 实测 PB6/PB7 上拉电压，确保不是 5V |
| P0 | 电机地址和参数 | 记录四个 ZDT_X42 地址、细分、工作模式、限速、加速度 |
| P1 | 电源纹波 | 示波器测 12V、5V、3.3V 在电机急启急停时的波形 |
| P1 | CH340N 电平 | 实测 CH340N TXD 高电平，确认 STM32 输入安全 |
| P1 | 急停输入 | 确认是否已有急停按钮、接法和对应 GPIO |
| P1 | 传感器安装 | 记录 IMU 坐标系、激光安装方向和离地高度 |
| P2 | 电池监测 | 增加 12V 母线 ADC 分压或外置电量模块 |
| P2 | FreeRTOS 迁移 | 当裸机主循环延迟不可控时再启动 |

### 9.2 固件优化建议

- 为 USART2 和 USART3 分别实现 ring buffer，解析逻辑放在主循环或任务中。
- 所有上行数据带 `last_update_ms`，树莓派端不要使用过期传感器值。
- 运动命令统一经过限幅层，限制最大速度、最大角速度、最大加速度。
- 电机停止命令要有“普通减速停止”和“立即停止”两类接口。
- 使用 IWDG 独立看门狗，喂狗点放在主循环完整运行之后。
- 保留 ST-LINK Live Expressions 调试变量，便于无串口输出时验证传感器。

### 9.3 硬件优化建议

- I2C 线较长时可串联 22-100 ohm 小电阻抑制边沿振铃，并用示波器确认上升沿。
- 传感器线束与电机电源线分开走线，避免大电流噪声串入 I2C。
- 电机电源端增加足够储能电容，并确认保险丝和线束电流余量。
- Type-C/USB 口建议增加低电容 ESD 保护。
- 正式 PCB 上将 SWDIO、SWCLK、NRST、3.3V、GND 引出为稳定调试接口。

### 9.4 待确认事项

| 编号  | 问题 | 优先级 | 当前处理 |
| --- | --- | --- | --- |
| A1  | USART3 到 ZDT_X42 的实际物理层是什么 | P0  | 文档暂按“USART3 为 MCU 侧电机串口”记录 |
| A2  | 若电机链路使用 RS485，方向控制引脚是哪一个 | P0  | 待硬件原理图或实机测试确认 |
| A3  | 四个电机驱动地址、细分、限流参数 | P0  | 首次联调前读取并记录 |
| A4  | 树莓派和 STM32 的最终串口波特率 | P0  | 先用 115200 bps，稳定后再提高 |
| A5  | 急停按钮是否已安装及接线方式 | P1  | 未确认 |
| A6  | 电池容量、放电倍率、预期续航 | P1  | 未确认 |
| A7  | 机械臂是否进入本阶段联调 | P2  | 暂不纳入底盘 P0 |
| A8  | 激光避障阈值和安装方向 | P1  | 需实车测距标定 |
| A9  | IMU 坐标系与车体坐标系关系 | P1  | 需安装后标定 |
| A10 | 是否需要兼容 ROS 消息 | P2  | 协议预留扩展字段 |

---

## 10. 变更记录

| 版本 | 日期 | 变更 |
| ---- | --- | --- |
| V2 | 2026-05-15 | 重写硬件平台手册；更新 I2C1、USART2、USART3 引脚分配；补充数据分发、赛场状态、供电预算和 FreeRTOS 评估 |
| V2.1 | 2026-05-17 | 修正 I2C1 引脚为 PB6/PB7，删除 remap；电机链路更新为 USART1(PA9/PA10)；I2C 上拉更新为 5V；补充 RS485 方向控制说明 |
| V2.2 | 2026-05-20 | 修正第3.1节 PB8/PB9 为 PB6/PB7（与引脚表一致）；确认 I2C 传感器统—5V供电与5V上拉；新增硬件配置摘要文件 |
| V2.3 | 2026-05-21 | 修正第3.2节 JY61P 连接表 SCL/SDA 引脚（原PB7/PB6→PB6/PB7，与第2.1节引脚表一致） |

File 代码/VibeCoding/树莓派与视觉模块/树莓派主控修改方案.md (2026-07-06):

下面是针对 [usb_debug(4).py](D:/微信 聊天/xwechat_files/wxid_1ozyjlud9n0j22_1d1d/msg/file/2026-06/usb_debug(4\).py) 的修改计划，先不直接改代码。

| 修改点 | 当前情况 | 建议改法 |
| --- | --- | --- |
| 串口波特率 | 当前 `BAUD = 9600`，用于机械臂动作组协议。 | 和小车 STM32 UART2 通信应新增 `115200`波特率通信，同时保留 `9600` 的串口输出，分别为两个不同串口，输出不同信号 |
| 串口端口查找  | `find_usb_port()` 从 `/dev/ttyACM*`、`/dev/ttyUSB*` 找第一个 | 可保留，但建议优先 `/dev/serial/by-id/*CH340*`，更适合 CH340N |
| 当前输入方式  | `sys.stdin.readline().strip().lower()`，需要回车确认 | 要按下 W 立即响应，需要改成 raw keyboard 模式 |
| 当前按键功能  | `0-200` 发动作组，`s` 发机械臂停止帧，`q` 退出 | 增加 `o`（或大写） 进入小车手操模式 |
| 手操模式状态  | 当前没有模式变量 | 新增 `manual_mode = False` |
| 小车协议发送  | 当前只发送二进制动作组帧 `55 55 ...` | 增加发送 ASCII 协议帧，例如 `$FWD\r\n` |
| 键盘映射 | 当前无 WASD 控制 | 在 `manual_mode == True` 时，将 `w/a/s/d/x/e/r` 等映射到底盘指令 |
| STOP 冲突 | 当前 `s` 是机械臂停止 | 进入手操模式后，`s` 表示后退，退出手操模式后才可操作机械臂 |
| 退出手操模式  | 当前没有 | `p`  退出手操模式，`q` 仍然退出整个程序 |
| 串口读取回复  | 当前读取并 ASCII 打印 | 可保留，STM32 回复 $OK、`$LASER,...`、`$YAW,...` 时能直接显示 |

推荐插入位置如下：

|位置|要加的内容|
|---|---|
|`BAUD = 9600` 附近|改为 `BAUD = 115200`，或新增 `CAR_BAUD = 115200`|
|`make_stop_frame()` 后面|新增 `make_car_frame(cmd)`，用于生成 `$FWD\r\n` 这类 ASCII 帧|
|`main()` 开头打印区|增加说明：`o=进入手操模式`、`WASD=移动`、`x=停止`|
|`ser.reset_input_buffer()` 后|新增 `manual_mode = False`|
|`while True` 的键盘输入分支内|增加 `if manual_mode:` 优先处理小车手操键盘映射|
|原来的 `elif key == 's'` 前|增加 `elif key == 'o': manual_mode = True`|
|`finally` 中关闭串口前|可选：先发送 `$STOP\r\n`，避免退出后小车继续运动|

建议的手操模式键盘映射：

| 输入  | 发送给 STM32 | 小车动作 |
| --- | --- | --- |
| `o` | 不发送或发送 `$STOP\r\n` | 进入手操模式 |
| `w` | `$FWD\r\n` | 前进 |
| `s` | `$BACK\r\n` | 后退 |
| `a` | `$LEFT\r\n` | 左平移30mm |
| `d` | `$RIGHT\r\n` | 右平移30mm |
| `x` | `$STOP\r\n` | 停止 |
| `e` | `$CW,5\r\n` | 顺时针转 5 度  |
| `r` | `$CCW,5\r\n` | 逆时针转 5 度  |
| `l` | `$LASER\r\n` | 查询激光距离 |
| `y` | `$YAW\r\n` | 查询偏航角 |
| `p` | `$STOP\r\n` | 退出手操模式并停止 |
| `q` | `$STOP\r\n` 后退出 | 退出程序 |

核心修改逻辑可以这样设计：
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

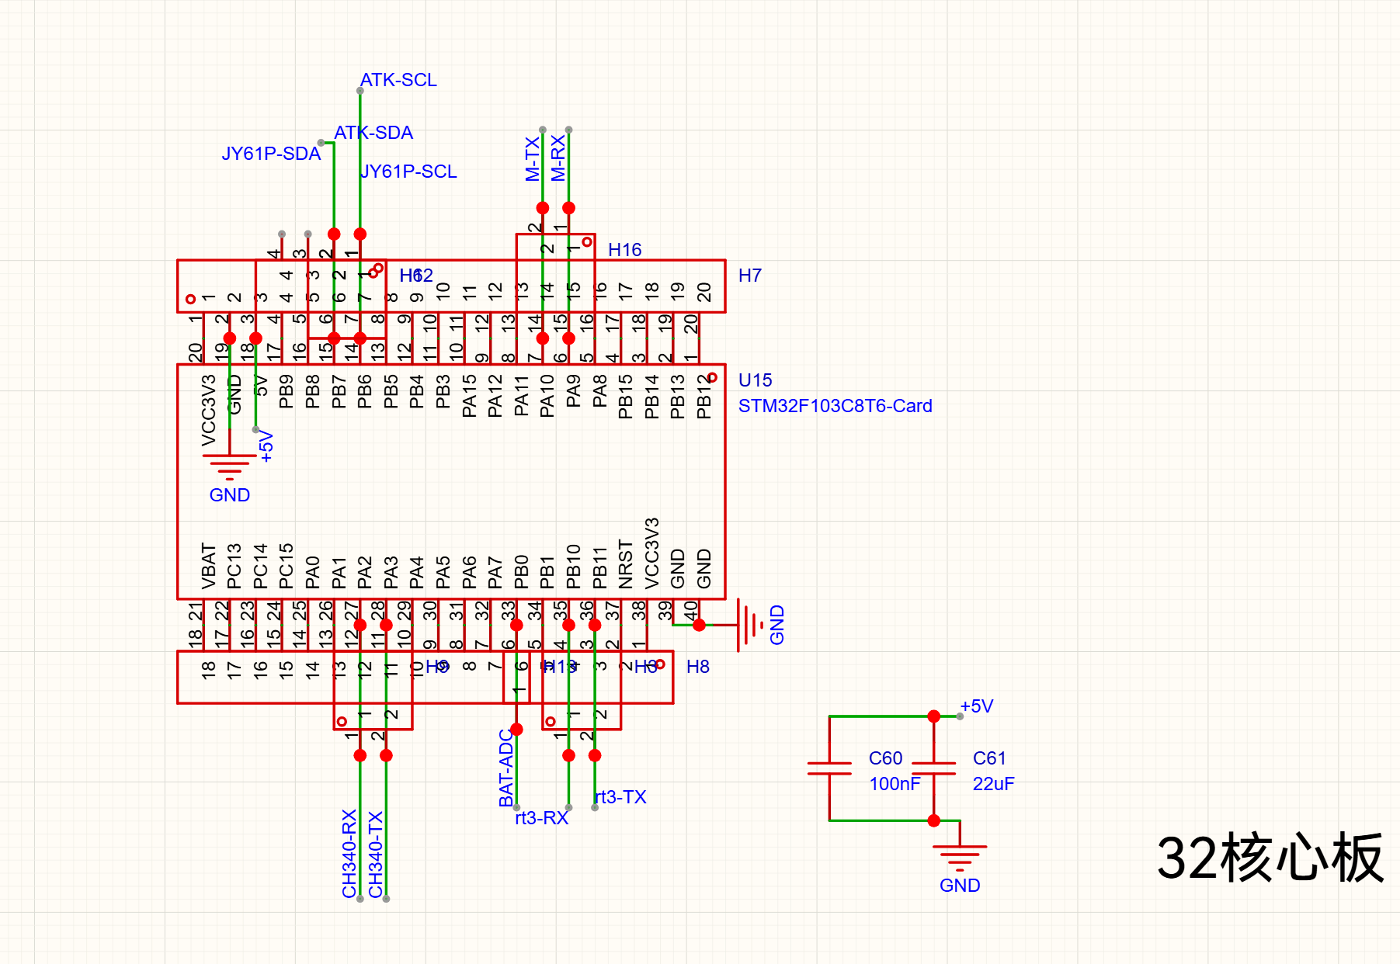
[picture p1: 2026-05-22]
代码/VibeCoding/姿态模块资料包/引脚原理图.png

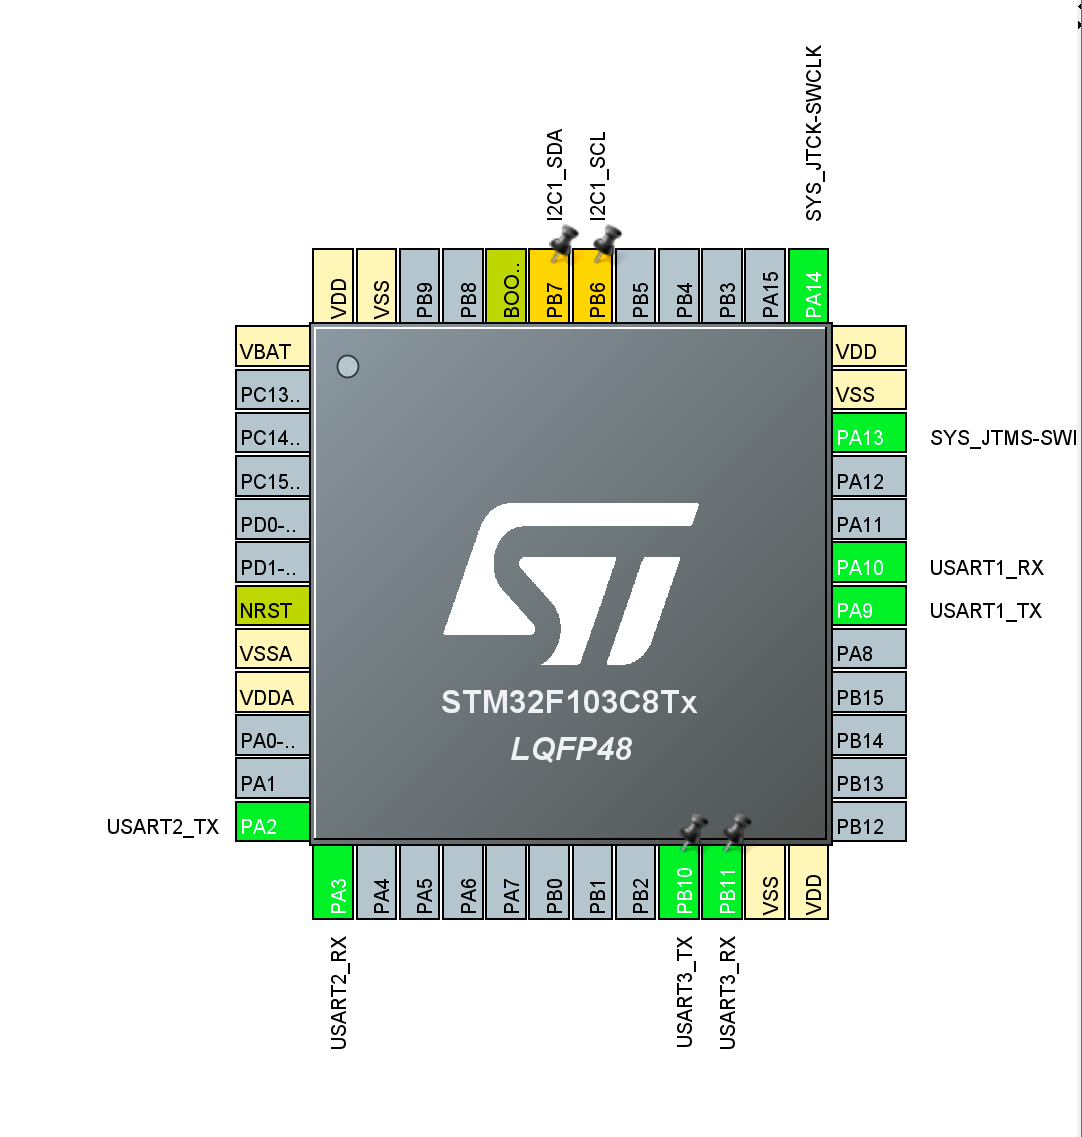
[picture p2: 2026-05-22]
代码/VibeCoding/姿态模块资料包/ioc配置.png

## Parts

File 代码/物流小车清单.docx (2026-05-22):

物流小车清单

主控：树莓派4B 烧录定制Linux系统，作为轮系驱动stm32芯片的上位机，并且用于视觉识别的处理中心

轮系控制：stm32f103c8t6核心板，通过串口通信控制ZDT_X42_V1.2闭环步进电机驱动板，从而控制移动。轮子用的是麦克纳姆轮组

机械臂控制：stm32开发板，程序已烧录，只需要通过从锂电池通过dcdc降压接电即可使用。但是需要视觉模块和陀螺仪的配合进行物体拿取

Dcdc模块：降低12V航模用锂电池的供电，引出低压用于开发板供电

32核心板：控制步进电机驱动，需要自己写代码控制轮系

陀螺仪：维特智能的JY61P，用于小车前进路线的惯导系统，在没有视觉识别路线的情况下（视觉仅用于物体夹取的识别）控制小车的运行方向，简单校准

激光测距模块：正点原子的atk-ms53l1m，用于判断障碍物位置

摄像头：杰瑞维通的DF100，用于视觉识别

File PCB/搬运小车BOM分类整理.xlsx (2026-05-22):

No. | Quantity | Comment | Designator | Footprint | Value | Supplier
▼ 电容 (22 pcs)
5 | 1 | 1000uF | C48 | CAP-TH_BD10.0-P5.00-D1.0-FD | 1000uF | LCSC
2 | 11 | 100nF | C21,C25,C26,C28,C34,C42,C45,C46,C52,C56,C60 | C0603 | 100nF
4 | 2 | 10uF | C35,C57 | C0603 | 10uF
3 | 4 | 22uF | C23,C24,C43,C44 | C0805 | 22uF
6 | 2 | 22uF | C51,C61 | C0603 | 22uF
1 | 2 | 470uF | C20,C50 | CAP-TH_BD8.0-P3.50-D0.6-FD | 470uF | LCSC
▼ 电阻 (10 pcs)
22 | 2 | 10K | R13,R18 | R0603 | 10K
20 | 2 | 2.2K | R11,R16 | R0603 | 2.2K
21 | 1 | 31.6K | R12 | R0603 | 31.6K
24 | 2 | 4.7K | R21,R22 | R0603 | 4.7K
19 | 2 | 5.1K | R4,R9 | R0603 | 5.1K
23 | 1 | 51.5K | R17 | R0603 | 51.5K
▼ 电感 (2 pcs)
18 | 2 | 15uH | L3,L4 | IND-SMD_L7.5-W6.6 | 15uH | LCSC
▼ 二极管 (5 pcs)
10 | 1 | DC050-T | DC1 | DC-IN_DC050-T |  | LCSC
9 | 4 | SS34 | D3,D4,D5,D6 | SMA_L4.3-W2.6-LS5.0-FD |  | LCSC
▼ 连接器 (2 pcs)
8 | 1 | KF2EDGR-3.81-2P | CN4 | CONN-TH_2P-P3.81_KF2EDGR-3.81-2P |  | LCSC
7 | 1 | XT60PT-M | CN3 | CONN-TH_XT60PT-M |  | LCSC
▼ 排针排母 (13 pcs)
17 | 1 | 5V | H11 | HDR-TH_3P-P2.54-V-M
16 | 1 | GND | H10 | HDR-TH_3P-P2.54-V-M
14 | 1 | HDR-M_2.54_1x18P | H8 | HDR-TH_18P-P2.54-V-M
11 | 5 | HDR-M_2.54_1x1P | H1,H2,H4,H5,H13 | HDR-TH_1P-V-M_XKB_X4611WV-01I-C28D40
13 | 1 | HDR-M_2.54_1x20P | H7 | HDR-TH_20P-P2.54-V-M-1
15 | 3 | HDR-M_2.54_1x2P | H9,H12,H16 | HDR-TH_2P-P2.54-V-M-1
12 | 1 | HDR-M_2.54_1x4P | H6 | HDR-TH_4P-P2.54-V-M
▼ 集成电路 (8 pcs)
29 | 1 | CH340N | U4 | SOP-8_L4.9-W3.9-P1.27-LS6.0-BL |  | LCSC
33 | 1 | STM32F103C8T6-Card | U15 | CONN-TH_L53.3-W22.9_STM32F103C8T6-CARD |  | LCSC
28 | 2 | TPS5450DDAR | U3,U8 | SOP-8_L4.9-W3.9-P1.27-LS6.0-BL-EP |  | LCSC
32 | 4 | ZX-XH2.54-8PLT | U11,U12,U13,U14 | CONN-SMD_8P-P2.50_ZX-XH2.54-8PLT-1 |  | LCSC
▼ 开关 (1 pcs)
26 | 1 | KCD1-104N | U1 | SW-TH_KCD1-104N |  | LCSC
▼ LED (2 pcs)
27 | 2 | DDW-HJG-Y1-I2 | U2,U5 | LED-SMD_L3.2-W2.8-LS3.5-FD |  | LCSC
▼ 保险丝 (1 pcs)
30 | 1 | 5A一次性保险丝-1206 | U7 | F1206 |  | LCSC
▼ 传感器 (1 pcs)
31 | 1 | JY61P | U9 | 维特智能JY61P
▼ USB接口 (1 pcs)
34 | 1 | TYPE-C 16PIN 2MD(073) | USB1 | USB-C-SMD_TYPE-C-6PIN-2MD-073 |  | LCSC
▼ 机械件 (4 pcs)
25 | 4 | M3螺丝 | SCREW1,SCREW2,SCREW3,SCREW4 | M3螺丝
总计元器件数量：72 pcs |  |  | 共 34 种物料

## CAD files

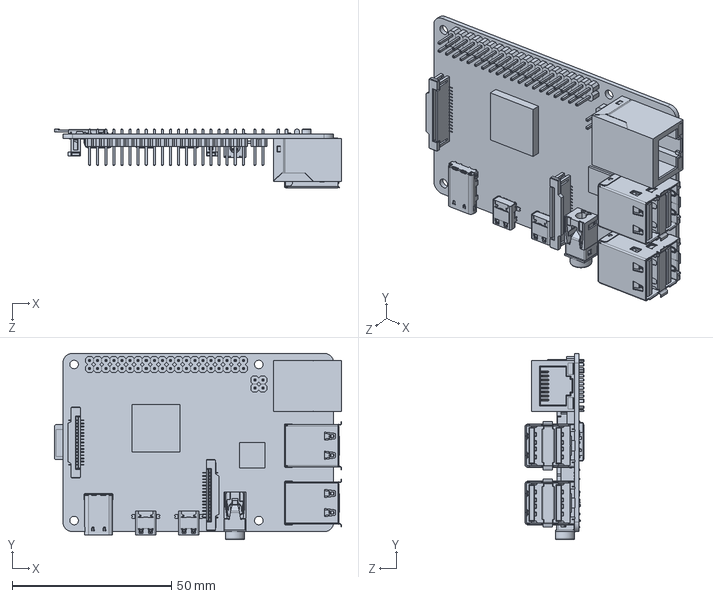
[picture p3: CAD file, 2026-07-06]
建模资料/pi外壳/raspberry_p4b_v001.SLDPRT
90.1 x 58.5 x 18.6 mm

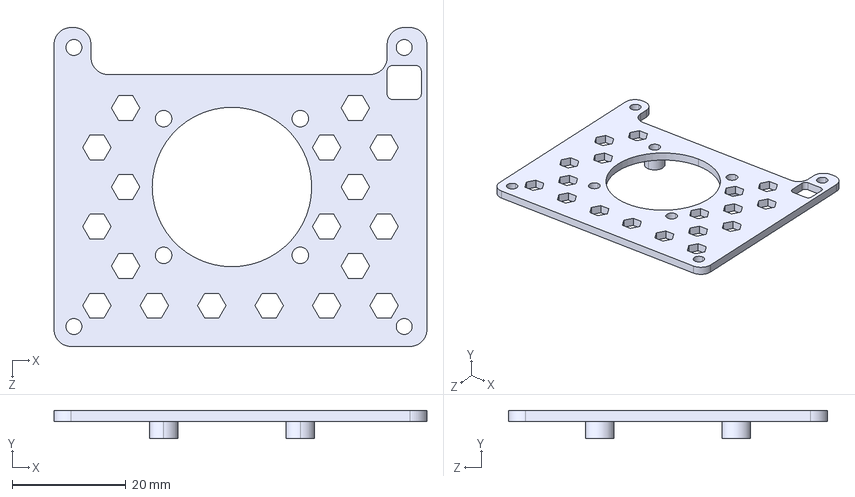
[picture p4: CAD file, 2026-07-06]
建模资料/小车装配体/pi/pi/树莓派4b顶壳.STEP
65.5 x 5.00 x 56.0 mm

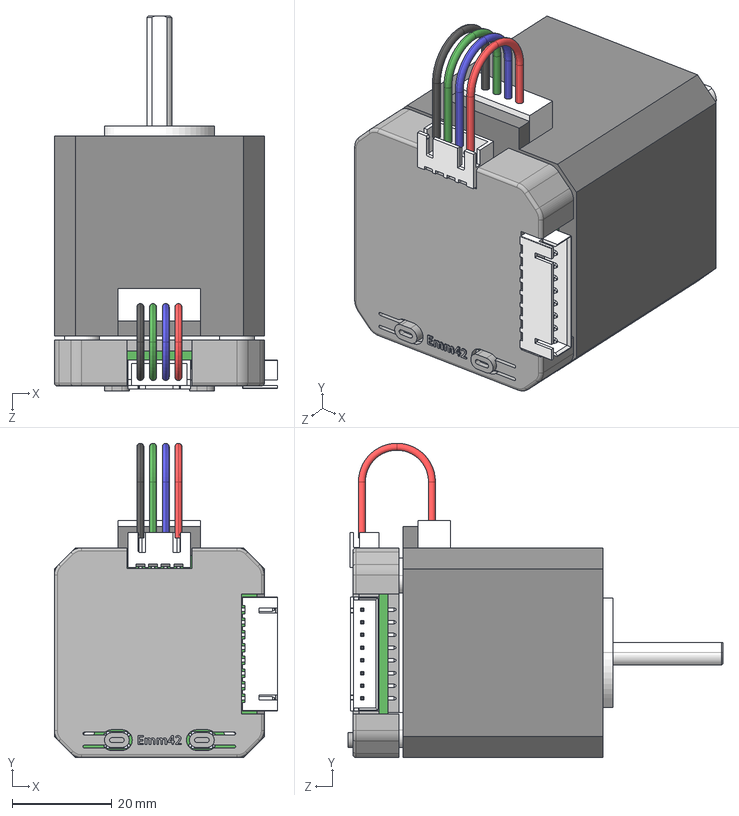
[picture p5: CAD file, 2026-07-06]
建模资料/小车装配体/ZDT_X42_L40Motor.STEP
44.7 x 62.9 x 75.0 mm
42_STEPPER_MOTOR
SHIM_3x7x3 x 4
ts-1145a-b-a_White.step x 2
User_Library-XH2_54-4P-AW.step
XH2.54-8P_H-0.step
Extruded.step
Extruded-1.step
M3x6mm_Phillips x 4
ZDT_X42_V1.2
WIRE_2.54

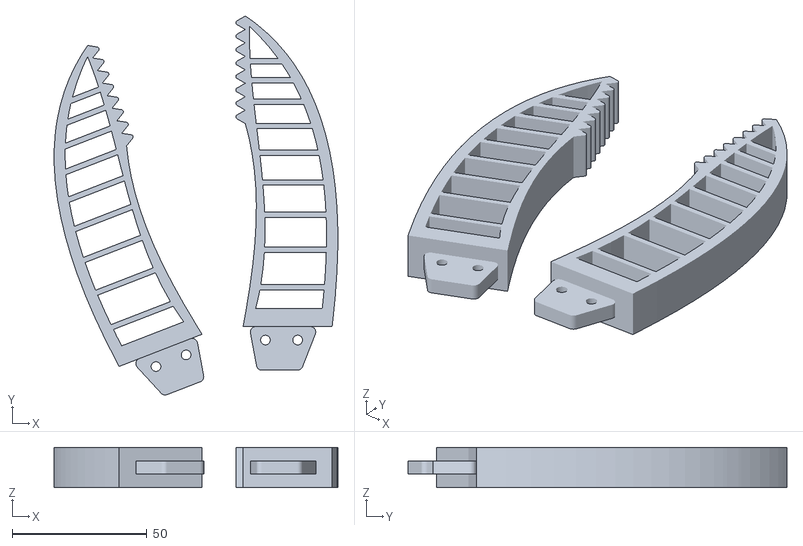
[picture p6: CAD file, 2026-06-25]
建模资料/机械爪b_modV3.STL
105.4 x 140.9 x 15.0

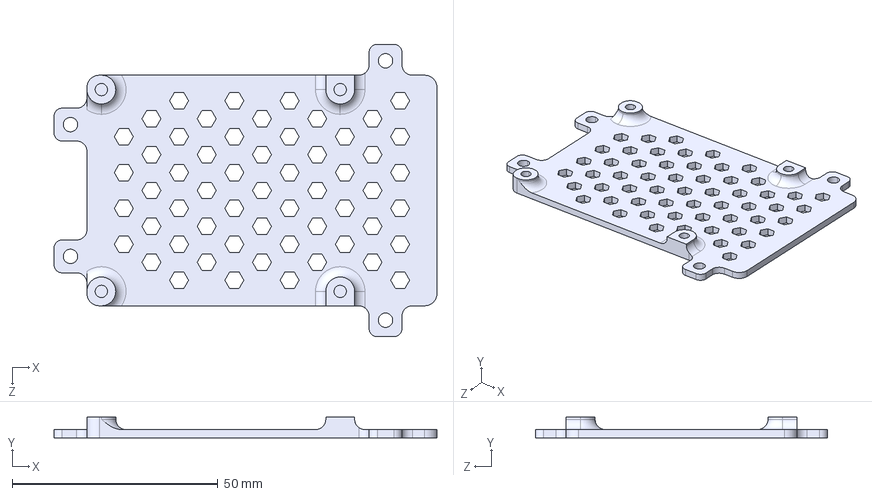
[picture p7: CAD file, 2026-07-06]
建模资料/小车装配体/pi/pi/树莓派4b底壳.STEP
93.0 x 5.00 x 71.0 mm

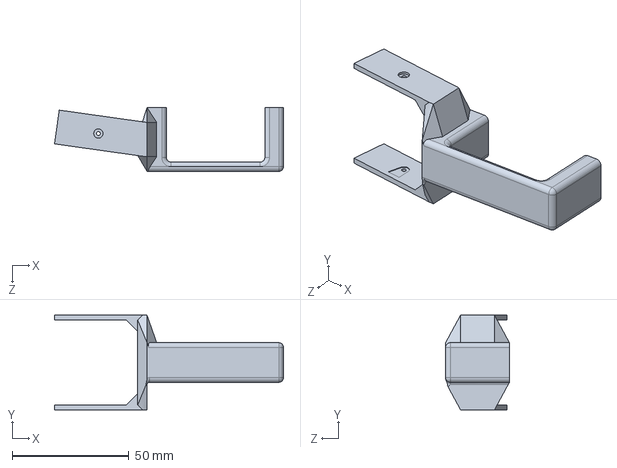
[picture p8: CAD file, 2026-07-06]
建模资料/小车装配体/相机支架.SLDPRT
98.1 x 40.5 x 27.3 mm

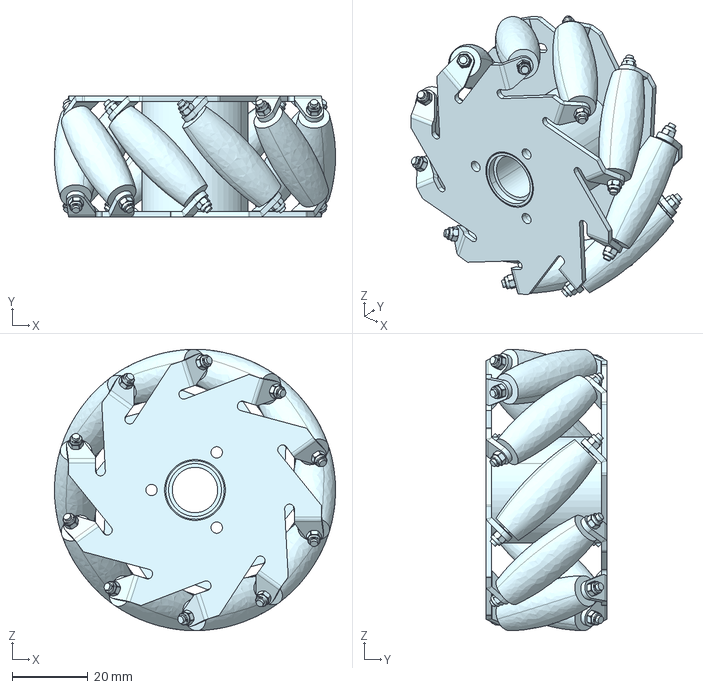
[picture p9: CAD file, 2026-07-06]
建模资料/小车装配体/75mm麦轮_右(客户图）.stp
74.4 x 32.0 x 74.5 mm

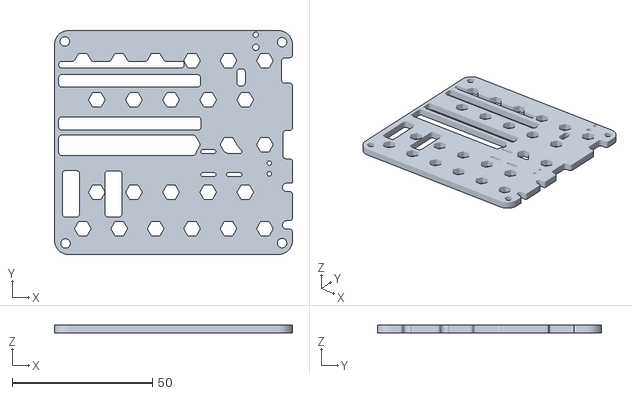
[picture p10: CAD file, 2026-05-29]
建模资料/物流搬运PCB单板底壳.stl
85.0 x 80.0 x 3.00

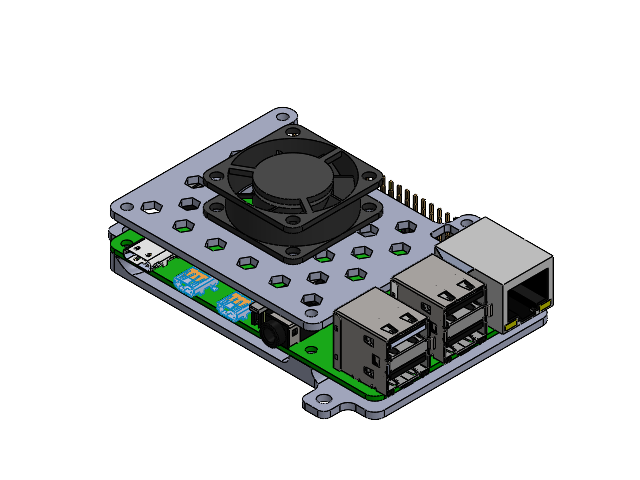
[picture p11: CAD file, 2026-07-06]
建模资料/pi外壳/树莓派.SLDASM
树莓派4b底壳
raspberry_p4b_v001
树莓派4b顶壳
fan 3030

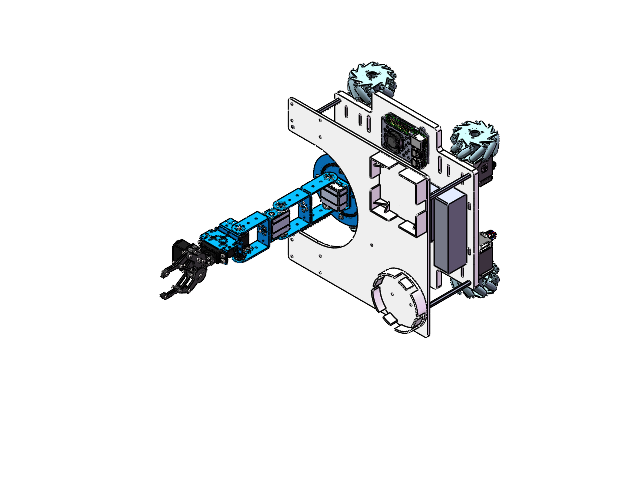
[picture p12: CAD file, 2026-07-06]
建模资料/小车装配体/装配体小车.SLDASM
底板一层V4
第二层(2)
圆形料盘
方形料框
42步进电机支架.step - 副本 (2) x 2
42步进电机支架.step - 副本 (3)
42步进电机支架.step - 副本
ts-1145a-b-a_White.step_1.STEP x 8
User_Library-XH2_54-4P-AW.step_1.STEP x 4
XH2.54-8P_H-0.step_1.STEP x 4
Extruded.step_1.STEP x 4
Extruded-1.step_1.STEP x 4
42_STEPPER_MOTOR_1.STEP x 4
SHIM_3x7x3_1.STEP x 16
M3x6mm_Phillips_1.STEP x 16
ZDT_X42_V1.2_1.STEP x 4
WIRE_2.54_1.STEP x 4
零件34^装配体1
铜柱 x 4
75mm麦轮_右(客户图） x 2
75mm麦轮_左(客户图） x 2
树莓派4b底壳
raspberry_p4b_v001
树莓派4b顶壳
fan 3030
Board~7Gnw.step
主机架反
螺孔小圆柱反 x 4
小圆柱反 x 3
小连杆反 x 4
抓反 x 4
摇杆1反
摇杆2反
cross recessed pan head screws gb_GB_CROSS_SCREWS_TYPE1 M3X16-16 H type-N x 7
cross recessed pan head screws gb_GB_CROSS_SCREWS_TYPE1 M3X10-10 H type-N x 4
cross recessed pan head screws gb_GB_CROSS_SCREWS_TYPE1 M3X5-5 H type-N x 4
hex nuts, style 1-grades ab gb_GB_FASTENER_NUT_SNAB1 M3-C x 11
prevailing torque type style 1 gb_GB_HEXAGON_TYPE9 M3-C x 7
MID_PLANT-VTS02_21_1 x 3
GEAR_BOX_LOWER_20_1 x 3
CHASSIS__UPPER82_23_1 x 3
C_TIEZHU_18_1 x 3
MADA_1_1 x 3
PRT0009_1_1_1 x 3
3KG-5CHI_19_1 x 3
3KG-Z1_1_1 x 3
Z2_9_1 x 3
Z3_9_1 x 3
Z4_35_1 x 3
PCB_3_1 x 3
PB28_1_1 x 12
P17_1_1 x 3
TONGTAO_9_1 x 3
TONG-2_1_1 x 3
Z4-1_26_1 x 3
TONGHUANG_7_1 x 3
DIANGPING_2_1 x 3
PRT0001_3 x 3
cross recessed pan head screws gb_GB_CROSS_SCREWS_TYPE1 M3X6-6 H type-C x 4
cross recessed countersunk head screws gb1_GB_CROSS_SCREWS_TYPE4 M3X8-6.35 H type-C x 13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

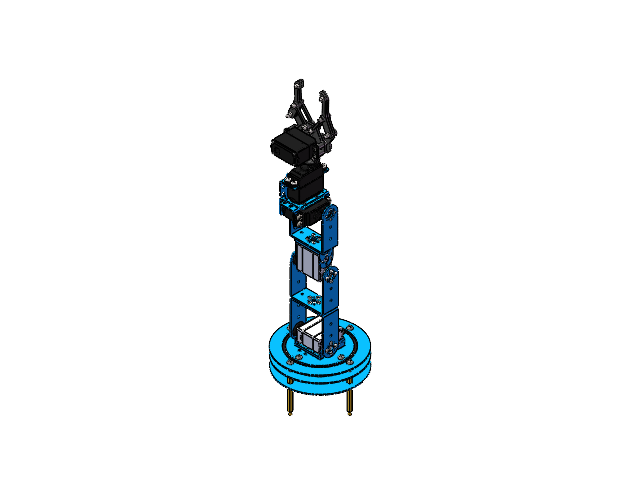
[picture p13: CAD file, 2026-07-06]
建模资料/小车装配体/三合一/三合一/三合一.IGS.SLDASM
主机架反
螺孔小圆柱反 x 4
小圆柱反 x 3
小连杆反 x 4
抓反 x 4
摇杆1反
摇杆2反
cross recessed pan head screws gb_GB_CROSS_SCREWS_TYPE1 M3X16-16 H type-N x 7
cross recessed pan head screws gb_GB_CROSS_SCREWS_TYPE1 M3X10-10 H type-N x 4
cross recessed pan head screws gb_GB_CROSS_SCREWS_TYPE1 M3X5-5 H type-N x 4
hex nuts, style 1-grades ab gb_GB_FASTENER_NUT_SNAB1 M3-C x 11
prevailing torque type style 1 gb_GB_HEXAGON_TYPE9 M3-C x 7
MID_PLANT-VTS02_21_1 x 3
GEAR_BOX_LOWER_20_1 x 3
CHASSIS__UPPER82_23_1 x 3
C_TIEZHU_18_1 x 3
MADA_1_1 x 3
PRT0009_1_1_1 x 3
3KG-5CHI_19_1 x 3
3KG-Z1_1_1 x 3
Z2_9_1 x 3
Z3_9_1 x 3
Z4_35_1 x 3
PCB_3_1 x 3
PB28_1_1 x 12
P17_1_1 x 3
TONGTAO_9_1 x 3
TONG-2_1_1 x 3
Z4-1_26_1 x 3
TONGHUANG_7_1 x 3
DIANGPING_2_1 x 3
PRT0001_3 x 3
cross recessed pan head screws gb_GB_CROSS_SCREWS_TYPE1 M3X6-6 H type-C x 4
cross recessed countersunk head screws gb1_GB_CROSS_SCREWS_TYPE4 M3X8-6.35 H type-C x 13
opensource_arm主舵盘_双轴 x 3
cross recessed pan head tapping screws gb_GB_CROSS_SCREWS_TYPE128 ST2.9X6.5 H C-C
hex nuts, style 1-grades ab gb_GB_FASTENER_NUT_SNAB1 M3-N x 2
KA2.5 x 2
安装连接块反 x 2
BA_5 x 26
hex nuts, style 1-grades ab gb_GB_FASTENER_NUT_SNAB1 M4-C x 12
cross recessed pan head screws gb_GB_CROSS_SCREWS_TYPE1 M4X8-8 H type-C x 8
miniature radial ball bearings gb_Rolling bearings FF619-3 GB 7218-1995
多功能支架 x 2
opensource_armSG_SZ x 2
opensource_armZK_SZ x 2
opensource_armDG_SZ x 2
opensource_armGE_SZ x 2
opensource_arm副舵盘_双轴 x 2
opensource_arm带垫片自攻螺丝 x 2
opensource_DUOPAN x 2
cross recessed pan head screws gb_GB_CROSS_SCREWS_TYPE1 M2X6-6 H type-C x 4
hex nuts, style 1-grades ab gb_GB_FASTENER_NUT_SNAB1 M2-C x 4
opensource_arm长U_厚 x 3
opensource_arm小U_一头为方
opensource_arm小圆盘 x 2
opensource_arm4-21侧盖
M2_MechanicalScrew x 4
hex nuts, style 1-grades ab gb_GB_FASTENER_NUT_SNAB1 M2-N x 4
deep groove ball bearings gb_Rolling bearings 61815 GB276-94,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

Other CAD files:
建模资料/小车装配体/3D_PCB1无零件.SLDASM
建模资料/小车装配体/三合一/三合一/摇杆1反.SLDPRT
建模资料/小车装配体/三合一/三合一/standoff.SLDPRT
建模资料/相机支架(1).STL
建模资料/小车装配体/三合一/三合一/BA_5.SLDPRT
建模资料/pi外壳/fan 3030.SLDPRT
建模资料/pi外壳/树莓派4b底壳.SLDPRT
建模资料/pi外壳/树莓派4b顶壳.SLDPRT
建模资料/小车装配体/42步进电机支架.step - 副本 (2).SLDPRT
建模资料/小车装配体/42步进电机支架.step - 副本 (3).SLDPRT
建模资料/小车装配体/42步进电机支架.step - 副本.SLDPRT
建模资料/小车装配体/42步进电机支架.step.SLDPRT
建模资料/小车装配体/75mm麦轮_右(客户图）.SLDPRT
建模资料/小车装配体/75mm麦轮_左(客户图）.SLDPRT
建模资料/小车装配体/75mm麦轮_左(客户图）.stp
建模资料/小车装配体/ZDT_X42_L40Motor.SLDASM
建模资料/小车装配体/pi/pi/fan 3030.SLDPRT
建模资料/小车装配体/pi/pi/树莓派4b底壳.SLDPRT
建模资料/小车装配体/pi/pi/树莓派4b顶壳.SLDPRT
建模资料/小车装配体/三合一/三合一/3KG-5CHI_19_1.SLDPRT
建模资料/小车装配体/三合一/三合一/3KG-Z1_1_1.SLDPRT
建模资料/小车装配体/三合一/三合一/CHASSIS__UPPER82_23_1.SLDPRT
建模资料/小车装配体/三合一/三合一/C_TIEZHU_18_1.SLDPRT
建模资料/小车装配体/三合一/三合一/DIANGPING_2_1.SLDPRT
建模资料/小车装配体/三合一/三合一/GEAR_BOX_LOWER_20_1.SLDPRT
建模资料/小车装配体/三合一/三合一/KA2.5.SLDPRT
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

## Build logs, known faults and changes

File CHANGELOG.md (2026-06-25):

# 个性化物流小车 - 更新日志

> 自动维护，每天由星尘光检查项目更新情况并记录。

---

## v0.1.0 — 初始建立（2026-05-22）

- 项目初始化：添加 README、LICENSE（MIT）、.gitignore
- 代码目录结构搭建：陀螺仪 UART 驱动（JY61P）、传感器数值函数文档
- 新增 PCB 目录，添加电路板设计文件
- 添加 VibeCoding 目录：姿态模块资料包、传感器官方文档、麦轮框架项目资料

## v0.1.1 — 代码重构 & 建模资料（2026-05-29）

- 代码目录结构重整，新增 STM32 传感器驱动库 `smart_logistics_car_integrated`
  - 包含：JY61P 陀螺仪、ATK-MS53L1M 激光测距、VL53L1X API、ZDT 步进电机 Modbus-RTU 驱动
  - 麦伦运动学模块（mecanum_kinematics）、电机管理（motor_manager）、底盘控制（chassis_control）
- 新增建模资料：树莓派 4B 3D 模型（SLDPRT/SLDASM/STEP）

## v0.1.2 — 文档补充 & 清理（2026-06-04）

- 补充麦轮框架资料：麦伦运动控制系统设计文档 V4Pro/V5Pro、代码生成提示词
- 优化项目文档
- 清理冗余备份文件
- 移除临时代码运行文件 tempCodeRunnerFile.python

---

## v0.1.3 — 项目同步与文档更新（2026-06-17）

- 项目同步，文档更新
- 里程碑：四六级备考期后首次恢复提交

---

## 待观察

- 距上次提交（2026-06-17）已过 8 天，暂无新提交
- 期末周进行中，项目暂时搁置属正常节奏
- 下一目标：推进底盘控制与传感器集成测试

*本日志由星尘光自动维护，每日更新。*

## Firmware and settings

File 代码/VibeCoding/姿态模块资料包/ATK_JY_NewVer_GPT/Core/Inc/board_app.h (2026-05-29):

#ifndef BOARD_APP_H
#define BOARD_APP_H

#include "main.h"
#include "imu_app.h"
#include "laser_app.h"
#include <stdint.h>

#ifdef __cplusplus
extern "C" {
#endif

#define BOARD_SENSOR_FAULT_IMU_INVALID       (1UL << 0)
#define BOARD_SENSOR_FAULT_IMU_NOT_CALIB     (1UL << 1)
#define BOARD_SENSOR_FAULT_LASER_INVALID     (1UL << 2)
#define BOARD_SENSOR_FAULT_LASER_TOO_CLOSE   (1UL << 3)

typedef struct
{
    float car_yaw_est_deg;
    float car_pitch_deg;
    float car_roll_deg;
    float gyro_yaw_dps;
    float acc_forward_g;
    float acc_right_g;
    float acc_down_g;
    float temperature_c;
    uint8_t imu_valid;
    uint8_t imu_calibrated;

    uint16_t laser_raw_distance_mm;
    uint16_t laser_filtered_distance_mm;
    uint8_t laser_ok;
    uint8_t laser_is_warning;
    uint8_t laser_is_slow;
    uint8_t laser_is_too_close;

    uint32_t sensor_fault_flags;
    uint32_t timestamp_ms;
} SENSOR_Snapshot_t;

extern volatile SENSOR_Snapshot_t g_sensor_snapshot;
extern volatile uint32_t g_sensor_fault_flags;

void Board_App_Init(void);
void Board_App_Loop(void);
void Board_App_GetSnapshot(SENSOR_Snapshot_t *out);
uint32_t Board_App_GetFaultFlags(void);
void Board_App_I2C1_BusRecover(void);
void Board_App_UartRxCpltCallback(UART_HandleTypeDef *huart);

#ifdef __cplusplus
}
#endif

#endif /* BOARD_APP_H */

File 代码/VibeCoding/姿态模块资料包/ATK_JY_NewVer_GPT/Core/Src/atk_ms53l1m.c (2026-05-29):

#include "atk_ms53l1m.h"
#include <string.h>

#ifndef __weak
#define __weak __attribute__((weak))
#endif

/* VL53L1X register addresses used by the lightweight fallback platform layer. */
#define VL53L1X_REG_GPIO_TIO_HV_STATUS       (0x0031U)
#define VL53L1X_REG_SYSTEM_INTERRUPT_CLEAR   (0x0086U)
#define VL53L1X_REG_SYSTEM_MODE_START        (0x0087U)
#define VL53L1X_REG_RESULT_RANGE_STATUS      (0x0089U)
#define VL53L1X_REG_RESULT_DISTANCE_MM       (0x0096U)
#define VL53L1X_REG_FIRMWARE_SYSTEM_STATUS   (0x00E5U)
#define VL53L1X_REG_IDENTIFICATION_MODEL_ID  (0x010FU)

static void atk_mark_error(ATK_MS53L1M_Device_t *dev, ATK_MS53L1M_Error_t err)
{
    if (dev == 0)
    {
        return;
    }
    dev->last_error = err;
    dev->error_count++;
    dev->consecutive_error_count++;
    if ((err == ATK_MS53L1M_ERROR_TIMEOUT) || (dev->consecutive_error_count >= 3U))
    {
        dev->state = ATK_MS53L1M_STATE_ERROR;
        dev->distance.valid = 0U;
    }
}

static uint16_t atk_abs_diff_u16(uint16_t a, uint16_t b)
{
    return (a >= b) ? (uint16_t)(a - b) : (uint16_t)(b - a);
}

static uint16_t atk_median_u16(const uint16_t *data, uint8_t count)
{
    uint16_t tmp[ATK_MS53L1M_MEDIAN_WINDOW];
    uint8_t i;
    uint8_t j;

    for (i = 0U; i < count; i++)
    {
        tmp[i] = data[i];
    }

    for (i = 0U; i < count; i++)
    {
        for (j = (uint8_t)(i + 1U); j < count; j++)
        {
            if (tmp[j] < tmp[i])
            {
                uint16_t swap = tmp[i];
                tmp[i] = tmp[j];
                tmp[j] = swap;
            }
        }
    }

    return tmp[count / 2U];
}

static uint16_t atk_avg_u16(const uint16_t *data, uint8_t count)
{
    uint8_t i;
    uint32_t sum = 0U;

    for (i = 0U; i < count; i++)
    {
        sum += data[i];
    }

    if (count == 0U)
    {
        return 0U;
    }
    return (uint16_t)(sum / count);
}

static uint8_t atk_range_is_valid(uint16_t mm)
{
    return ((mm >= ATK_MS53L1M_MIN_VALID_MM) && (mm <= ATK_MS53L1M_MAX_VALID_MM)) ? 1U : 0U;
}

static void atk_accept_distance(ATK_MS53L1M_Device_t *dev, uint16_t accepted_mm, uint32_t now_ms)
{
    dev->filter.avg_window[dev->filter.avg_index] = accepted_mm;
    dev->filter.avg_index = (uint8_t)((dev->filter.avg_index + 1U) % ATK_MS53L1M_AVG_WINDOW);
    if (dev->filter.avg_count < ATK_MS53L1M_AVG_WINDOW)
    {
        dev->filter.avg_count++;
    }

    dev->filter.last_accepted_mm = accepted_mm;
    dev->distance.filtered_distance_mm = atk_avg_u16(dev->filter.avg_window, dev->filter.avg_count);
    dev->distance.last_valid_distance_mm = dev->distance.filtered_distance_mm;
    dev->distance.valid = 1U;
    dev->distance.is_warning = (dev->distance.filtered_distance_mm <= ATK_MS53L1M_WARN_DISTANCE_MM) ? 1U : 0U;
    dev->distance.is_slow = (dev->distance.filtered_distance_mm <= ATK_MS53L1M_SLOW_DISTANCE_MM) ? 1U : 0U;
    dev->distance.is_too_close = (dev->filter.close_confirm_count >= ATK_MS53L1M_STOP_CONFIRM_COUNT) ? 1U : 0U;
    dev->distance.last_valid_ms = now_ms;
    dev->distance.sample_count++;
    dev->last_error = ATK_MS53L1M_ERROR_NONE;
    dev->consecutive_error_count = 0U;
    dev->state = ATK_MS53L1M_STATE_RUNNING;
}

static HAL_StatusTypeDef atk_write_u8(ATK_MS53L1M_Device_t *dev, uint16_t reg, uint8_t value)
{
    return HAL_I2C_Mem_Write(dev->i2c,
                             dev->addr_hal,
                             reg,
                             I2C_MEMADD_SIZE_16BIT,
                             &value,
                             1U,
                             ATK_MS53L1M_I2C_TIMEOUT_MS);
}

static HAL_StatusTypeDef atk_read_u8(ATK_MS53L1M_Device_t *dev, uint16_t reg, uint8_t *value)
{
    return HAL_I2C_Mem_Read(dev->i2c,
                            dev->addr_hal,
                            reg,
                            I2C_MEMADD_SIZE_16BIT,
                            value,
                            1U,
                            ATK_MS53L1M_I2C_TIMEOUT_MS);
}

static HAL_StatusTypeDef atk_read_u16_be(ATK_MS53L1M_Device_t *dev, uint16_t reg, uint16_t *value)
{
    uint8_t rx[2];
    HAL_StatusTypeDef ret;

    ret = HAL_I2C_Mem_Read(dev->i2c,
                           dev->addr_hal,
                           reg,
                           I2C_MEMADD_SIZE_16BIT,
                           rx,
                           2U,
                           ATK_MS53L1M_I2C_TIMEOUT_MS);
    if (ret == HAL_OK)
    {
        *value = (uint16_t)(((uint16_t)rx[0] << 8U) | rx[1]);
    }
    return ret;
}

ATK_MS53L1M_Result_t ATK_MS53L1M_Init(ATK_MS53L1M_Device_t *dev, I2C_HandleTypeDef *i2c, uint32_t now_ms)
{
    HAL_StatusTypeDef hal_ret;

    if ((dev == 0) || (i2c == 0))
    {
        return ATK_MS53L1M_RESULT_PARAM_ERROR;
    }

    memset(dev, 0, sizeof(*dev));
    dev->i2c = i2c;
    dev->addr_7bit = ATK_MS53L1M_I2C_ADDR_7BIT;
    dev->addr_hal = ATK_MS53L1M_I2C_ADDR_HAL;
    dev->state = ATK_MS53L1M_STATE_UNINIT;
    dev->last_poll_ms = now_ms;
    dev->last_recover_ms = now_ms;

    hal_ret = HAL_I2C_IsDeviceReady(dev->i2c, dev->addr_hal, 2U, ATK_MS53L1M_I2C_TIMEOUT_MS);
    if (hal_ret != HAL_OK)
    {
        dev->state = ATK_MS53L1M_STATE_ERROR;
        dev->last_error = ATK_MS53L1M_ERROR_I2C;
        dev->error_count = 1U;
        return ATK_MS53L1M_RESULT_I2C_ERROR;
    }

    return ATK_MS53L1M_StartDefault(dev, now_ms);
}

ATK_MS53L1M_Result_t ATK_MS53L1M_StartDefault(ATK_MS53L1M_Device_t *dev, uint32_t now_ms)
{
    HAL_StatusTypeDef hal_ret;

    if ((dev == 0) || (dev->i2c == 0))
    {
        return ATK_MS53L1M_RESULT_PARAM_ERROR;
    }

    hal_ret = ATK_MS53L1M_PlatformStartRanging(dev);
    if (hal_ret != HAL_OK)
    {
        atk_mark_error(dev, ATK_MS53L1M_ERROR_I2C);
        return ATK_MS53L1M_RESULT_I2C_ERROR;
    }

    memset(&dev->filter, 0, sizeof(dev->filter));
    memset(&dev->distance, 0, sizeof(dev->distance));
    dev->state = ATK_MS53L1M_STATE_RUNNING;
    dev->last_error = ATK_MS53L1M_ERROR_NONE;
    dev->consecutive_error_count = 0U;
    dev->last_poll_ms = now_ms;
    return ATK_MS53L1M_RESULT_OK;
}

ATK_MS53L1M_Result_t ATK_MS53L1M_ReadDistanceRaw(ATK_MS53L1M_Device_t *dev, uint16_t *distance_mm)
{
    HAL_StatusTypeDef hal_ret;

    if ((dev == 0) || (dev->i2c == 0) || (distance_mm == 0))
    {
        return ATK_MS53L1M_RESULT_PARAM_ERROR;
    }

    hal_ret = ATK_MS53L1M_PlatformReadDistance(dev, distance_mm);
    if (hal_ret != HAL_OK)
    {
        atk_mark_error(dev, ATK_MS53L1M_ERROR_I2C);
        return ATK_MS53L1M_RESULT_I2C_ERROR;
    }

    (void)ATK_MS53L1M_PlatformClearInterrupt(dev);
    return ATK_MS53L1M_RESULT_OK;
}
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

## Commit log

2026-05-22 Initial commit: 添加README、LICENSE、.gitignore
2026-05-22 更新.gitignore，添加代码基础文件
2026-05-22 添加代码文档和陀螺仪驱动
2026-05-22 添加PCB目录和图片等资源
    [搬运小车BOM分类整理.xlsx]
2026-05-22 更新.gitignore，添加建模资料（3D模型）
    [圆形料盘.SLDPRT, 底板一层V4.SLDPRT, 方形料框.SLDPRT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]
2026-05-29 refactor: 代码目录结构重整 + 新增STM32传感器驱动库 & 建模文件
    [物流搬运PCB单板底壳.stl]
2026-06-04 更新：补充麦轮框架资料、优化项目文档、清理冗余备份文件
2026-06-04 清理：移除临时代码运行文件 tempCodeRunnerFile.python
2026-06-17 chore: 项目同步与文档更新
    [相机支架(1).STL]
2026-06-25 chore: 更新工程文档 & 新增机械爪建模
    [机械爪b_modV3.SLDPRT, 机械爪b_modV3.STL]
2026-06-27 feat: 新增石山版STM32CubeIDE完整工程 & 工程纠错文档
2026-06-27 chore: 新增6月2日存量备份工程 smart_logistics_car_integrated_62backup
2026-06-28 chore: 新增628问题审查文档 & 移除临时文件
2026-06-28 chore: 清理旧工程并新增审查文档
    [机械爪b_modV2.SLDPRT]
2026-07-06 ✨ 新增629新工程与汇报资料，清理旧审查文档
2026-07-06 🔄 更新汇报PPT，新增树莓派主控修改方案
2026-07-06 📦 新增装配体3D模型文件与建模资料
    [3D_PCB1无零件.SLDASM, 3KG-5CHI_19_1.SLDPRT, 3KG-Z1_1_1.SLDPRT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]
2026-07-07 🧹 清理旧备份与SLDPRT模型文件，新增小车外壳与装配体建模资料
    [3D_PCB1无零件.SLDASM, 3KG-5CHI_19_1.SLDPRT, 3KG-Z1_1_1.SLDPRT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]
